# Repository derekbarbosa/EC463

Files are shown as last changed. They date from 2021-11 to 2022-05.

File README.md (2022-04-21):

<div align="center">

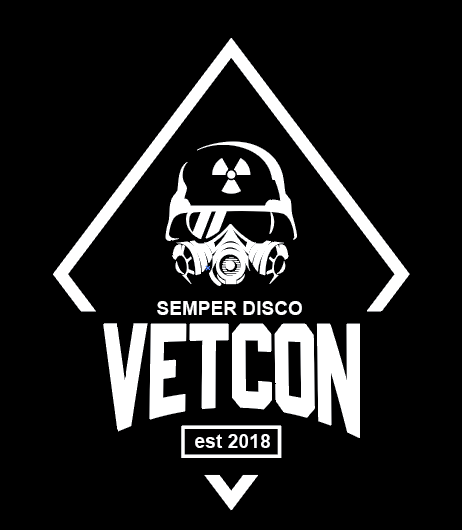
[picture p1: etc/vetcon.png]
  
  <h1> :skull: VETCON BADGE :skull: </h1>
  
  <p>
    TEAM 32 <span> · </span>2021-2022  
  </p>
  <p>
  SEMPER DISCO
  </p>

<!-- Badges -->
<p>
  <a href="https://github.com/derekbarbosa/EC463/graphs/contributors">
    
  </a>
  <a href="">
    
  </a>
  <a href="https://github.com/derekbarbosa/EC463/network/members">
    
  </a>
  <a href="https://github.com/derekbarbosa/EC463/issues">
    
  </a>
  <a href="https://github.com/derekbarbosa/EC463/blob/main/LICENSE">
    
  </a>
</p>

<h3>
  Quick Links!
</h3>
<h4>
    <a href="PLACEHOLDER">View Demo</a>
  <span> · </span>
    <a href="notes/README_Engineering.md">Quick Start Guide</a>
  <span> · </span>
    <a href="notes/README_HARDWARE.md">Hardware Guide</a>
  <span> · </span>
    <a href="notes/README_SOFTWARE.md">Software Guide</a>
</h4>

</div>

<br />

<!-- Table of Contents -->
# :notebook_with_decorative_cover: Table of Contents

- [:notebook_with_decorative_cover: Table of Contents](#notebook_with_decorative_cover-table-of-contents)
  - [:star2: About the Project](#star2-about-the-project)
    - [:label: Current Directory Structure](#label-current-directory-structure)
    - [:camera: Screenshots](#camera-screenshots)
    - [:space_invader: Tech Stack](#space_invader-tech-stack)
    - [:dart: Features](#dart-features)
      - [Embedded](#embedded)
      - [Minigames](#minigames)
  - [:toolbox: Getting Started](#toolbox-getting-started)
    - [:running: Quick(ly) Start!](#running-quickly-start)
  - [:eyes: Usage](#eyes-usage)
  - [:warning: License](#warning-license)
  - [:handshake: Contact](#handshake-contact)
  - [:gem: Acknowledgements](#gem-acknowledgements)

<!-- About the Project -->
## :star2: About the Project

### :label: Current Directory Structure
<a href="pcb/">pcb</a> – All PCB/eCAD files and schematics. Includes manufacturing .gbr files

<a href="enclosures/">enclosures</a> – All CAD files and schematics for the PCB enclosure. 

<a href="platformio/">platformio</a> – All code/firmware files concerning the MSP430 development board

<a href="notes/">notes</a> – Inital interview notes, MSP Documentation, useful infographics, additional READMEs

<a href="minigames/">minigames</a> – All code regarding Games 1, 2, and 3 (with CMake Files)

<a href="reports/">reports</a> – All previous reports for the 2021-2022 semester

<a href="derek/">derek</a> – Derek's personal folder for logbook maintenance

<a href="kircher/">kircher</a> – John's personal folder for logbook maintenance

<a href="etc/">etc</a> – Asset storage (logos, etc.)

<!-- Screenshots -->
### :camera: Screenshots

<div align="center"> 
  <p> PlatformIO VSCode Plugin "Home" Page </p>
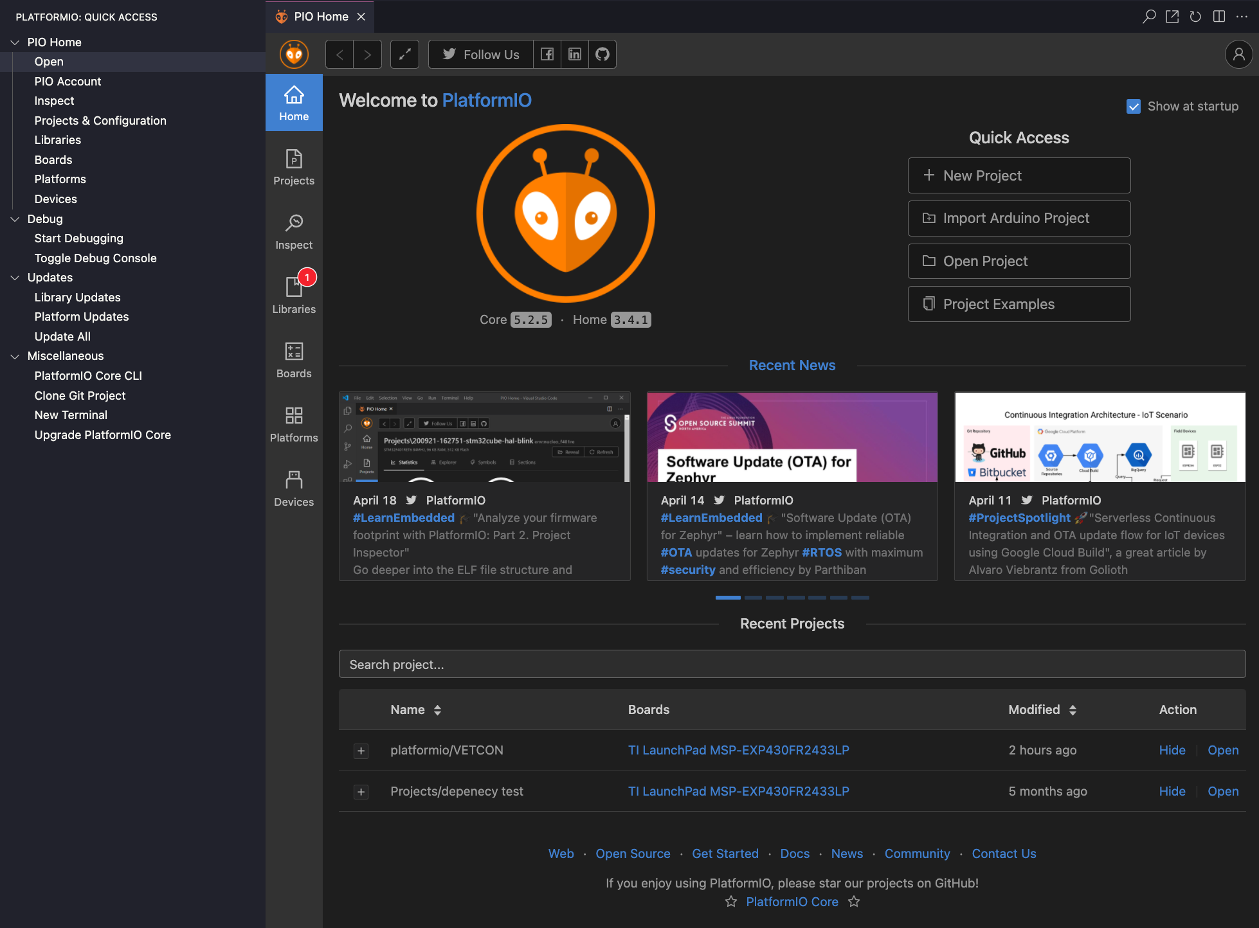
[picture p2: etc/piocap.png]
PIO Home Page
  
</div>

<div align="center"> 
  <p> Sample Terminal Menu via Serial </p>
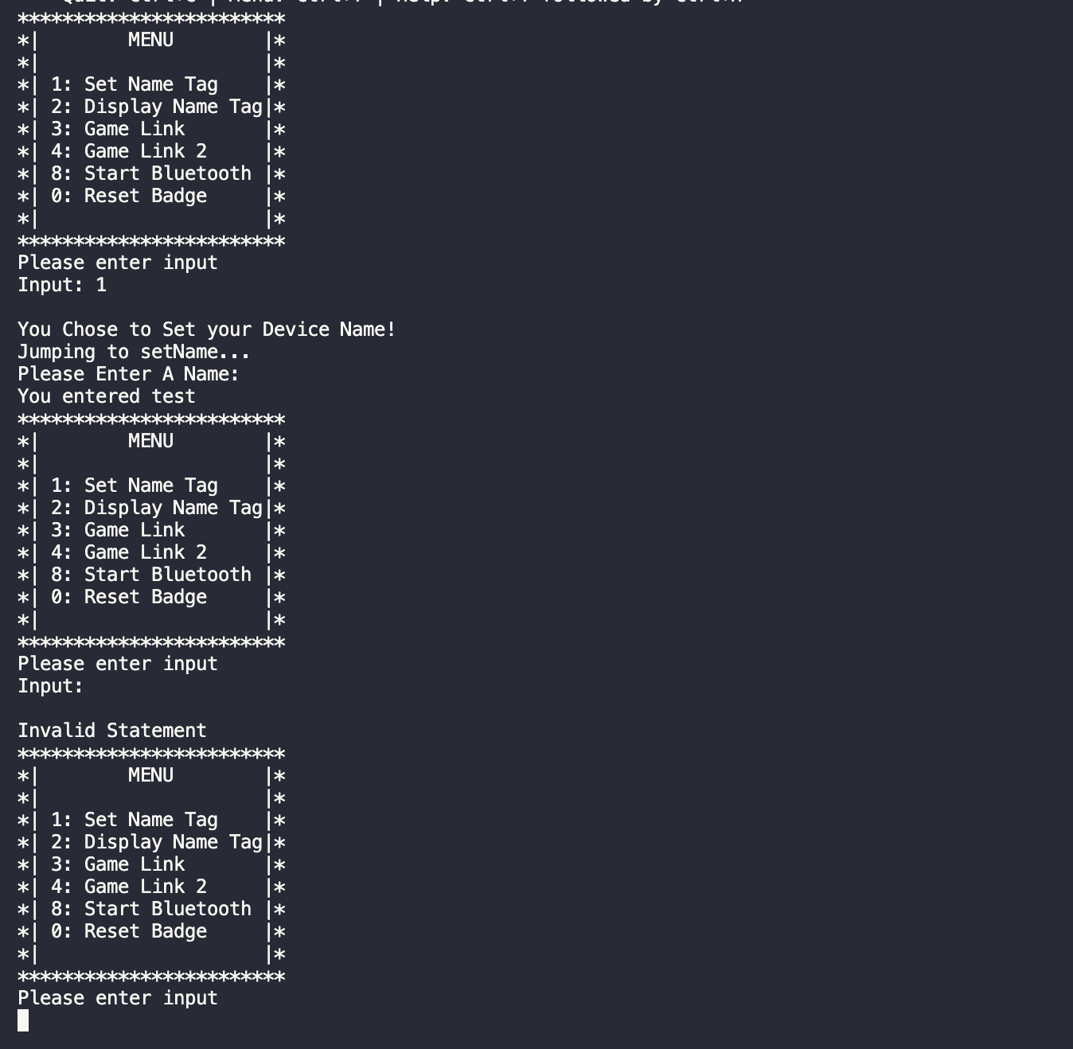
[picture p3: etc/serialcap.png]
Serial Terminal
  
</div>

<div align="center"> 
  <p> Minigame #1 "Dino Run"</p>
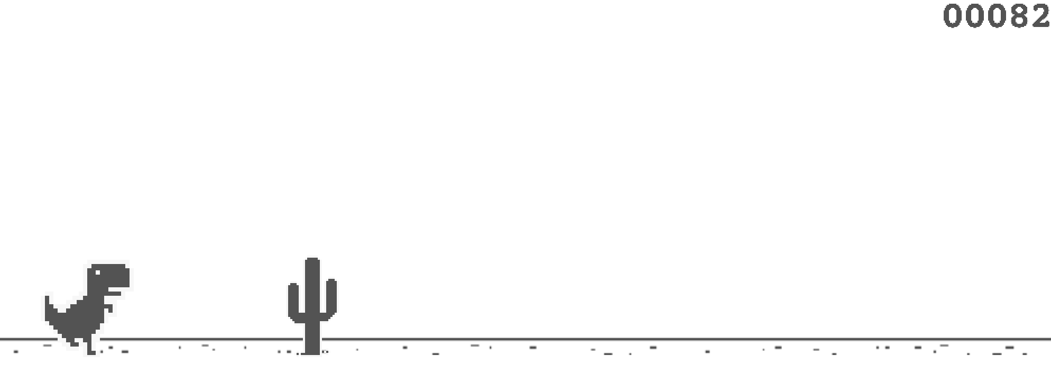
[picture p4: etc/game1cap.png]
Game 1
  
</div>

<div align="center"> 
  <p> Minigame #2 "Coin Flip" </p>
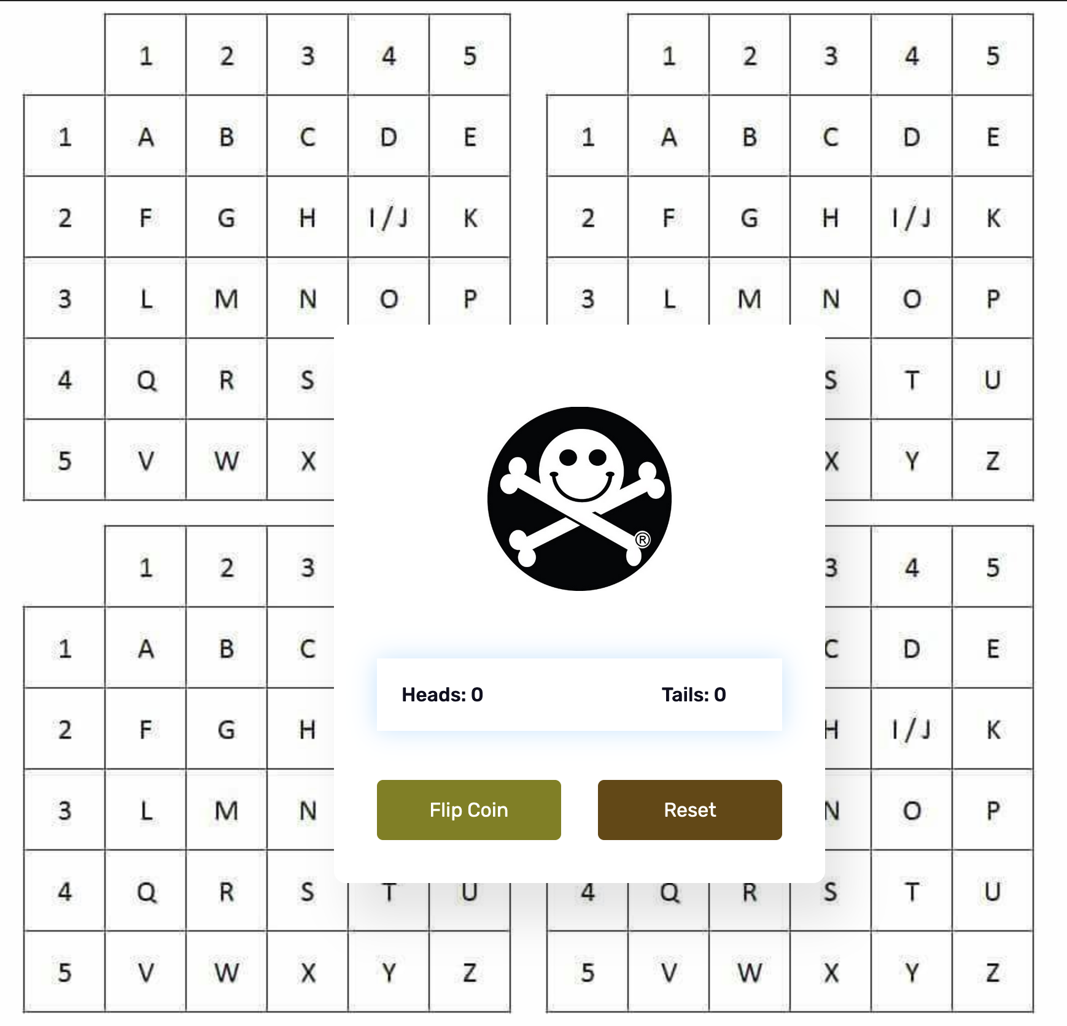
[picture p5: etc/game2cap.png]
Game 2
  
</div>
<div align="center"> 
  <p> Minigame #3 "Text-based adventure" </p>
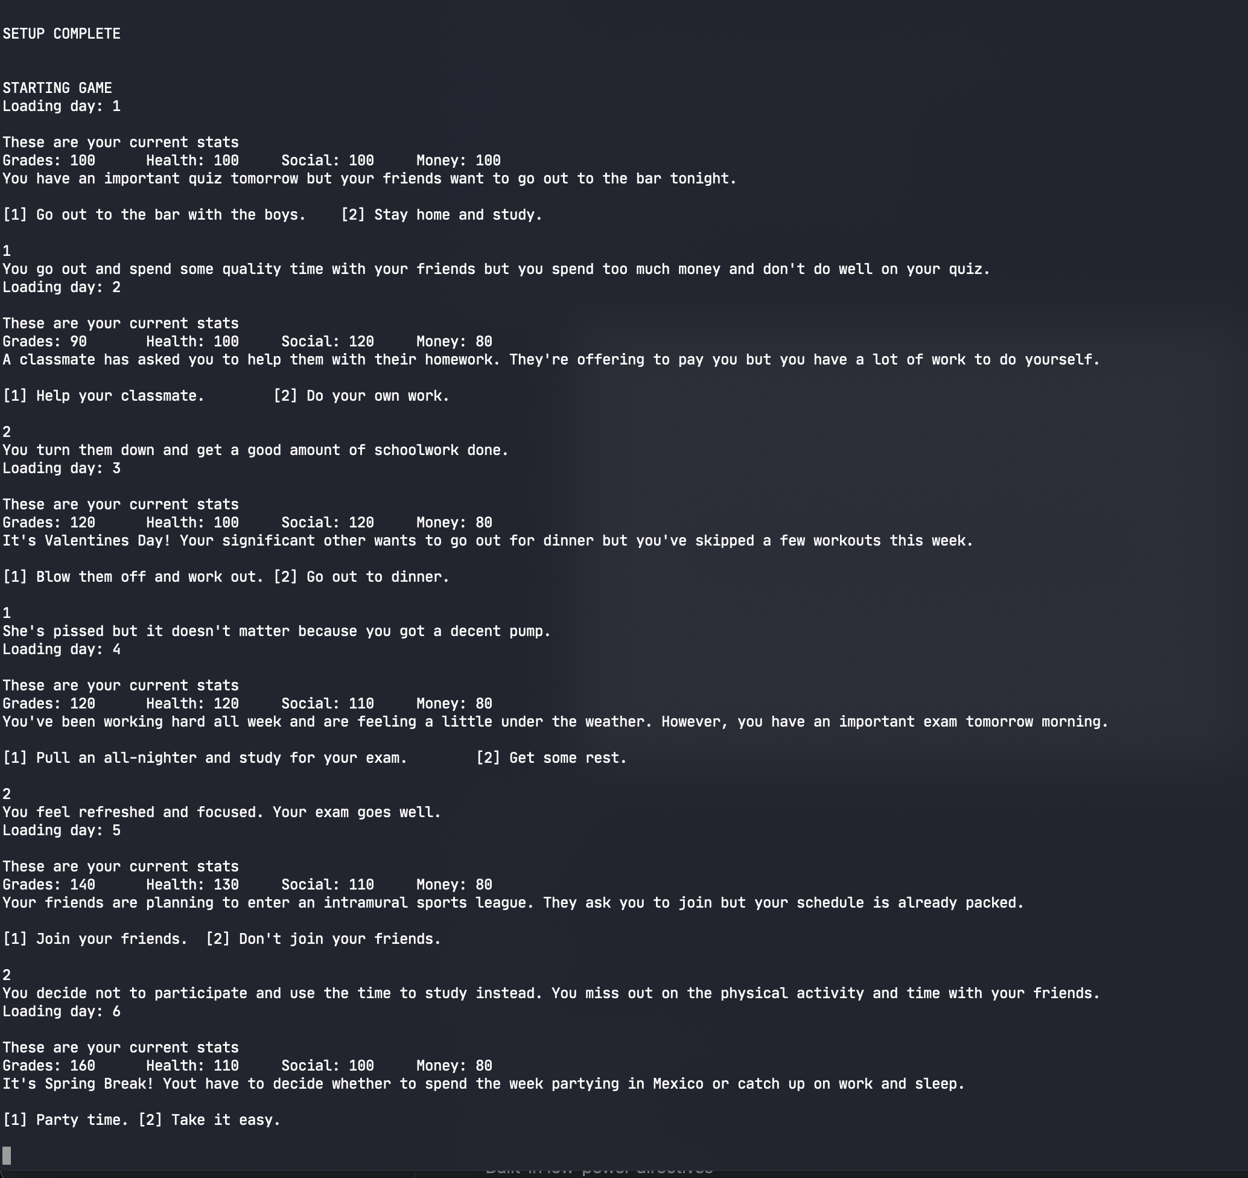
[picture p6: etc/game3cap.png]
Game 3
  
</div>

<!-- TechStack -->
### :space_invader: Tech Stack

<details>
  <summary>Embedded</summary>
  <ul>
    <li><a href="https://www.cplusplus.com/">C++</a></li>
    <li><a href="https://piolabs.com/company/about.html">PIOLabs</a></li>
    <li><a href="PlatformIO">PlatformIO</a></li>
    <li><a href="https://sourceforge.net/projects/mspgcc/">GCC Toolchain for MSP430 by TI</a></li>
    <li><a href="https://energia.nu/reference/">Energia Wiring-based Framework</a></li>
    <li><a href="https://registry.platformio.org/tools/platformio/tool-dslite">Uniflash Flash Tool for TI MCUs</a></li>
    <li><a href="http://wiring.org.co/">Wiring MCU Framework</a></li>
  </ul>
</details>

<details>
  <summary>Minigames</summary>
  <ul>
    <li><a href="https://phaser.io/">Phaser</a></li>
    <li><a href="https://webpack.js.org/">Webpack</a></li>
    <li><a href="https://www.typescriptlang.org/">Typescript</a></li>
    <li><a href="https://enable3d.io/">Enable3D</a></li>
    <li><a href="https://www.javascript.com/">Javascript</a></li>
    <li><a href="https://developer.mozilla.org/en-US/docs/Glossary/HTML5">HTML5</a></li>    
    <li><a href="https://cmake.org/">CMake</a></li>
  </ul>
</details>

<!-- Features -->
### :dart: Features

#### Embedded
- Interactive Shell/Terminal "UI"
- Customizeable
- Built-in LED Toggles
- Bluetooth Capable!
- Built-in low-power directives

#### Minigames
<details>
<summary> Game 1 </summary>
<ul>
<li> Interactive 'runner' game </li>
<li> Obfustication of source using Webpack and Babel for compilation</li>
<li> Hidden 'secrets' ;) </li>
</ul>
</details>
<details>
<summary> Game 2 </summary>
<ul>
<li> Interactive UI elements</li>
<li> Fluid animation using CSS! </li>
<li> Lightweight in-line JS </li>
<li> Built-in cookie storage and retrieval</li>
<li> Hidden 'secrets' ;) </li>
</ul>
</details>
<details>
<summary> Game 3</summary>
<ul>
<li> Interactive decision-based RPG-like text adventure </li>
<li> Open-ended Game Engine with Global Update features for future development and hackability </li>
<li> Text Engine incorporated at Compile-Time with simple .tsv formatting </li>
<li> Built-in undetectable "malware" with std::Threads </li>
<li> Hidden 'secrets' ;) </li>
</ul>
</details>

<!-- Getting Started -->
## 	:toolbox: Getting Started

<!-- Run Locally -->
### :running: Quick(ly) Start!

Clone the project

```bash
  git clone https://github.com/derekbarbosa/EC463.git
```

Then refer to the Quick Start Guide in its entirety! :)
[Quick Start Guide](notes/README_Engineering.md)

<!-- Usage -->
## :eyes: Usage

For a more detailed breakdown of the software components, how they work, how to implement them and how to expand on them, please refer to the [Software Guide](./notes/README_SOFTWARE.md)

For notes and explanation regarding hardware, building a functional breadboard prototype, understanding the modularity of several components, and PCB breakdown, please refer to the [Hardware Guide](./notes/README_HARDWARE.md)

<!-- License -->
## :warning: License

Distributed under the GNU GPL v3 LICENSE. See  <a href="https://www.github.com/derekbarbosa/EC463/blob/main/LICENSE">LICENSE.TXT</a> for more information.

<!-- Contact -->
## :handshake: Contact

<h4>Client</h4>

Mike Jones - jonesmlr (AT) gmail (dot) com

<h4> Team Members </h4>

<br> Derek Barbosa - dbarbosa (AT) bu (dot) edu </br>
<br> Ryan Sullivan - ryanbs (AT) bu (dot) edu </br>
<br> John Kircher - kircherj (AT) bu (dot) edu </br>
<br> Julian Padgett - jpadgett (AT) bu (dot) edu </br>
<br> Carlos Ortiz - cartex10 (AT) bu (dot) edu </br>

<br> Project Link: [https://github.com/derekbarbosa/EC463](https://github.com/derekbarbosa/EC463) </br>

<!-- Acknowledgments -->
## :gem: Acknowledgements

Some shout-outs, acknowledgements and resources!

 - [Shields.io](https://shields.io/)
 - [Awesome README](https://github.com/matiassingers/awesome-readme)
 - [Emoji Cheat Sheet](https://github.com/ikatyang/emoji-cheat-sheet/blob/master/README.md#travel--places)
 - [Make your own Dino Chrome Game!](https://www.youtube.com/watch?v=VOtZ6yNqH84)
 - [Using a 16x2 LCD with Arduino](https://www.makerguides.com/character-lcd-arduino-tutorial/)
 - [Making a Coin Toss Game](https://www.foolishdeveloper.com/2021/10/coin-flip-game-using-javascript.html)

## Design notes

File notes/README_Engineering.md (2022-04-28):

<div align=center>
<h1> :skull: VETCON BADGE :skull: <br/>
:stopwatch:  Quick Start Guide :athletic_shoe:</h1>
<h3> For the full manuals, please view the following: </h3>
<h4>
<h4>
    <a href="./README_HARDWARE.md">Hardware Guide</a>
  <span> · </span>
    <a href="./README_SOFTWARE.md">Software Guide</a>
</h4>

</div>

# :notebook_with_decorative_cover: Table of Contents
- [:notebook_with_decorative_cover: Table of Contents](#notebook_with_decorative_cover-table-of-contents)
  - [:star: About this Guide](#star-about-this-guide)
  - [:gear: Prerequisites](#gear-prerequisites)
  - [:computer: Software Components](#computer-software-components)
    - [:one: Microcontroller Code](#one-microcontroller-code)
    - [:two: Game 1](#two-game-1)
    - [:three: Game 2](#three-game-2)
    - [:four: Game 3](#four-game-3)
  - [:hammer: Hardware Components](#hammer-hardware-components)
    - [:one: PCB Schematics](#one-pcb-schematics)
    - [:two: Fabrication Files](#two-fabrication-files)
  - [:memo: Some Notes](#memo-some-notes)

## :star: About this Guide
<h5> THIS GUIDE IS INTENDED TO BE PURELY A 'QUICK START' GUIDE TO GET YOU UP AND RUNNING </h5>
<h5> PLEASE USE THE INCLUDED MANUALS AS A 'FULL' REFERENCE FOR DEPLOYMENTS, BUILDS, ETC.</h5>

## :gear: Prerequisites
1. Have a working [MSP-EXP430FR2433](https://www.ti.com/tool/MSP-EXP430FR2433) development board (complete with MicroUSB to USB-A cable).
a. Alternatively, have a [Wiring Framework](http://wiring.org.co/) compatible board that is listed on [PlatformIO's supported board list](https://registry.platformio.org/search?t=platform&f=arduino&p=1) and is cross-compile compatible with the [Arduino](https://www.arduino.cc/en/software) or [Energia](https://energia.nu/) IDEs.
2. Download and install the [PlatformIO Toolchain](https://platformio.org/platformio-ide) via VSCode Extension (recommended).
   1. It would be wise to read up on some of the documentation and get your own "Hello World" going to faciltate the rest of this guide!
3. Have this repo cloned ```git clone https://github.com/derekbarbosa/EC463```
   1. This repo houses everything you need for all components of the project. If you don't have it locally on your machine, now would be a good time to have it downloaded.
4. If on Windows or any other non **nix*-based OS, have PuTTY (or your terminal emulator of choice) installed and ready to connect via serial (9600-ish baud). 
5. Download and Install [KiCad](https://www.kicad.org/download/) (recommended) or any eCAD software of your choice.
## :computer: Software Components

### :one: Microcontroller Code 
<h5> i.e. The stuff that runs on the board</h5>

- Connect your MSP (or whatever board you have) to the computer where you will building the code from
- Ensure you are able to communicate with your USB-connected device via serial (baud 9600)
  - [Helpful Resource](https://learn.sparkfun.com/tutorials/terminal-basics/connecting-to-your-device)
- Open a VSCode Window, if you have the PlatformIO plugin you should be able to see it on the left navigation bar
  - Click the Icon, it should take you to the PlatformIO splash screen, also known as "PIO HOME"
- Select the "Open a Project" option
- Navigate to the root of the downloaded Github repo
  - Select the platformIO folder, then select the VETCON folder
  - Click "open" to finalize your selection
- Click the extension icon again
- Select the "Build and Monitor" option on the left navigation bar of the PlatformIO extension
- Follow the provided prompts
  
:star2: SUCCESS! :star2:
You have now succesfully built the MCU code and are now monitoring your dev board via serial!
Interact with the "Shell" and navigate the program

### :two: Game 1
<h5> Dino Run </h5>

- Navigate to the [dino_run](../minigames/dino_run/) folder
- Install the package dependencies via NPM ``` npm install ``` or Yarn ``` yarn install ```
- View options available via npm by typing it into your terminal ``` npm run``` or ``` yarn run```
- Run the game locally via ```npm run serve``` or ```npm run start``` or the equivalent with ``` yarn ```
- Navigate to the proper localhost port
- Play the game :)

:star2: SUCCESS! :star2:
You have now succesfully built the dino run code!

### :three: Game 2
<h5> Coin Flip </h5>

- Navigate to the [coin_flip](../minigames/coin_flip) folder
- Launch the .HTML file
- Voila!

:star2: SUCCESS! :star2:
You have now succesfully built the coin flip code!

### :four: Game 3
<h5> Text-based Adventure</h5>

- Navigate to the [text_based](../mingames/text_based) folder
- Run the "make" bash script to trigger the CMake Build Rules ``` ./make ```
- Run the built game ``` ./game ```
- Play the game
- Cleanup when finished using the "clean" script ```./clean```

:star2: SUCCESS! :star2:
You have now succesfully built the text based code!

## :hammer: Hardware Components

### :one: PCB Schematics
- Navigate to the [pcb](../pcb/) folder in the root of the repository
- Open the .PRO file with KiCad
- Select from any of the options presented (PCB Viewer, Schematic Viewer, Footprint Viewer, etc.)

### :two: Fabrication Files
- Within the pcb folder, navigate to the [fab_files](../pcb/fab_files/) folder
- View/Open the Gerber (.gbr) or Drill (.drl) files with your eCAD software of choice

## :memo: Some Notes
If you'd like to continue this project, you might want to [fork](https://docs.github.com/en/get-started/quickstart/fork-a-repo) OR [duplicate](https://docs.github.com/en/repositories/creating-and-managing-repositories/duplicating-a-repository) this repository rather than attempting to push your own commits/do a pull request. This way, you get to have as much creative freedom with the code as you desire (obviously respecting the GNU GPL v3 license).

We intend to keep this repo as-is in a "finished" state. 

If you do have any questions, or make any cool developments/improvements that you would like to let us know about! Feel free to shoot us an email with the header: [GH EC463] + your name - {subject}

Happy hunting :)

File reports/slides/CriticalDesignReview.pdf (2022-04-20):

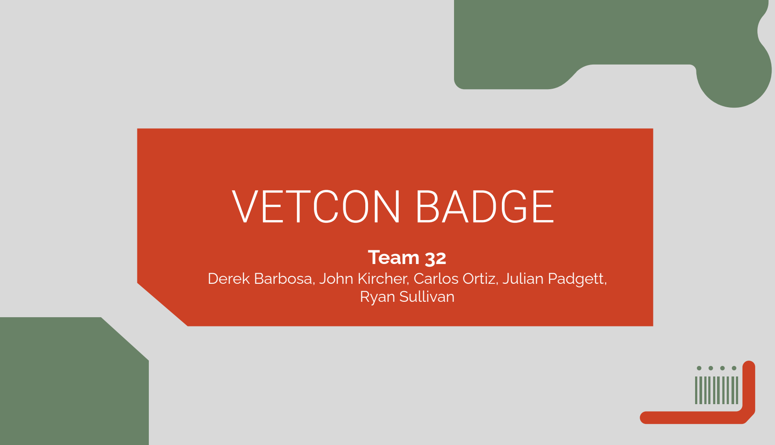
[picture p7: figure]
VETCON BADGE; Team 32; Ryan Sullivan

Derek Barbosa, John Kircher, Carlos Ortiz, Julian Padgett,

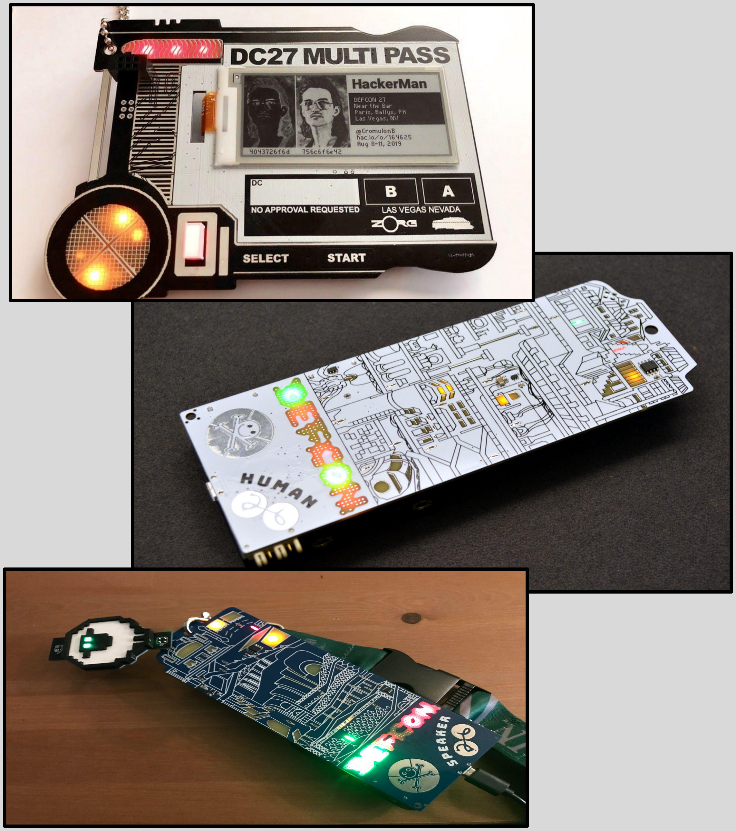
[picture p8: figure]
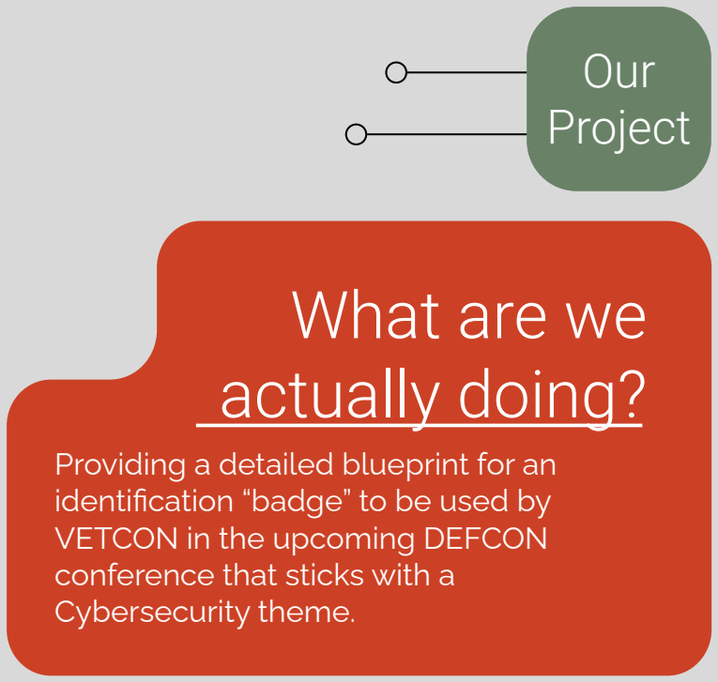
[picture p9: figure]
What are we actually doing?; Providing a detailed blueprint for an identification “badge” to be used by VETCON in the upcoming DEFCON conference that sticks with a Cybersecurity theme.; Our Project
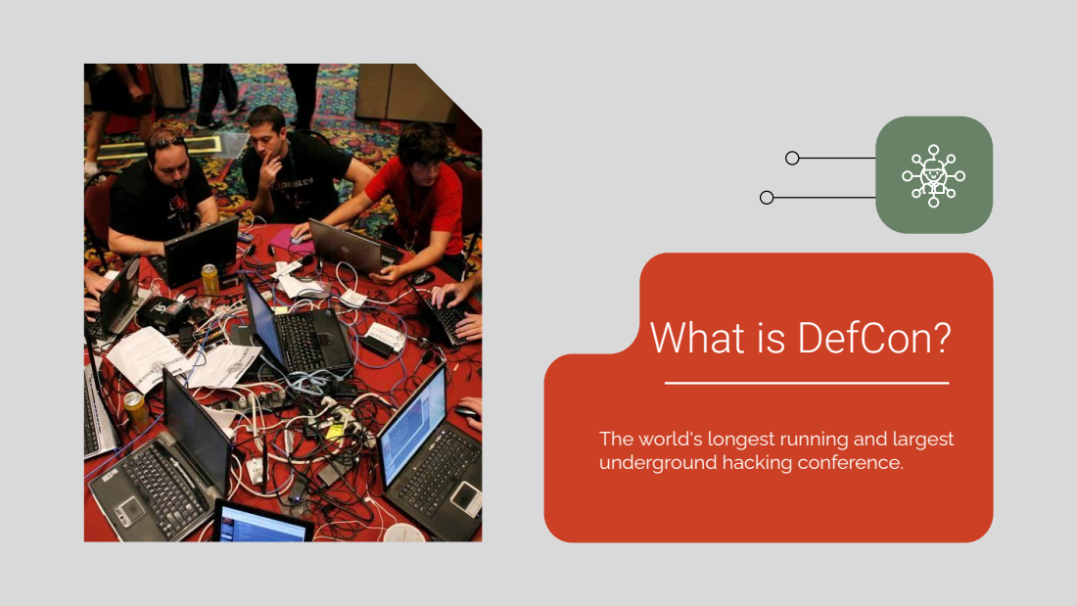
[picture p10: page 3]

What is DefCon?

The world's longest running and largest
underground hacking conference.

# Deliverables

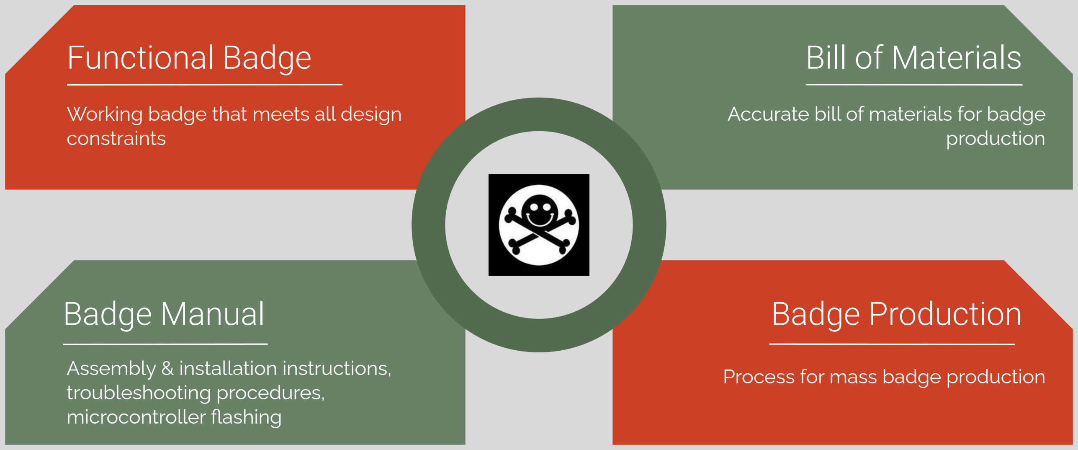
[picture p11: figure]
Functional Badge; Working badge that meets all design constraints; Badge Manual; Assembly & installation instructions, troubleshooting procedures, microcontroller flashing; Badge Production; Process for mass badge production; Bill of Materials; Accurate bill of materials for badge production

Provide users with easy communication with other badges users

### Communication

Easy but rewarding construction of badges

### Construction

An affordable price for those hoping to order a badge

### Cost & Production

# Badge Functions

# Requirements: Functions

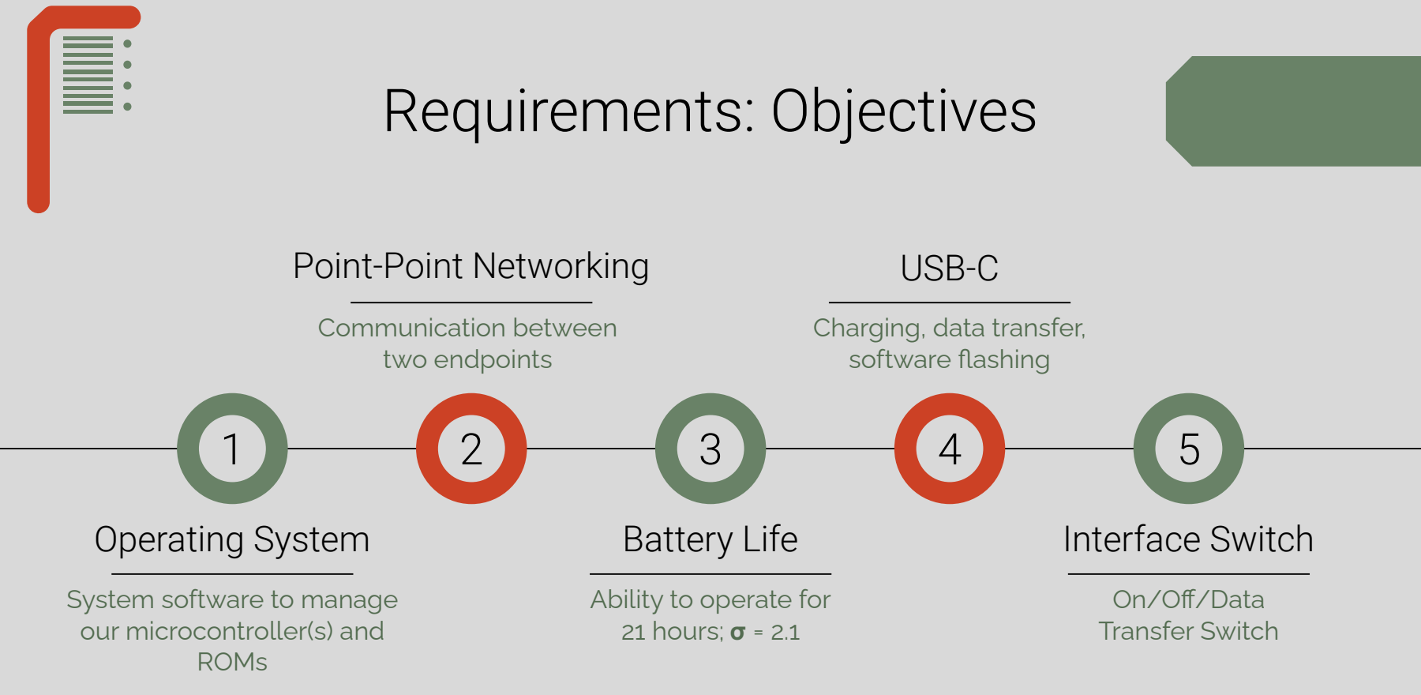
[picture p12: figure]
System software to manage our microcontroller(s) and ROMs; Operating System; On/Off/Data Transfer Switch; Interface Switch; Ability to operate for 21 hours; σ = 2.1; Battery Life; Communication between two endpoints; Point-Point Networking; Charging, data transfer, software flashing; USB-C; Requirements: Objectives

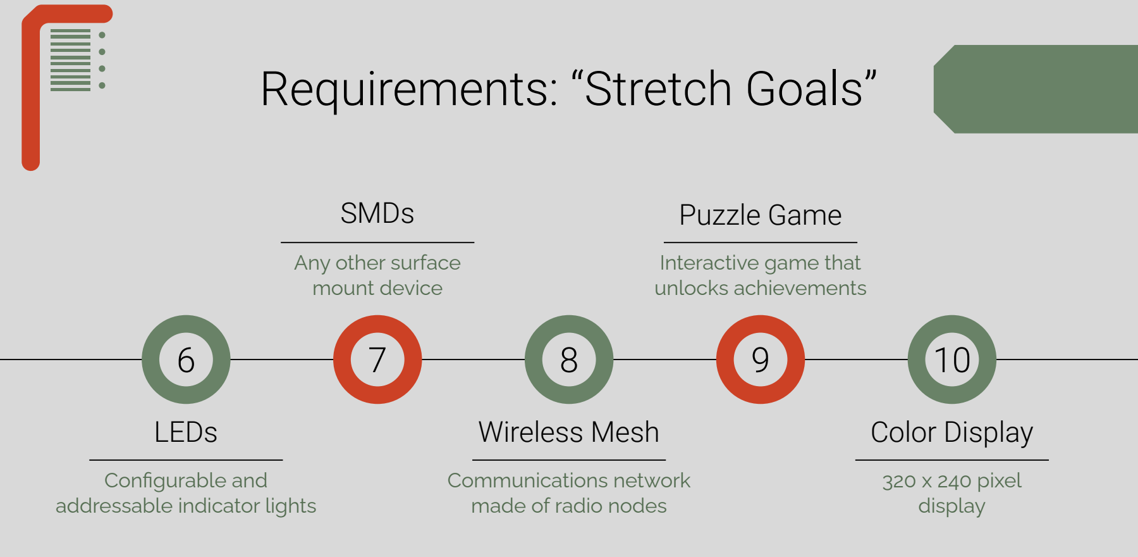
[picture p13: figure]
Configurable and addressable indicator lights; LEDs; 320 x 240 pixel display; Color Display; Communications network made of radio nodes; Wireless Mesh; Any other surface mount device; SMDs; Interactive game that unlocks achievements; Puzzle Game; Requirements: “Stretch Goals”

# Requirements: Constraints

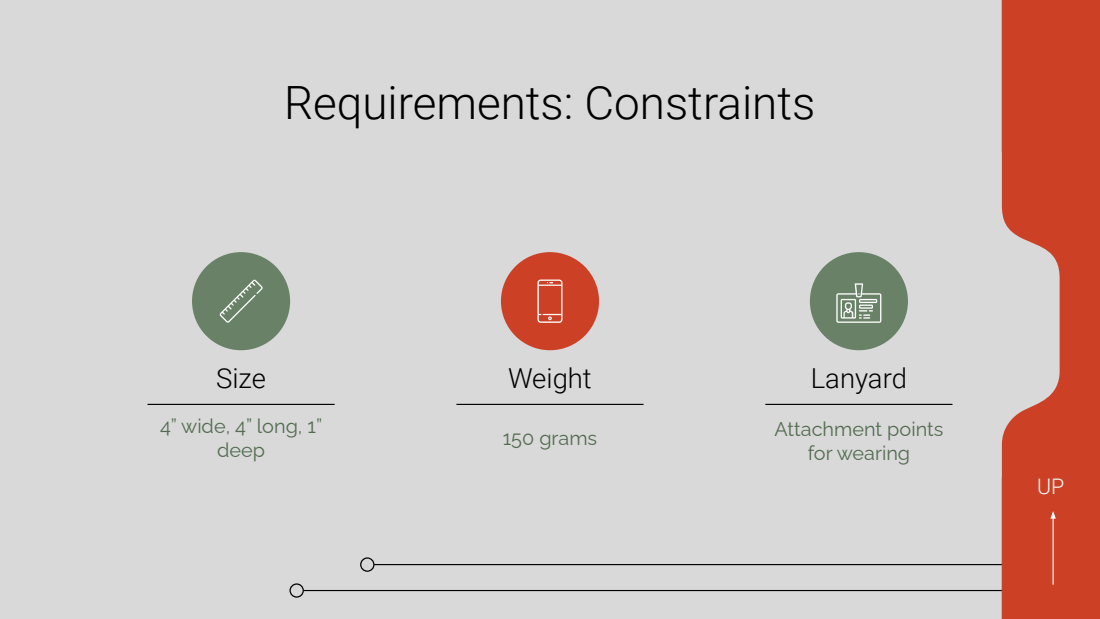
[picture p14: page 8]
Size; 4” wide, 4” long, 1” deep; Lanyard; Attachment points for wearing; Weight; 150 grams

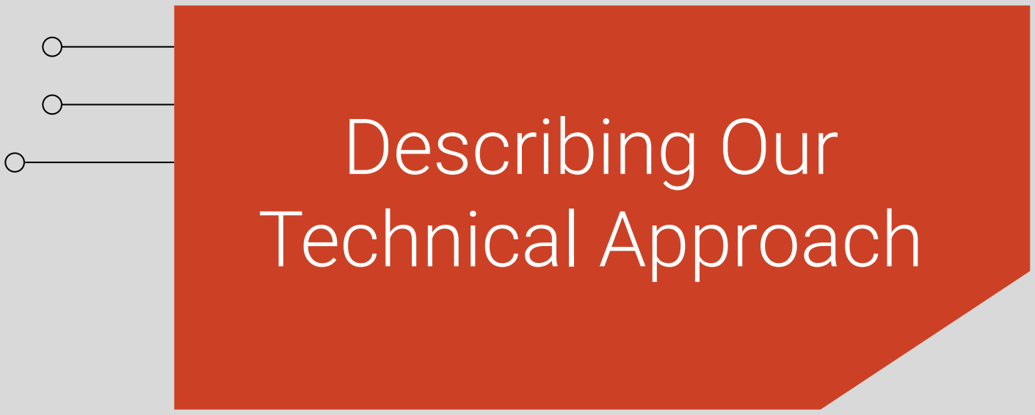
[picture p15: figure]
Describing Our Technical Approach
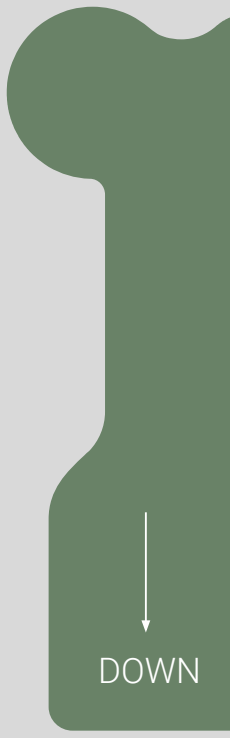
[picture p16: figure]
DOWN

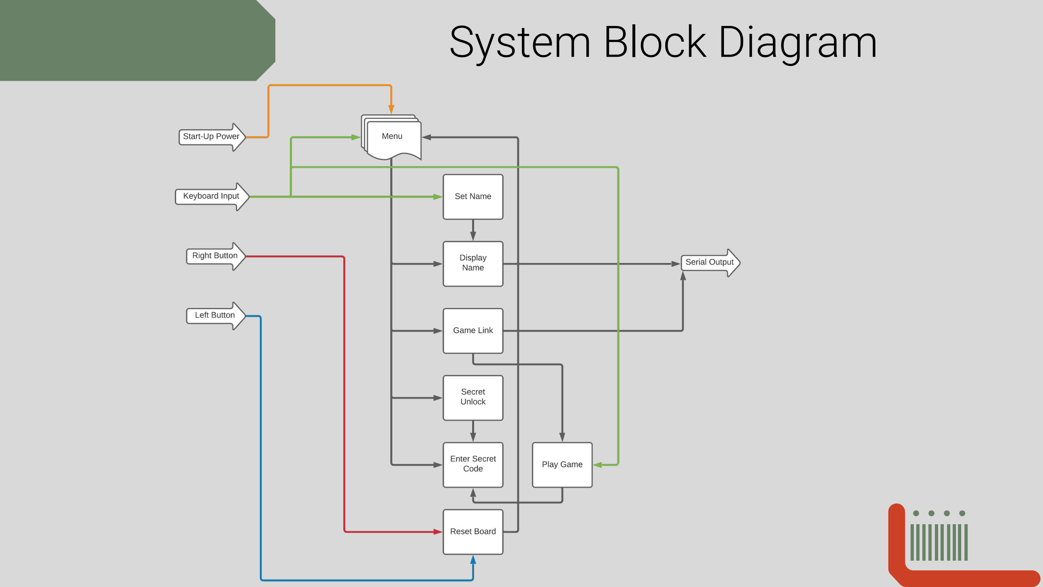
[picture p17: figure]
System Block Diagram

# Game 1 Screenshot

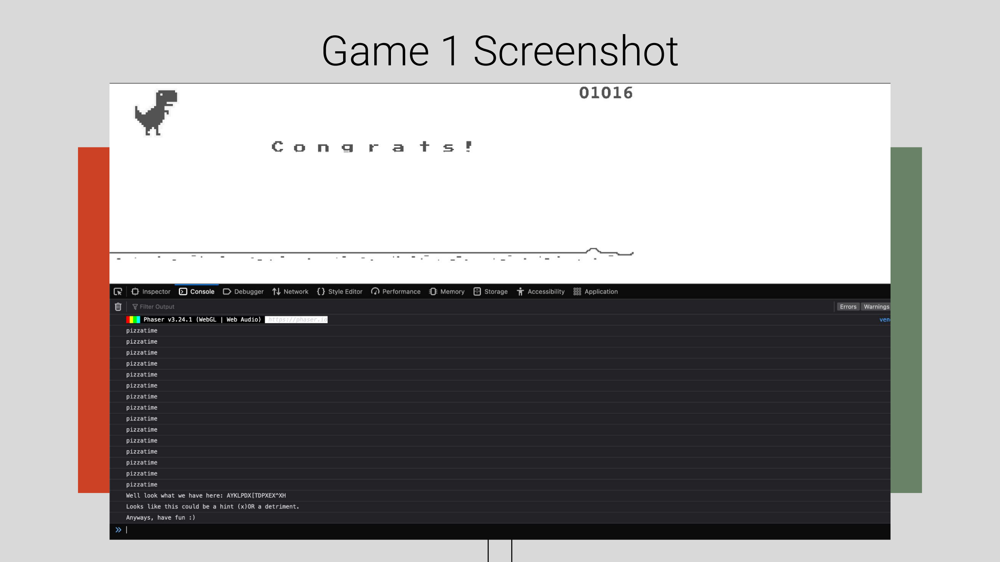
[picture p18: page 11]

# Game 2 Screenshot

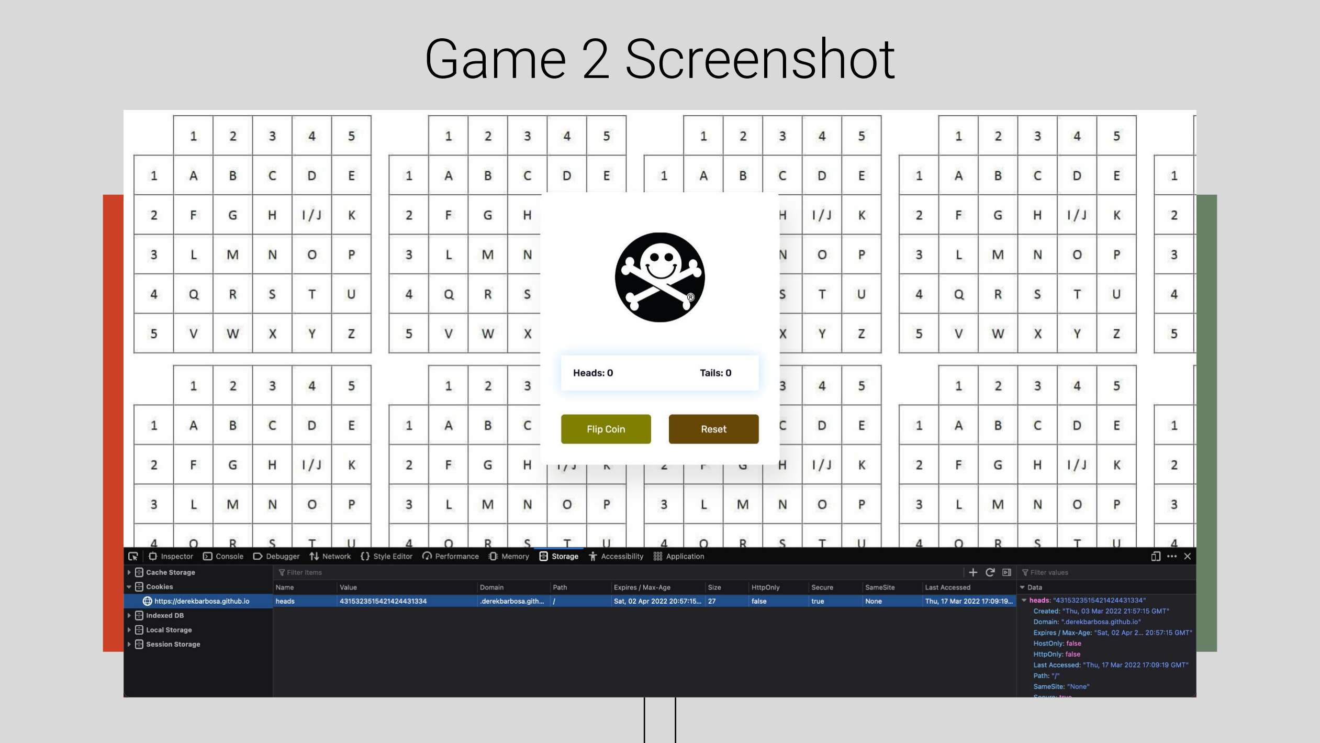
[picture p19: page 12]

# Game 3 Screenshot

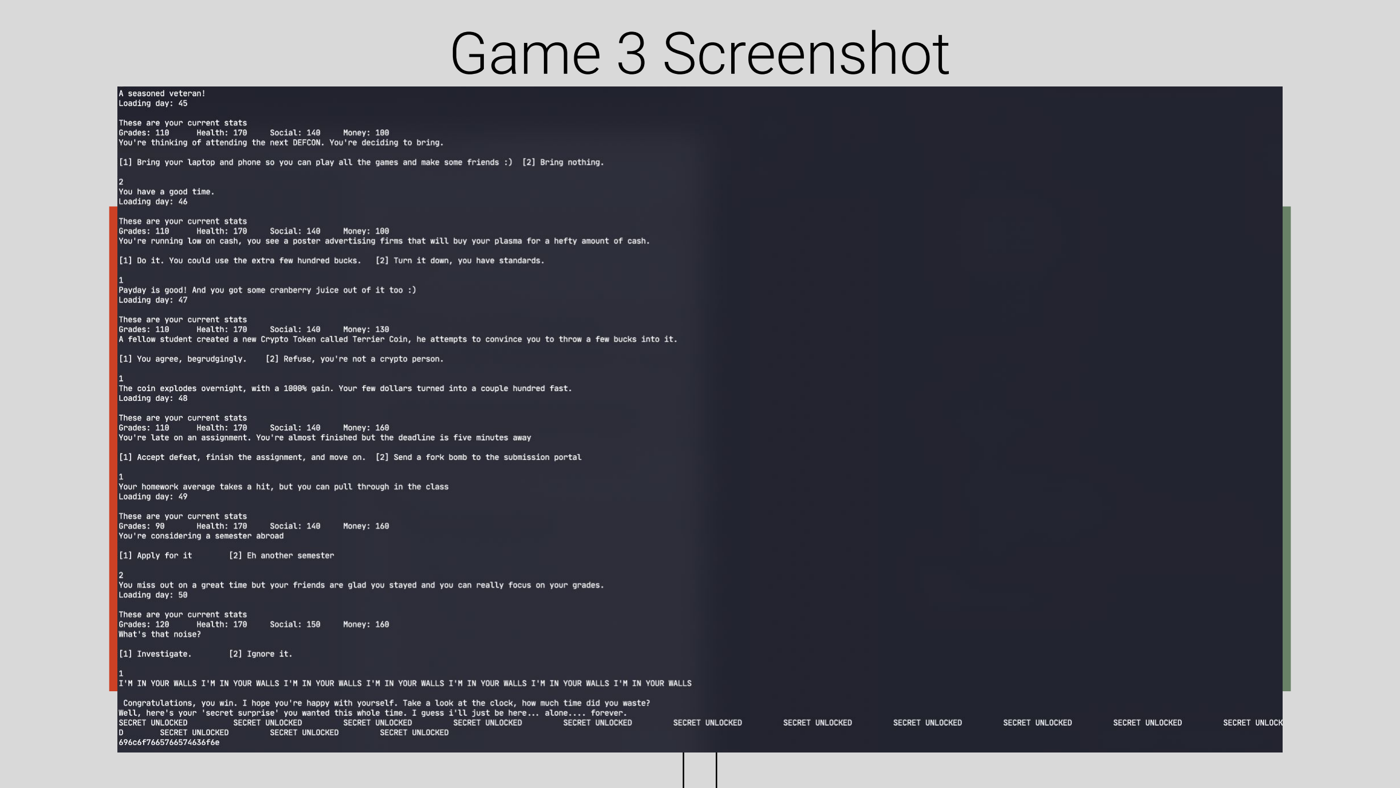
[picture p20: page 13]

# Persistent State

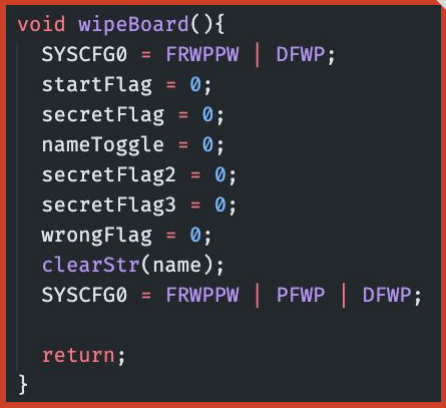
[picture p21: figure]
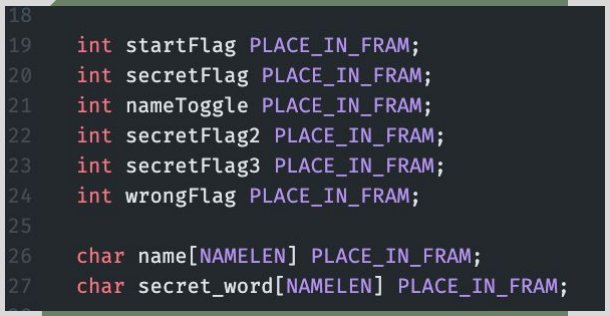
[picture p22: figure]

# Bluetooth

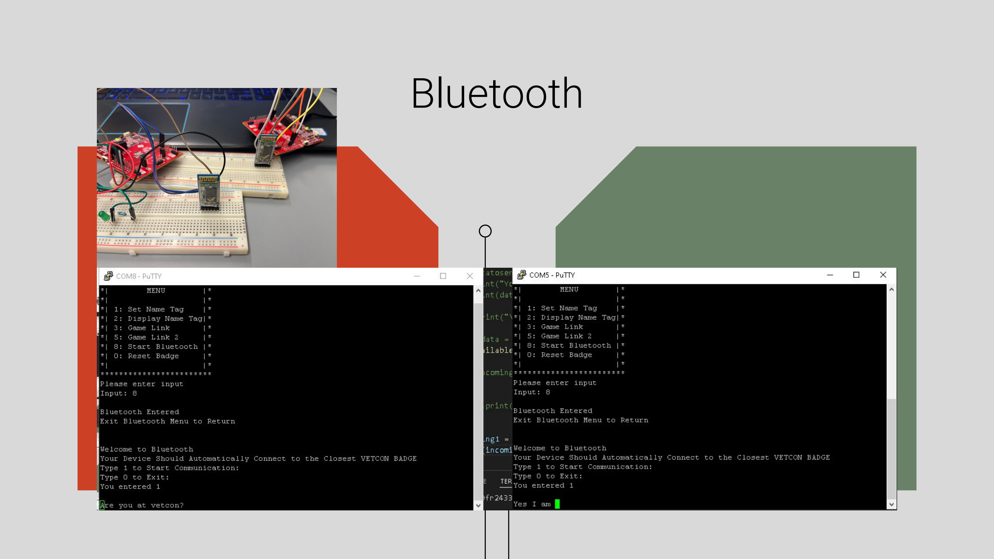
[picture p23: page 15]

# Gantt Chart (predicted)

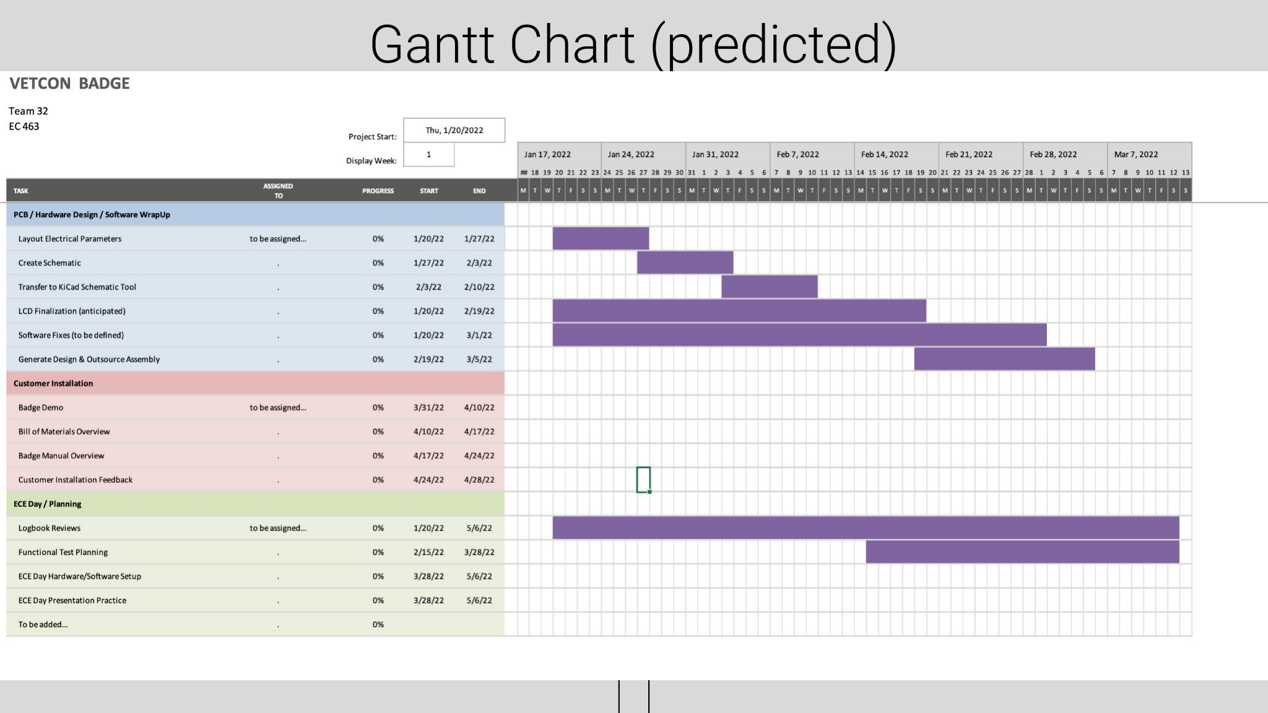
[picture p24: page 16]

# Gantt Chart (actual)

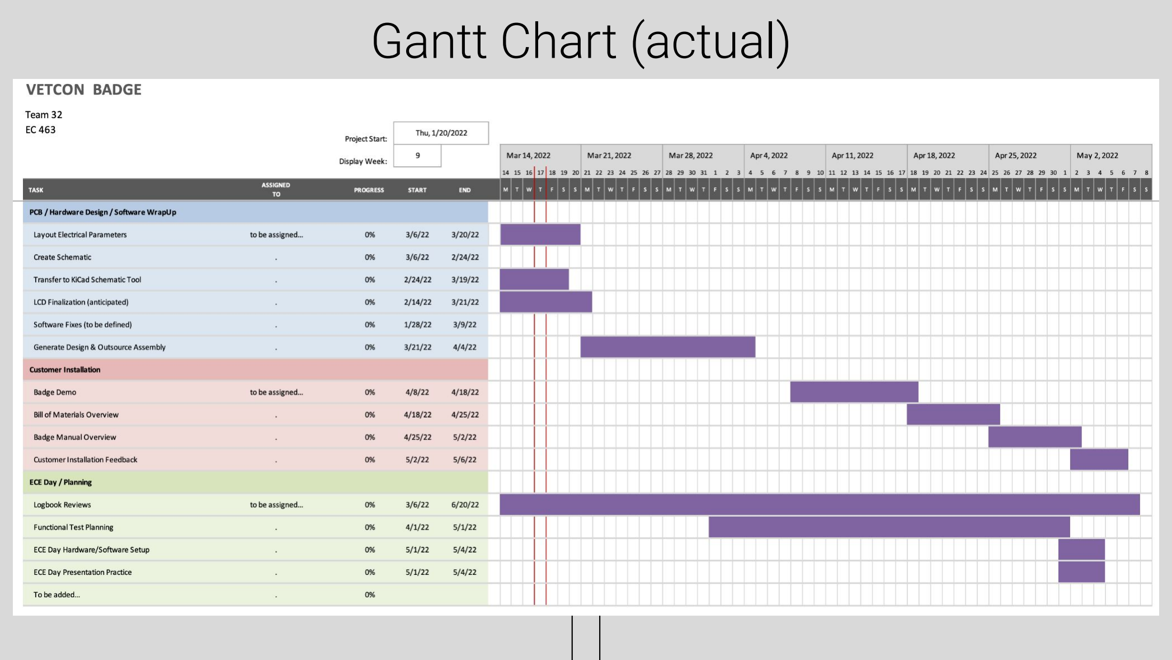
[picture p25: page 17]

# What still needs to be done?

### Requirements

- Have a finished KiCad
schematic
- BT “friending” feature
- 10 prototypes ready for
ECE day
- Full bill of materials
- Board user manual

### Stretch Goals

- Alphanumeric LCD
operational

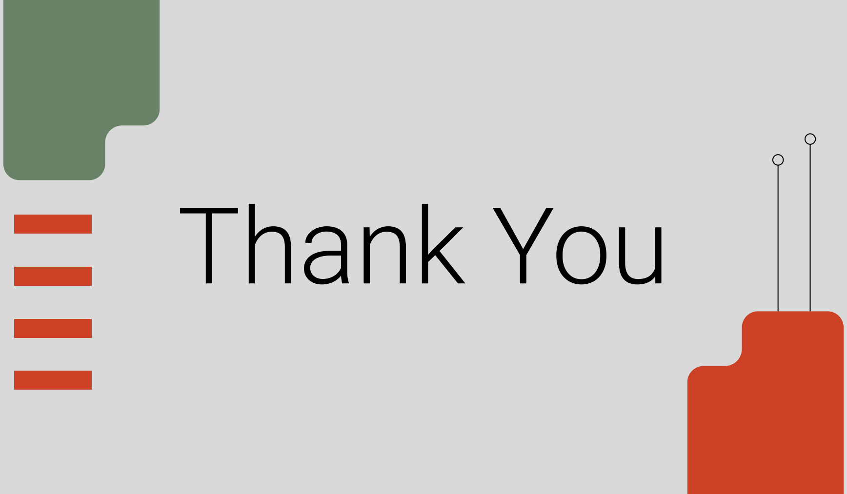
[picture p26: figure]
Thank You

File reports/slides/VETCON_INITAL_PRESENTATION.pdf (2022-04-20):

VETCON BADGE; Team 32; Ryan Sullivan

Derek Barbosa, John Kircher, Carlos Ortiz, Julian Padgett,

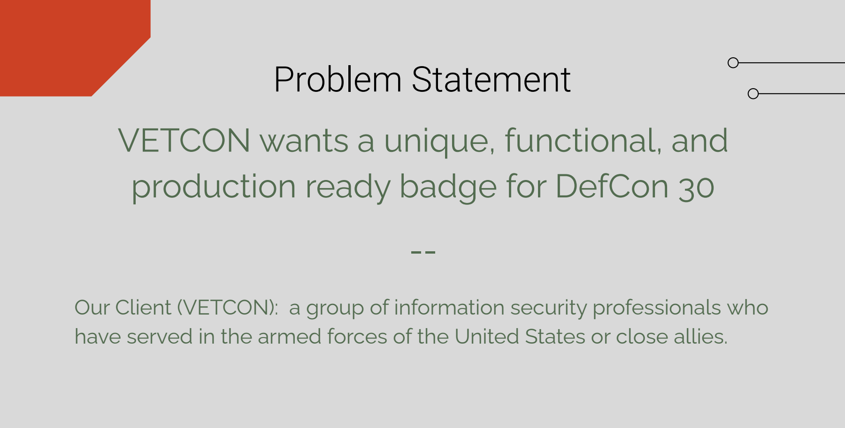
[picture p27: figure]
Problem Statement VETCON wants a unique, functional, and production ready badge for DefCon 30

## Our Client (VETCON): a group of information security professionals who

have served in the armed forces of the United States or close allies.

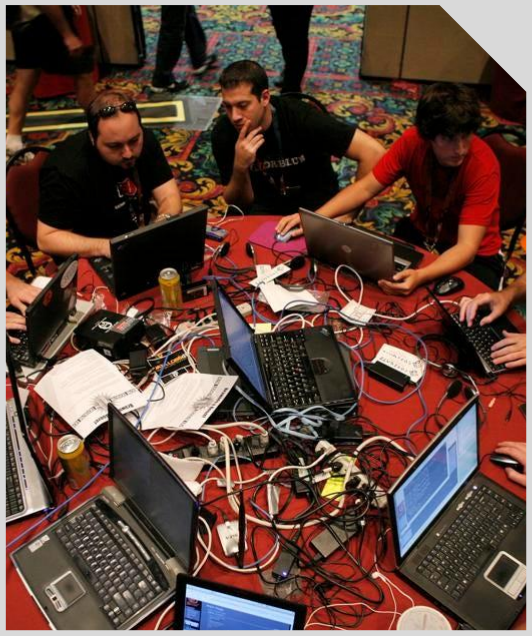
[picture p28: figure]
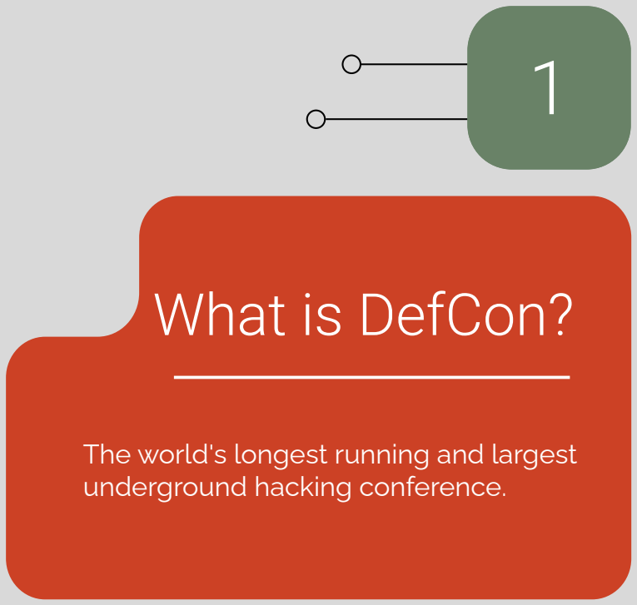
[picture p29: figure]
What is DefCon?; The world's longest running and largest underground hacking conference.

# Badge Examples

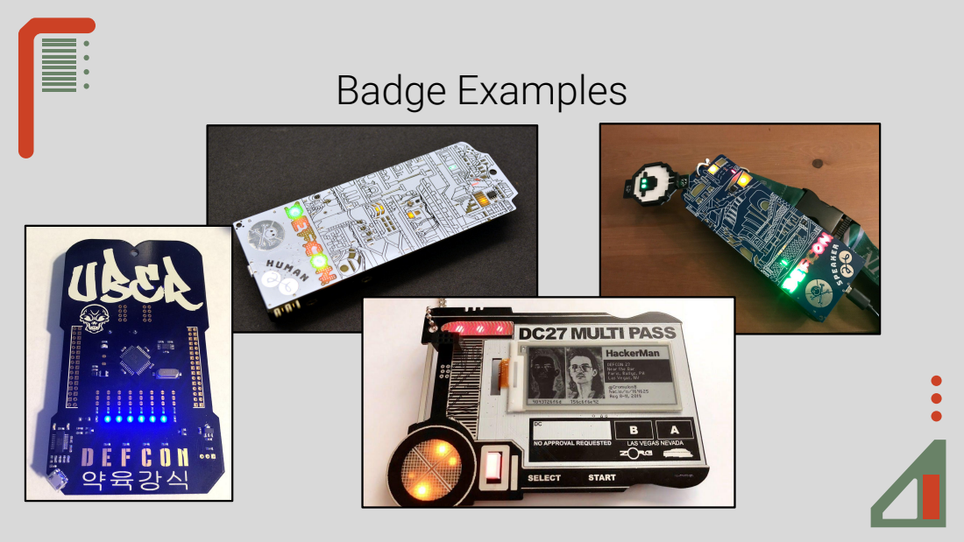
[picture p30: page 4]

# Deliverables

Functional Badge; Working badge that meets all design constraints; Badge Manual; Assembly & installation instructions, troubleshooting procedures, microcontroller flashing; Badge Production; Process for mass badge production; Bill of Materials; Accurate bill of materials for badge production

Provide users with easy communication with other badges users

### Communication

Easy but rewarding construction of badges

### Construction

An affordable price for those hoping to order a badge

### Cost & Production

# Badge Functions

# Requirements: Functions

System software to manage our microcontroller(s) and ROMs; Operating System; On/Off/Data Transfer Switch; Interface Switch; Ability to operate for 21 hours; σ = 2.1; Battery Life; Communication between two endpoints; Point-Point Networking; Charging, data transfer, software flashing; USB-C; Requirements: Objectives

Configurable and addressable indicator lights; LEDs; 320 x 240 pixel display; Color Display; Communications network made of radio nodes; Wireless Mesh; Any other surface mount device; SMDs; Interactive game that unlocks achievements; Puzzle Game; Requirements: “Stretch Goals”

# Requirements: Constraints

Size; 4” wide, 4” long, 1” deep; Lanyard; Attachment points for wearing; Weight; 150 grams

Describing Approaches
DOWN

RIGHT

# Single Board Computers (SBC)

Full-fledged computer that can run desktop/server Operating Systems with support for virtualized I/O & networking


+Extremely flexible
+Dirt Simple programming interface -Power Hungry, need large battery. -Tricky to isolate functionality

# Raspberry pi


# Jetson Nanos

RIGHT

# Bare-Metal MCUs

A “small” Computing Unit that resides on a single IC some ROM dedicated to processing instructions.


+Extremely power efficient
+Very low cost (in the single dollar range)
-Very manual process
-Low on built-in memory. Need ROM & JTAG

# Zilog Z80


# STM8L

RIGHT

# Systems On a Chip (SOC)

An IC that includes “most” circuit components of -a- Computer / Electronic System.

+”Sandboxed” Dev Environment +Rapid Prototyping Capabilities (fast compile)
-Software Suite heavily dependent on Manufacturer.
-Reliant on Community for
implementation

# Arduino Minis


# TI MSP430XXX



Our Decision | LEFT

# Why?

| Best balance between “efficient” and
pliable.
| +Maintains excellent power efficiency +Approachable programming

interface

+Based in the US (faster shipping). TI MSP430

Competing Technologies / Patents / Other Products

Thank You

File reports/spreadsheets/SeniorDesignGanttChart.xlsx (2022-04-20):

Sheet: ProjectSchedule
Create a Project Schedule in this worksheet. Enter title of this project in cell B1. Information about how to use this worksheet, including instructions for screen readers and the author of this workbook is in the About worksheet. Continue navigating down column A to hear further instructions. | VETCON BADGE
Enter Company Name in cell B2. | Team 32
Enter the name of the Project Lead in cell B3. Enter the Project Start date in cell E3. Pooject Start: label is in cell C3. | EC 463 | Project Start: |  | 2022-01-20
The Display Week in cell E4 represents the starting week to display in the project schedule in cell I4. The project start date is considered Week 1. To change the display week, simply enter a new week number in cell E4. The starting date for each week, starting with the display week from cell E4, starts in cell I4 and is auto calculated. There are 8 weeks represented in this view from cell I4 through cell BF4. You should not modify these cells. Display Week: label is in cell C4. |  | Display Week: |  | 1 |  | 2022-01-17 |  |  |  |  |  |  | 2022-01-24 |  |  |  |  |  |  | 2022-01-31 |  |  |  |  |  |  | 2022-02-07 |  |  |  |  |  |  | 2022-02-14 |  |  |  |  |  |  | 2022-02-21 |  |  |  |  |  |  | 2022-02-28 |  |  |  |  |  |  | 2022-03-07
Cells I5 through BL5 contain the day number for the week represented in the cell block above each date cell and are auto calculated. You should not modify these cells. Today's date is outlined in Red (hex #AD3815) from today's date in row 5 through the entire date column to the end of the project schedule. |  |  |  |  |  | 2022-01-17 | 2022-01-18 | 2022-01-19 | 2022-01-20 | 2022-01-21 | 2022-01-22 | 2022-01-23 | 2022-01-24 | 2022-01-25 | 2022-01-26 | 2022-01-27 | 2022-01-28 | 2022-01-29 | 2022-01-30 | 2022-01-31 | 2022-02-01 | 2022-02-02 | 2022-02-03 | 2022-02-04 | 2022-02-05 | 2022-02-06 | 2022-02-07 | 2022-02-08 | 2022-02-09 | 2022-02-10 | 2022-02-11 | 2022-02-12 | 2022-02-13 | 2022-02-14 | 2022-02-15 | 2022-02-16 | 2022-02-17 | 2022-02-18 | 2022-02-19 | 2022-02-20 | 2022-02-21 | 2022-02-22 | 2022-02-23 | 2022-02-24 | 2022-02-25 | 2022-02-26 | 2022-02-27 | 2022-02-28 | 2022-03-01 | 2022-03-02 | 2022-03-03 | 2022-03-04 | 2022-03-05 | 2022-03-06 | 2022-03-07 | 2022-03-08 | 2022-03-09
This row contains headers for the project schedule that follows below them. Navigate from B6 through BL 6 to hear the content. The first letter of each day of the week for the date above that heading, starts in cell I6 and continues through cell BL6. All project timeline charting is auto generated based on the start and end dates entered, using conditional formats. Do not modify content in cells within columns after column I starting with cell I7. | TASK | ASSIGNED TO | PROGRESS | START | END | M | T | W | T | F | S | S | M | T | W | T | F | S | S | M | T | W | T | F | S | S | M | T | W | T | F | S | S | M | T | W | T | F | S | S | M | T | W | T | F | S | S | M | T | W | T | F | S | S | M | T | W
Cell B8 contains the Phase 1 sample title. Enter a new Title in cell B8. Enter a name to assign the phase to, if it applies for your project, in cell C8. Enter Progress for the entire phase, if it applies for your project, in cell D8. Enter the start and end dates for the entire phase, if it applies for your project, in cells E8 and F8. The Gantt chart will automatically fill in the appropriate dates and shade according to the progress entered. To delete the phase and work only from tasks, simply delete this row. | PCB / Hardware Design / Software WrapUp
Cell B9 contains the sample task "Task 1." Enter a new task name in cell B9. Enter a person to assign the task to in cell C9. Enter progres of the task in cell D9. A progress bar appears in the cell and is shaded according to the number in the cell. For example, 50 percent progress would shade half of the cell. Enter task start date in cell E9. Enter task end date in cell F9. A status bar shaded for the dates entered appears in blocks starting from cell I9 through BL9. | Layout Electrical Parameters | to be assigned… | 0% | 2022-01-20 | 2022-01-27
Rows 10 through 13 repeat the pattern from row 9. Repeat the instructions from cell A9 for all task rows in this worksheet. Overwrite any sample data. A sample of another phase starts in cell A14. Continue entering tasks in cells A10 through A13 or go to cell A14 to learn more. | Create Schematic | . | 0% | 2022-01-27 | 2022-02-03
 | Transfer to KiCad Schematic Tool | . | 0% | 2022-02-03 | 2022-02-10
 | LCD Finalization (anticipated) | . | 0% | 2022-01-20 | 2022-02-19
 | Software Fixes (to be defined) | . | 0% | 2022-01-20 | 2022-03-01
 | Generate Design & Outsource Assembly | . | 0% | 2022-02-19 | 2022-03-05
The cell at right contains the Phase 2 sample title. You can create a new phase at any time within column B. This project schedule does not require phases. To remove the phase, simply delete the row. To create a new phase block in this row, enter a new Title in cell at right. To continue adding tasks to the phase above, enter a new row above this one and fill in the task data as in cell A9's instruction. Update the Phase details in cell at right based on cell A8's instruction. Continue navigating down column A cells to learn more. If you haven't added any new rows in this worksheet, you will find 2 additional sample phase blocks have been created for you in cells B20 and B26. Otherwise, navigate through column A cells to find the additional blocks. Repeat the instructions from cells A8 and A9 whenever you need to. | Customer Installation
 | Badge Demo | to be assigned… | 0% | 2022-03-31 | 2022-04-10
 | Bill of Materials Overview | . | 0% | 2022-04-10 | 2022-04-17
 | Badge Manual Overview | . | 0% | 2022-04-17 | 2022-04-24
 | Customer Installation Feedback | . | 0% | 2022-04-24 | 2022-04-28
Sample phase title block | ECE Day / Planning
 | Logbook Reviews | to be assigned… | 0% | 2022-01-20 | 2022-05-06
 | Functional Test Planning | . | 0% | 2022-02-15 | 2022-03-28
 | ECE Day Hardware/Software Setup | . | 0% | 2022-03-28 | 2022-05-06
 | ECE Day Presentation Practice | . | 0% | 2022-03-28 | 2022-05-06
 | To be added… | . | 0%
Sample phase title block
This is an empty row
This row marks the end of the Project Schedule. DO NOT enter anything in this row. Insert new rows ABOVE this one to continue building out your Project Schedule.

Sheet: About
SIMPLE GANTT CHART by Vertex42.com (https://www.vertex42.com/ExcelTemplates/simple-gantt-chart.html)
https://www.vertex42.com/ExcelTemplates/simple-gantt-chart.html
About This Template
This template provides a simple way to create a Gantt chart to help visualize and track your project. Simply enter your tasks and start and end dates - no formulas required. The bars in the Gantt chart represent the duration of the task and are displayed using conditional formatting. Insert new tasks by inserting new rows.
Guide for Screen Readers
There are 2 worksheets in this workbook. TimeSheet About The instructions for each worksheet are in the A column starting in cell A1 of each worksheet. They are written with hidden text. Each step guides you through the information in that row. Each subsequent step continues in cell A2, A3, and so on, unless otherwise explicitly directed. For example, instruction text might say "continue to cell A6" for the next step. This hidden text will not print. To remove these instructions from the worksheet, simply delete column A.
Additional Help
Click on the link below to visit vertex42.com and learn more about how to use this template, such as how to calculate days and work days, create task dependencies, change the colors of the bars, add a scroll bar to make it easier to change the display week, extend the date range displayed in the chart, etc.
How to Use the Simple Gantt Chart (https://www.vertex42.com/ExcelTemplates/simple-gantt-chart.html)
More Project Management Templates
Visit Vertex42.com to download other project management templates, including different types of project schedules, Gantt charts, tasks lists, etc.
Project Management Templates (https://www.vertex42.com/ExcelTemplates/excel-project-management.html)
About Vertex42
Vertex42.com provides over 300 professionally designed spreadsheet templates for business, home, and education - most of which are free to download. Their collection includes a variety of calendars, planners, and schedules as well as personal finance spreadsheets for budgeting, debt reduction, and loan amortization.
Businesses will find invoices, time sheets, inventory trackers, financial statements, and project planning templates. Teachers and students will find resources such as class schedules, grade books, and attendance sheets. Organize your family life with meal planners, checklists, and exercise logs. Each template is thoroughly researched, refined, and improved over time through feedback from thousands of users.
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

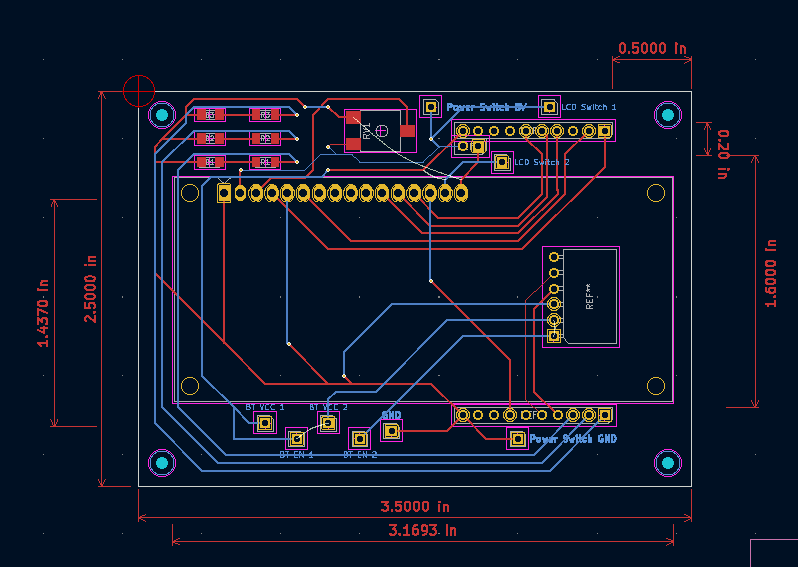
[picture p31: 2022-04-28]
etc/pcb_schematic.png

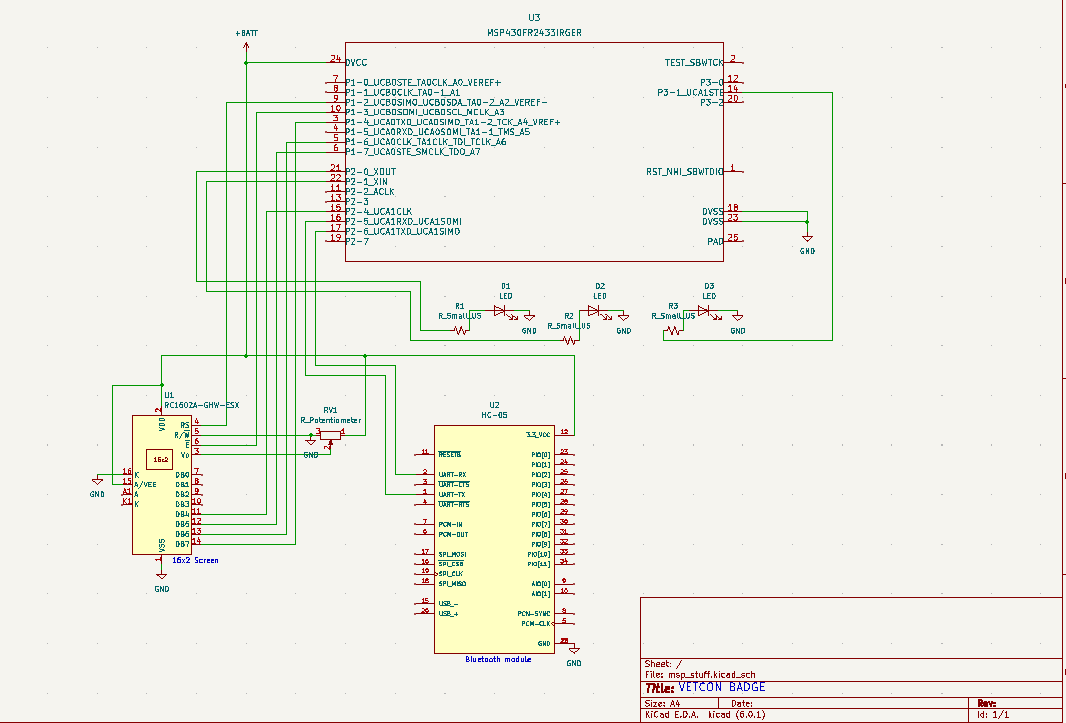
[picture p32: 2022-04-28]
etc/schematic.png

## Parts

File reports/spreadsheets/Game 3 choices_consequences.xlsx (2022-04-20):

ID | Scenario | Choice 1 | Choice 2 | Choice 1 consequence | Choice 2 consequence | Consequence1 Text | Consequence 2 Text
1 | You have an important quiz tomorrow but your friends want to go out to the bar tonight. | Go out to the bar with the boys. | Stay home and study. | Social++, Grades-, Money-- | Social--, Grades++ | You go out and spend some quality time with your friends but you spend too much money and don't do well on your quiz. | Your friends roast you for not going out, but you do well on your quiz.
2 | A classmate has asked you to help them with their homework. They're offering to pay you but you have a lot of work to do yourself. | Help your classmate. | Do your own work. | Money++, Grades-- | Grades+++ | You spend all your time helping your classmate. They pay you but your grades suffer as a consequence. | You turn them down and get a good amount of schoolwork done.
3 | It's Valentines Day! Your significant other wants to go out for dinner but you've skipped a few workouts this week. | Blow them off and work out. | Go out to dinner. | Health++, Social- | Money--, Health--, Social++ | She's pissed but it doesn't matter because you got a decent pump. | Dinner was nice but you definitely spent too much money. You feel bloated the next day.
4 | You've been working hard all week and are feeling a little under the weather. However, you have an important exam tomorrow morning. | Pull an all-nighter and study for your exam. | Get some rest. | Grades---, Health-- | Grades++, Health+ | You wake up tired and groggy. You can't focus on your exam. | You feel refreshed and focused. Your exam goes well.
5 | Your friends are planning to enter an intramural sports league. They ask you to join but your schedule is already packed. | Join your friends. | Don't join your friends. | Health++, Social+++, Grades-- | Grades++, Health--, Social- | Your team does better than expected and you win the tournament. However, the weekly commitment has negatively affected your grades. | You decide not to participate and use the time to study instead. You miss out on the physical activity and time with your friends.
6 | It's Spring Break! Yout have to decide whether to spend the week partying in Mexico or catch up on work and sleep. | Party time. | Take it easy. | Health--, Grades--, Money---, Social+++ | Health++, Social--, Grades++ | Spring break is an absolute blast. However, you come home broke, sick, and unprepared for your exams. | You spend spring break watching all of your friends have the time of their lives through their social media accounts. You are sad. However, you do get a good amount of work done and are well rested for when classes resume.
7 | You forgot you have a midterm exam tomorrow! Do you cram study for the next couple hours or play video games with friends. | Study | Play Games | Grades++, Social-- | Grades--, Social++ | You studied and did well, but you missed out on some quality time with your boys. | You play late into the night. You are exhausted and woefully unprepared for your exam. You fail.
8 | Your classmate is having a tough time and missing home. | Console them | Don't Console Them | Social++ | Social-- | You talk for a while and end up making a new friend. | You've missed an opportunity to help someone and make a new friend.
9 | You've been working on your Senior Design project, using a TI MSP430-FR2433. CCStudio is being extremely annoying and you cannot find any solution to your problem. | Soldier on and figure it out | Switch to PlatformIO | Social--, Grades--, Health-- | Health++, Social++, Grades++ | This is literally the worst decision you could have made. | It turns out there is a god. His name is PlatformIO
10 | You have to buy some parts for your senior design project. You have two options. One part is more expensive but easier to use and implement. The other is cheap and easily breaks. | Buy the expensive option | Buy the cheap option | Grades++, Money-- | Grades-- | You had to spend some of your own money, but the quality of the component improved your overall project substantially. | The component was cheap and unreliable and your professor could tell. At least you didn't spend money.
11 | There's a party in Allston tonight! | Go out with your friends | Stay home | Social++, Health-- | Social--, Health++ | You go out with your friends and make even more at the party! The next morning you feel hungover and inevitably get sick | You go to sleep early and get some much needed rest. You wake up to stories and posts from your friends about how fun the party was. You feel left out.
12 | Some rando offers you a drink at a bar | Drink it | Turn them down | Health-- | Nothing | Tastes weird. That probably wasn't a good idea. | You turn him down. Probably for the best.
13 | Your friends need drinks for the party tonight and you live right next to the liquor store. | Purchase drinks for the group | Don't purchase drinks | Money--, Social++ | Social-- | It's expensive, but you feel like everyone's hero for the night. | Your friends are a little dissapointed. At least you didn't spend any money.
14 | Your friends have an extra ticket to a concert and want you to come with them. However, a few of them are expressing flu-like symptoms. | Turn them down. | Go to the concert with your friends. | Health++ | Health--, Social-- | You stay home. It turns out to be a good idea. Most of your friends who attended the concert tested positive for COVID a few days later. | You end up testing positive for COVID a few days later. You're forced to isolate for a week and miss out on a few social events.
15 | It's your friend's birthday! | Buy them a gift | Don't buy them anything | Social++, Money-- | Social--- | Though it was a little pricy, the gesture goes a long way and your friendship improves. | Turns out all of their other friends got them a gift. You were the only one who didn't. You feel terrible.
16 | It's game day! | Cheer from the stands, support the Terriers | Streak onto the field | Social+ | Social+++ | You have a good time hanging with the lads. | You're banned from all sporting events and have a meeting with a disciplinary advisor. However, you have become a campus legend overnight. You will never be forgotten.
17 | You're out at the casino with your friends. | Put it all on black | Put it all on red | Money- | Money- | There's no winning | There's no winning
18 | You are on your final set of deadlifts at the gym, but your lower back is hurting more than usual. Do you push through the last set or stop? | Push through! | Stop, you don't want to hurt your back | Health-- | Health++ | Your spine simply shatters. You will never fully recover. | Good idea.
19 | Your friends dare you to ask your crush to a formal in front of the whole class. | Ask her | Chicken out. | Social-- | Social-- | You are flat out rejected. You leave the class ashamed and miserable. | You don't end up going through with it. Your friends roast you and you are filled with regret.
20 | Everyone at the party is doing shots together! They all ask you to join even though you are already completely blitzed. | Take the shot | Don't take the shot | Social++, Health-- | Social--, Health++ | You take a shot with your friends as everyone cheers. A few minutes later you sneak off to the bathroom and violently vomit. You look at yourself in the mirror and ask yourself why you are the way that you are. | Your friends are disappointed. However, the next day you don't feel like you've been hit by a truck.
21 | The cute student in your class asks to study with you in the library. | Study with them | Turn them down. | Grades-, Social- | Grades++ | You attempt to study with them but you find yourself being distracted by them the whole time. You both end up failing and she blames you for it. | You decide you're better off studying alone. You get your work done.
22 | The cute student in your class asks to study with you in their room. | Study with them | Turn them down. | Grades--, Social++ | Grades++, Social-- | You don't get much studying done but you both have a great time together. | You decide to focus on your own studying. Later, you find out that another classmate "studied" with them.
23 | You found a random wallet on the ground with $500 cash inside. No one is around you. | Take the cash | Leave it | Money+++ | Nothing | Free money. | Why would you do that.
24 | A professor has asked you to become a TA for their class. You will be payed for your time but your schedule is relatively busy already. | Become a TA | Turn down the offer. | Social--, Grades--, Money++++ | Money- | You are now making some steady weekly income, but this takes time away from your friends and your work for other classes. This will affect you for the rest of the semester. | You really could've used the money, but the time commitment was too much.
25 | You see a dog on your walk | Pet it | Kick it | Nothing | Social----, Health--, Money--, Grades-- | Good boy. | Fuck you. FORK BOMB
26 | The BU Fitness and recreation center is very crowded. You're considering becoming a member of another gym. | Pay for a monthly membership | Keep working out at the FitRec | Money----, Health++++ | Health-- | The membership is worth it for your health. Your workouts are now higher quality and more consistent. However, this is another regular expense for you to consider. This will affect you for the rest of the semester. | You have yet another subpar workout. It doesn't feel good.
27 | You're considering joing a fraternity. | Join a frat | Don't join a frat | Social++++, Health---- | Social--- | You rush and make it through the pledge process. You're having a great time partying with your friends every weekend, but you are consistently hungover and ill. This will affect the rest of your semester. | All your friends end up rushing and you find yourself alone on weekends with nothing to do.
28 | You're reorganizing your class schedule. You have to decide whether to take the Friday night class with an easy-grading professor, or the Thursday morning class with the notoriously hard professor. | Take the Friday night class | Take the thursday morning class | Grades++, Social-- | Grades--, Social++ | Taking the class improves your GPA, but you miss out on many Friday nights with your friends. | The professor was indeed very tough and your GPA takes a hit. At least you keep your weekends free for your friends, though.
29 | You're walking by the GSU. A charity nonprofit asks you to sign, do you? | Sign the petition | Don't | Social++ | Social-- | Oddly enough, your signature was the last one needed to break the threshold! One more step towards justice for the whales :) GO SHAMU! | Why didn't you wanna save the whales? :(
30 | You walk by a vending machine, a bag of Cheetos is hanging by the tip of its corner. | Run into the vending machine | Walk by, remorsefully | Health---, Money-- | nothing | The vending machine tips over and falls on your leg, you needed an ambulance to the hospital and you dont have insurance. You never fully recover. | You long for the bag of Cheetos, but continue about your day regularly
31 | You're jogging on the treadmill at FitRec. You're hitting a great stride, and you feel like you can ramp it up a notch. | Increase the incline | Keep doing your thing | Health++ | Health++ | You feel the burn. Gains don't sleep | You got a good workout in. Nice job.
32 | You're feeling hungry. You walk by UGrill and see a fresh hot pie coming out of the oven. | Buy a couple slices of cheese, you've earned it. | Force yourself to eat the food you have at home. | Money-, Social++ | Nothing | You spend a few bucks to enjoy a hot-n-ready slice. You run into a few friends by coincidence. | You're heating up Thai takeout as you stare at the wall.
33 | Your neighbor's dog had puppies! | Adopt one | Do nothing | Money-. Social+++, Health+++ | Nothing | Your puppy is an instant source of happiness. People on the street approach you and your new dog constantly. | Most of the puppies are eventually adopted. You still stop by your neighbor's to play with the one's they kept, occasionally.
34 | You have the opportunity to work as a resident assistant | Become an RA | Do nothing | Money++++, Social---- | Social+ | You have a weekly stream of income. However, you have to be on call for one of the days of the weekend, meaning you miss out on some social events. This will affect you for the rest of the semester. | You don't end up applying, but at least your weekend stays free of responsibilities.
35 | You go to the club fair | You join HAPA (Half Asian Peoples' Association) | You decide its not worth the time | Social++++ | Social- | You find a group of great people at HAPA that you really click with and make friends for life | You stay as you always are, alone and worthless, Guen also hates you bitch
36 | Your parents are in town! They offer to throw you a few bucks to take care of some expenses. | Accept your parents' offer. | Reject with pride. | Social--, Money+++ | Social++, Money-- | Realize that you're still dependant on them. You're not the big boy/girl you thought you were. | Feel empty inside as you know you needed the cash. You feel oddly remorseful but determined to tough it out on your own.
37 | You're tired after class, and you want to take the BU BUS back to your dorm. After a few minutes, the bus stops by but it is packed to the brim. | Get on even though there is clearly no more space. | Take a deep breath and just take the 15 minute walk like an adult. | Social -- | Social++, Health++ | You are now "that guy" that slows everyone down. You hear groans as you step onto the bus. | You're not as tired as you thought. The walk helps clear your mind.
38 | You have been talking to some person for a while and they've been busy this week, leading to minimal contact | Double text them | Wait for a response, they said they'd "lyk" | Social--, Health-- | Social--, Health++ | They were trying to get away either way, you were always chasing | You end up forgetting about it. You don't got time for games!
39 | You have some homework to do and you've been feeling a little unproductive lately. | Head out to Mugar and get into the zone. | Stay in your room. You're comfy as is. | Grades++, Social++ | Grades-- | You ran into some friends and collaborated on the homework. You got it done in half the time and are ready for the quiz tomorrow! | You get lazy and watch Netflix. You also forgot about the quiz tomorrow.
40 | Eric Andre shows up on campus | Bird Up? | Bird Up! | Nothing | Nothing | Put your chest into it, DAWG. | Right on, dude!
41 | Mike's or Modern? | Mike's | Modern | Money-- | Social++ | You fell for the tourist trap. You're not a Bostonian | That's the way to go!
42 | Why you got so many necklace? | Candy boy! | Why you got necklace? | Nothing | Nothing | Does it smell in here? | Does it smell in here?
43 | You're at a Hockey game. It's BU vs BC. Rhett The Terrier comes over, requesting a selfie. | Take one! BC SUCKS | Reject him because he isn't the real Rhett, but rather a mortal in a fur suit. | Social++ | Social-- | BC SUCKS BC SUCKS BC SUCKS BC SUCKS | Dude, you're such a buzzkill.
44 | What do you call a soldier who is unfased by pepper spray and mustard gas? | I don't know, what do you call one? | Uh..... | Nothing | Social--, Health--, Grades--, Money-- | A seasoned veteran! | What, you're too good for jokes?
45 | You're thinking of attending the next DEFCON. You're deciding to bring. | Bring your laptop and phone so you can play all the games and make some friends :) | Bring nothing. | Social--, Money--, Health--, | Nothing | Every single device you brought was immediately hacked. Someone stole all your money, sent incriminating emails to every single one of your contacts, and canceled your health insurance. Your life is over. | You have a good time.
46 | You're running low on cash, you see a poster advertising firms that will buy your plasma for a hefty amount of cash. | Do it. You could use the extra few hundred bucks. | Turn it down, you have standards. | Money+++ | Nothing | Payday is good! And you got some cranberry juice out of it too :) | You go on about your day.
47 | A fellow student created a new Crypto Token called Terrier Coin, he attempts to convince you to throw a few bucks into it. | You agree, begrudgingly. | Refuse, you're not a crypto person. | Money+++ | Social---- | The coin explodes overnight, with a 1000% gain. Your few dollars turned into a couple hundred fast. | You're literally the only person who missed out on the massive pump. You are mercilessly ridiculed.
48 | You're late on an assignment. You're almost finished but the deadline is five minutes away | Accept defeat, finish the assignment, and move on. | Send a fork bomb to the submission portal | Grades-- | Social++ Grades-- | Your homework average takes a hit, but you can pull through in the class | We have no idea how you didn't get expelled. Your grades still take a hit because it didn't pass the autograder, but you brag about it to your friends.
49 | You're considering a semester abroad | Apply for it | Eh another semester | Grades--, Money--, Social+++ | Grades+++, Social+ | You have a great time! | You miss out on a great time but your friends are glad you stayed and you can really focus on your grades.
50 | What's that noise? | Investigate. | Ignore it. | Nothing | Nothing | I'M IN YOUR WALLS I'M IN YOUR WALLS I'M IN YOUR WALLS I'M IN YOUR WALLS I'M IN YOUR WALLS I'M IN YOUR WALLS I'M IN YOUR WALLS | An eerie sound creeps along.

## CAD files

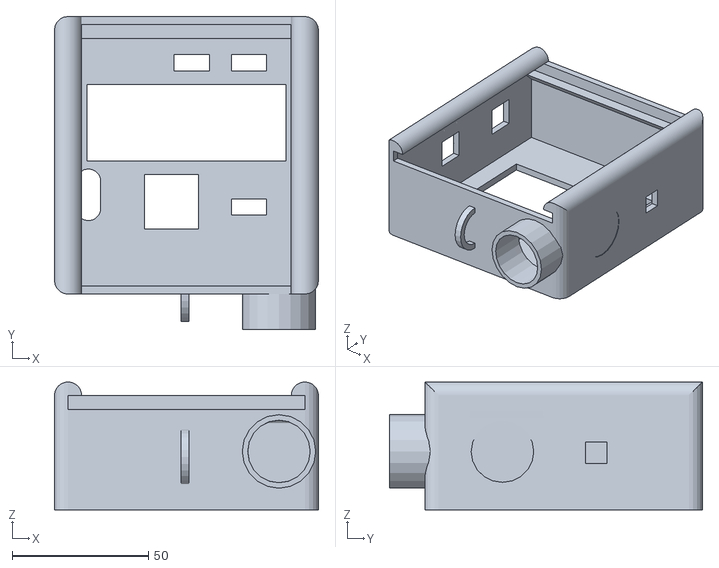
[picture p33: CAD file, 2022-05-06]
enclosures/pcb_enclosure_final.stl
97.0 x 115.0 x 47.0

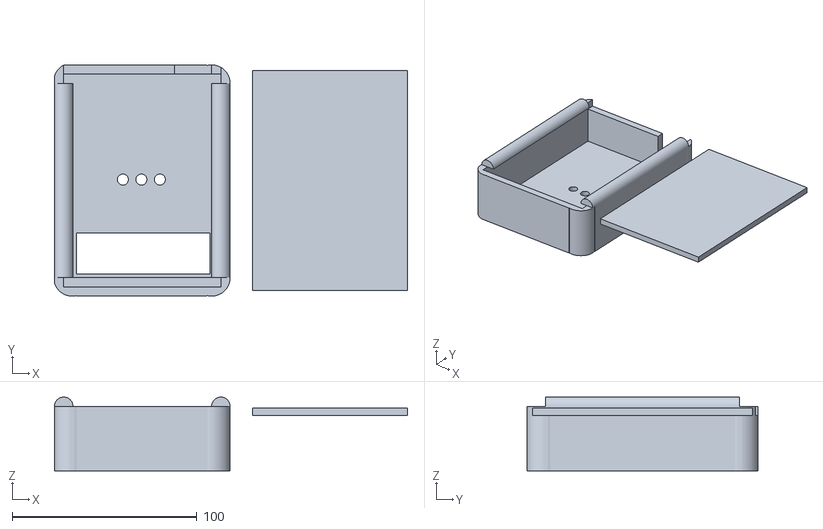
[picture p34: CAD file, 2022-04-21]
enclosures/protoboard_case.stl
191.0 x 125.0 x 40.0

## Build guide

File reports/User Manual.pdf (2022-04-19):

## Boston University Electrical & Computer Engineering

EC464 Capstone Senior Design Project

## User's Manual VETCON BADGE ASSEMBLY AND OPERATION

Submitted to:
VETCON | Mike Jones
(910) 551‐6746 | jonesmlr@gmail.com

BY:
Team 32 | VETCON Badge

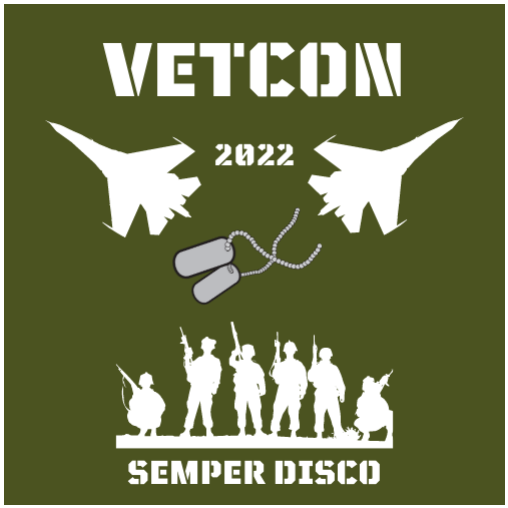
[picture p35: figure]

Team Members

Ryan Sullivan ryanbs@bu.edu Derek Barbosa dbarbosa@bu.edu John Kircher kircherj@bu.edu Carlos Ortiz cartex10@bu.edu Julian Padgett jpadgett@bu.edu

Submitted: 03/25/22

## VETCON Badge

## Table of Contents

3.3 Safety Issues |
13

## Executive Summary

We, Team 32, are working closely with our client (VETCON) – a group of information security professionals who have served in the armed forces of the United States or close allies– to provide a detailed blueprint for an identification “badge” to be used by VETCON in the upcoming DEFCON conference that sticks with a Cybersecurity theme.

In other words, VETCON wants a unique, functional, and production-ready badge for DEFCON 30. This DEFCON badge will provide customizable identification for VETCON attendees and as a collection of interactive minigames on a consistent hardware “platform.”

## 1 Introduction

Every year, DEFCON, the largest underground hacking conference, employs unique badges that feature complex puzzles, electronics, and artistically designed circuit boards that allow different “villages” (DEFCON groups) to interact with each other beyond hacking competitions and research conferences.

This year, our client, VETCON (a group of information security professionals who have served in the United States armed forces and its close allies, and one of the villages present at DEFCON each year) wants to create a cost-friendly but unique badge that DEFCON attendees can purchase to interact with others. However, developing a badge takes time. Badge developers need to consider many components: not only do they need to order parts, but they also need to create a badge production process that does not exceed a given budget. Moreover, VETCON wants to create a badge that stands out. The badge should be visually sophisticated and aesthetically pleasing so that attendees see it and immediately want to purchase one.

The badge we have designed for VETCON to distribute at DefCon is powered by Texas Instruments' MSP430FR2433 microcontroller (MCU). A big reason for this choice is that the controller is part of the lowest-cost family of MCUs for sensing and measurement applications. The architecture, FRAM, and integrated peripherals, combined with extensive low-power modes, are optimized to achieve extended battery life in portable and battery-powered sensing applications. The onboard software is written in a stripped down version of C++ that is compiled with an open source framework toolchain called Wired, which is automatically deployed through a compilation of scripts and toolkits through PlatformIO – this enables us to interface and flash the MCU.

Our badge also includes unique peripherals that allow for an engaging user experience whether it be communication, customization, or the unique challenges on the badge. These include: 1) the HC-05 wireless bluetooth module which has been programmed for users to have simple communication with other badge holders. 2) A 16x2 alphanumeric liquid crystal display allowing users to display a name of their choice and other customizable glyphs. 3) An array of LEDs to display user progress for the challenges provided. 4) Push buttons that allow badge reset capabilities. The badge also includes 3 games/puzzles which can be accessed in a progessive manner (you can’t access the next puzzle without solving the previous one). Each game/puzzle includes unique ciphers and codes that vary in difficulty and can even penalize the user and restart their progress if the ciphers are not decrypted correctly.

Ultimately, the badge we have produced for VETCON is unique, functional, and fun. The remaining sections of this document will dive into a more technical overview of the badge as well as its general operation and a breakdown of the user interface and setup.

## 2 System Overview and Installation

## 2.1 Overview block diagram

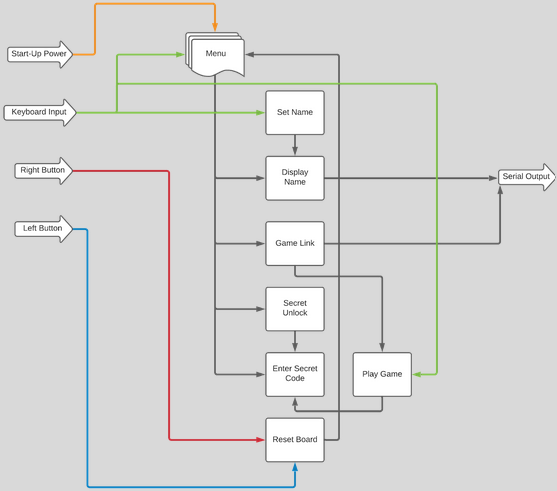
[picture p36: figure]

2.2 User interface.

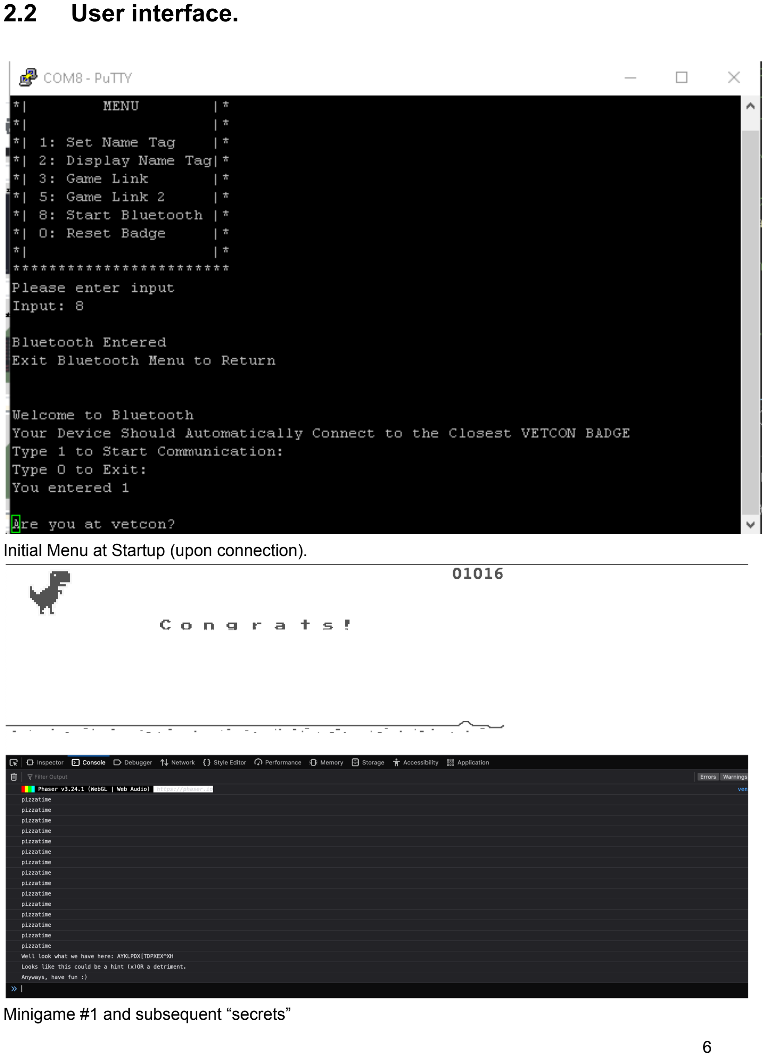
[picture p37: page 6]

Initial Menu at Startup (upon connection).

Minigame #1 and subsequent “secrets”

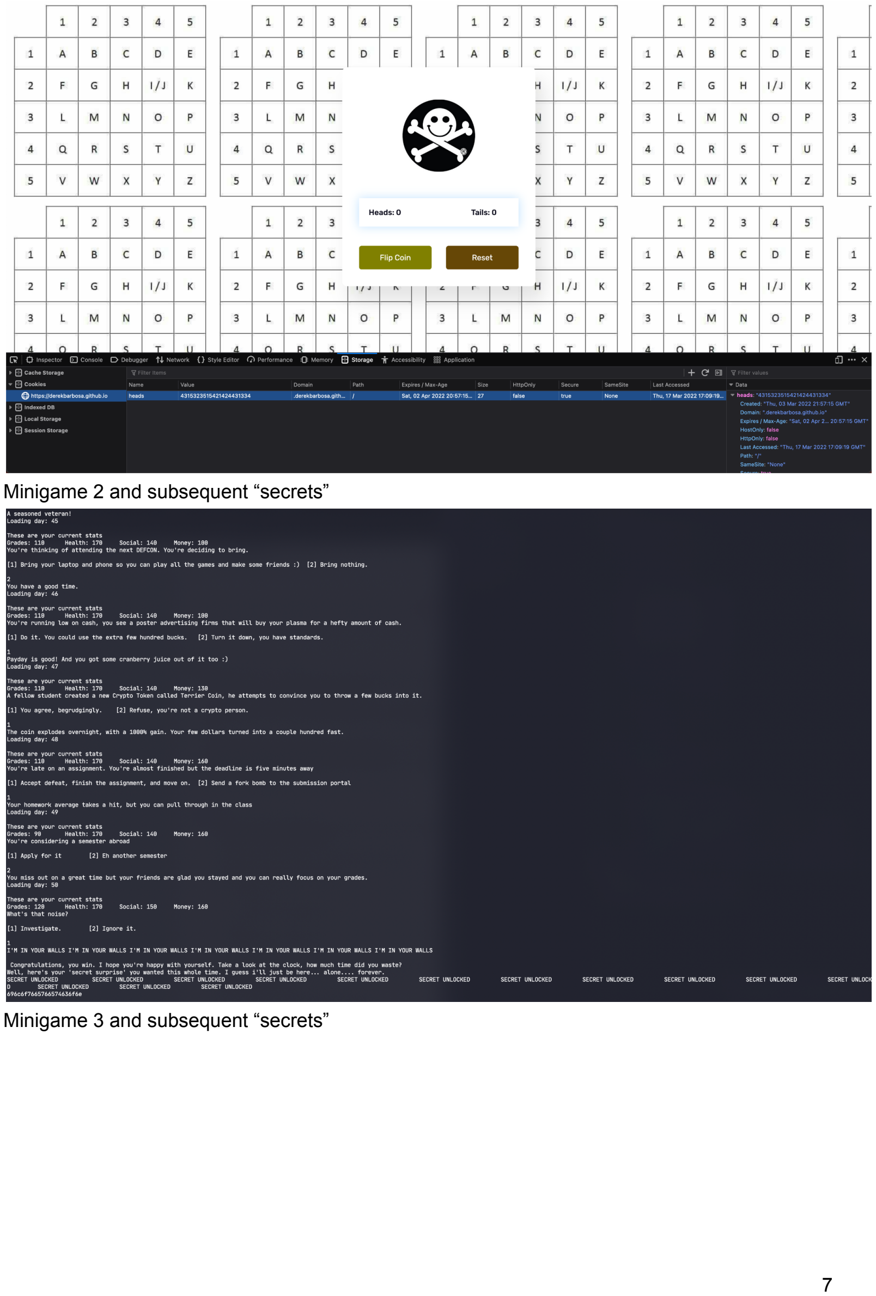
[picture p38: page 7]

Minigame 2 and subsequent “secrets”

Minigame 3 and subsequent “secrets”

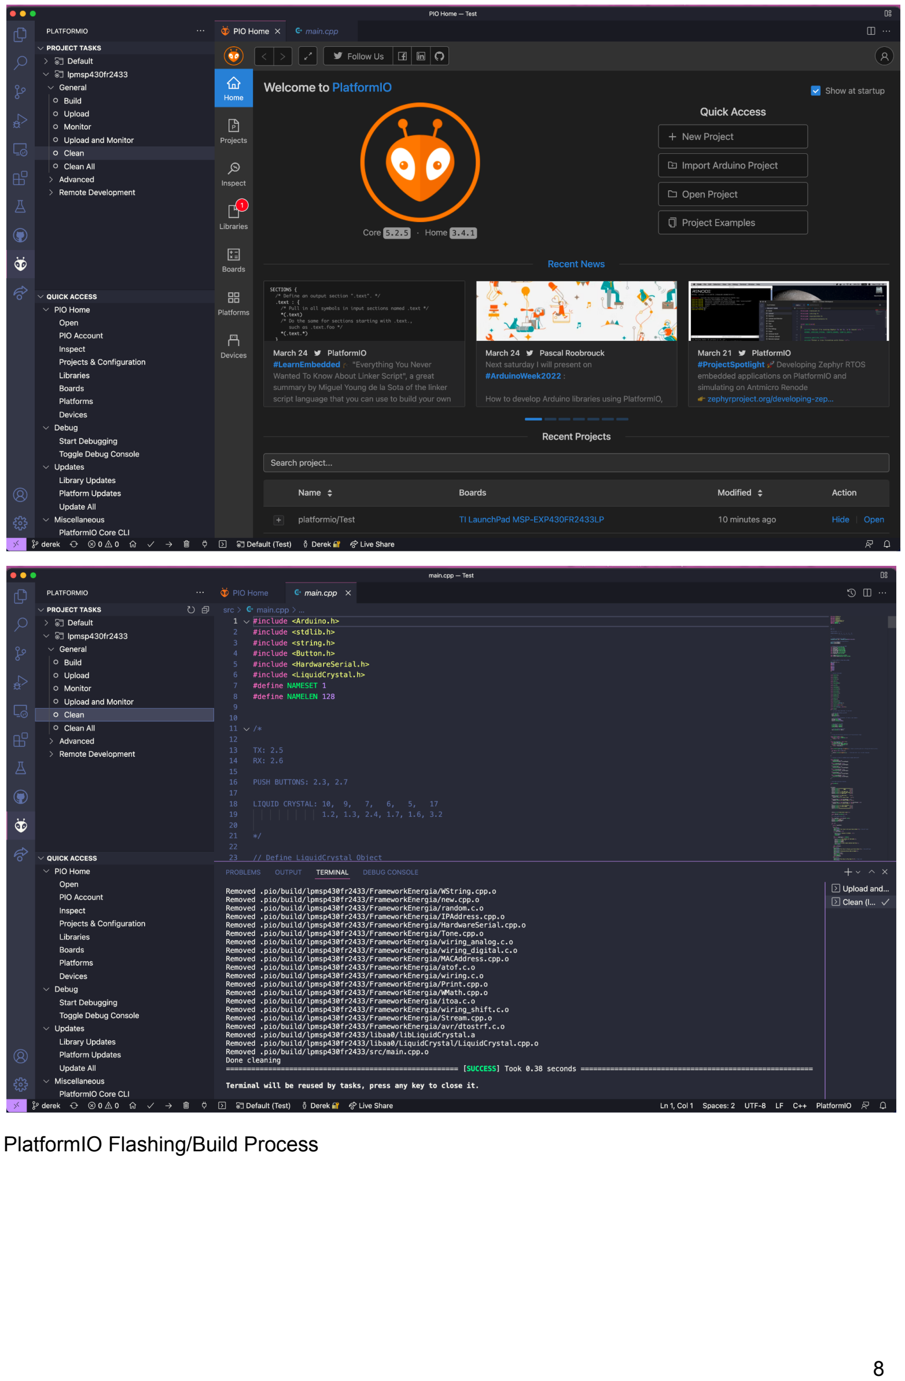
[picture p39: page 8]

PlatformIO Flashing/Build Process

2.3 Physical description.

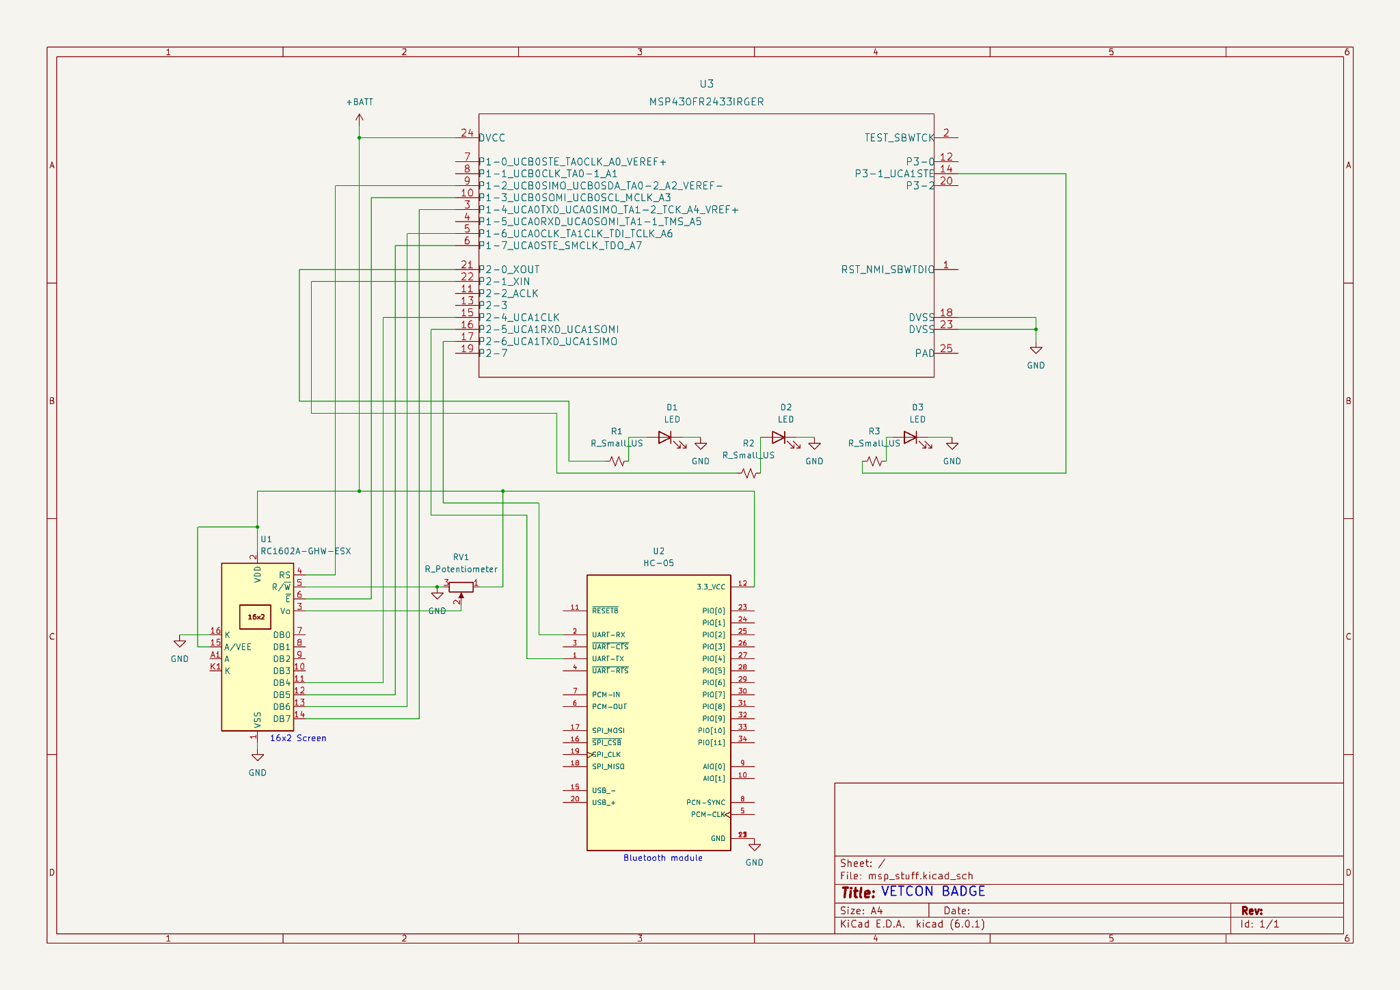
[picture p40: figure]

Schematic for complete prototype circuit

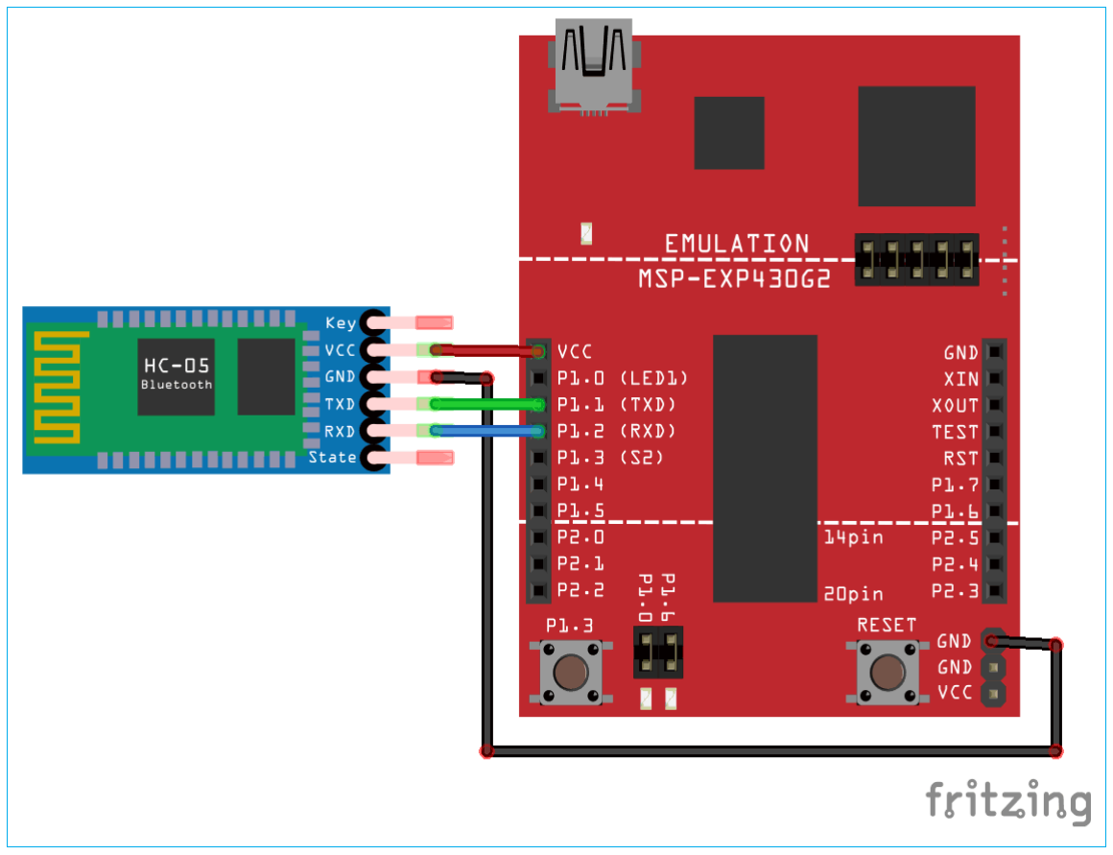
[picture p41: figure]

Colored representation of Bluetooth Module hookup.

## 2.4 Installation, setup, and support

Services Needed:

1. PlatformIO (Arduino Framework, C++)
a. PlatformIO will be used for flashing our software to the board
2. Visual Studio Code
a. Used in tandem with PlatformIO
3. Software (Available with invite to our private repo)

Setup:

To flash software:
1) Plug in MSP430FR2433 via USB-C to laptop with PlatformIO
2) Open Visual Studio Code
3) Open downloaded software project via PlatformIO
4) Select PlatformIO with VSCode
5) Click upload.

Once the flashing process has been completed, the badge is ready for use and can be distributed to users. Please see support below for specific badge operations.

Support

1) Power
a) Switch the power button on/off to activate/deactivate the badge. i) / ii) show badge is running properly.
i) LCD will initialize with “Welcome to VETCON 30”.
ii) Bluetooth module status LED will flash rapidly.
2) Serial Communication
a) USB-C cable serial communication will be initiated once plugged into a user's computer. COM port will look like MSP - UART in a device manager.
i) Serial Preferences (widely accepted default serial settings):
(1) Baud Rate: 9600
(2) Data Bits: 8
(3) Parity: None
(4) Terminal / Logging: Implicit CR in every LF (Highly
| recommended)
3) LCD / Potentiometer
a) LCD includes a backlight switch to turn on/off the backlight for the display
b) Potentiometer controls voltage received by the LCD to make the backlight brighter or dimmer
4) Bluetooth
a) Command mode (enable switch on)
i) In command more the LED should slowly blink, roughly once every
| 2 seconds
b) Communication mode (enable switch off)
i) Scanning
(1) LED blinks rapidly every half second ii) Connected
(1) LED blinks twice every other second
iii) Off
(1) LED stays off. Turn the badge off and back on to reset.

## 3 Project Operation

### 3.1 Operating Mode 1: Normal Operation

The device has two main modes of operation. The first is the functionality provided by the device on its own: the user can interface with the buttons on the device and see output on the connected screen. The second mode of operation can only be accessed when the user connects the device to their laptop using the device’s USB-C port and initiates a TTY connection. This mode of operation provides the user with much more functionality, as not only does this operational mode give the user the ability to control the device using their keyboard, but the connection will also provide the user with a visual interface to control the device.
The user has many options from this menu, such as selecting a display name if they input “1”. Inputting this will allow the user to change the name displayed on the device’s screen. Depending on the user’s name, certain images may appear alongside it. If the user wishes to display their name tag from the TTY connection window, they can select “2” to print it. If the user selects option “3”, the device will print a link to a game, which the user can play as long as they are connected to the internet. The user can initiate a bluetooth connection with another device by selecting option “8”. The badge will then ask the user if they wish to search for other devices, and the device will be able to connect to another after successfully finding a valid connection. If the user wishes to restore the badge to factory defaults, they can do so by selecting option “0” and following the instructions presented onscreen. The options shown in the menu initially are not all of the options a user can select. Menu options are revealed to the user over time through experimentation and puzzle-solving.

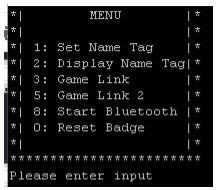
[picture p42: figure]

### 3.2 Operating Mode 2: Abnormal Operations

Doing any of the following will prompt misinput and would be considered “Abnormal Operation,” that is, outside the scope of defined operation:
- If a user selects either an invalid or hidden option, the badge will warn them and return to option selection with no consequences to the user.
- If the user selects an option and then regrets their selection and wishes to cancel, most options will allow the user to cancel input and return to the menu.
- If the user hits “enter” to confirm any typed text (rather than waiting 1-2 seconds for the serial timeout functionality), it will send an additional “newline” character that will lead to incorrect parsing of their input string. Errors may occur in between menus or when confirming selected options.

### 3.3 Safety Issues

Our badge has very few, if any, safety issues. The device operates at a relatively low voltage and should not be able to physically harm users. In terms of data security, this badge should have no issues at all. Attendees who purchase a VETCON badge are supposed to attempt to hack the device.

## 4 Technical Background

PlatformIO:

PlatformIO acts as our main way of flashing and interacting with MSP430 EXP-FR2433 and all the connected hardware. PlatformIO also allows us to more easily create and test code for the microcontroller as it abstracts the standard C used by CCStudio into the more palatable Arduino coding standard.
Badge:

Hardware:
Our badge is based on TI’s MSP430 EXP-FR2433 microcontroller. This is the platform for our software and allows utilization of peripheral devices. Such as, our HC-O5 bluetooth modules and our LCD alphanumeric display.
Software:
We coded the entirety of the codebase in C++. An infinite loop handles the menu functions with a series of flags being set and unset for inputs that the user makes through serial communication. Our bluetooth is also interfaced through a hardware serial communication port, and follows the same coding paradigm as the main menu code.

## 5 Relevant Engineering Standards

Our badge operates under the ANSI-C++ Standard for all board/badge programming. Furthermore we are using GNU Make and GNU GCC/G++ library headers and dynamically linked libraries. Finally, we are operating according to typical DEFCON procedures.

## 6 Cost Breakdown

Project Costs for Production of Beta Version (Next Unit after Prototype)

Item | Quantity | Description | Unit Cost | Extended Cost
TI-MSP430 EXP FR2433 | 1 | Microcontroller to Micro-ly control things | 9.99 | 9.99
HC-05 BT MODULE | 1 | Bluetooth module to connect to other badges | 1.93 | 1.93
16x2 AlphaNumeri c Display | 1 | Alphanumeric Display to display non serial messages | 1.71 | 1.71
Multicolored LEDs (Assorted) | 3 | Light Emitting Diodes to be used as progress indicators | 0.01 | 0.03
D1 Mini Charge/Boos t Module (LIPO) | 1 | Charge Controller/Regulator for Lithium Polymer Batteries. | 1.93 | 1.93
3.7v, 3000mAH 18650 Battery | 1 | Lithium Ion Battery to provide 20 hours of continuous use. | 4.25 | 4.25
Beta Version-Total Cost | | | | 19.84

## 7 Appendices

## 7.1 Appendix A - Specifications

ALL EMPIRICAL REQUIREMENTS ARE WITHIN ± 10% TOLERANCE
Battery Life | 21 Hours of Continuous Operation
Dimensions | 4” x 4” x 1”
Weight | 150 Grams
Attachments | Secure Lanyard Attachment Point
Branding | Visible VETCON branding or Military Decor
Interfaces | On/Off Switch; USB-C Interface;
Networking/Communication | Physical P2P (Serial) ; Bluetooth
Interactivity | Liquid Crystal Display; On-board and Web-based minigames

## 7.2 Appendix B – Team Information

John Kircher – Cybersecurity Research and Development Team at Raytheon Worked primarily on ciphers for games 1,2,3 – software development – bluetooth research and development – circuit design.

Derek Barbosa – Working on the RHEL Real-Time Linux Kernel Team at Red Hat Worked primarily on research for all phases, Microcontroller Software, Game 1 deployment, Game 2 Development, Game 3 Development (engine and frontend), LCD Interfacing, Circuit Design.

Ryan Sullivan – Working on the Research Kernel Team at Red Hat
Worked primarily on main menu code development, general debugging of code in all phases, Game 3 development and troubleshooting.

Carlos Ortiz – Searching for work
Worked primarily on game 1 development – LCD interfacing – PCB design – Circuit diagram

Julian Padgett – Software Engineer at Northrop Grumman
Worked on bluetooth research, LCD research, Game 3 concept and content, 3D printed enclosure.

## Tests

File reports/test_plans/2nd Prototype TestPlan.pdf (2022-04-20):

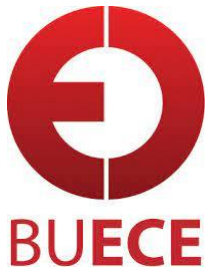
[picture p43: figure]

## Boston University Electrical and Computer Engineering

EC464 Senior Design Project

# 2nd Prototype Testing Plan

# VETCON

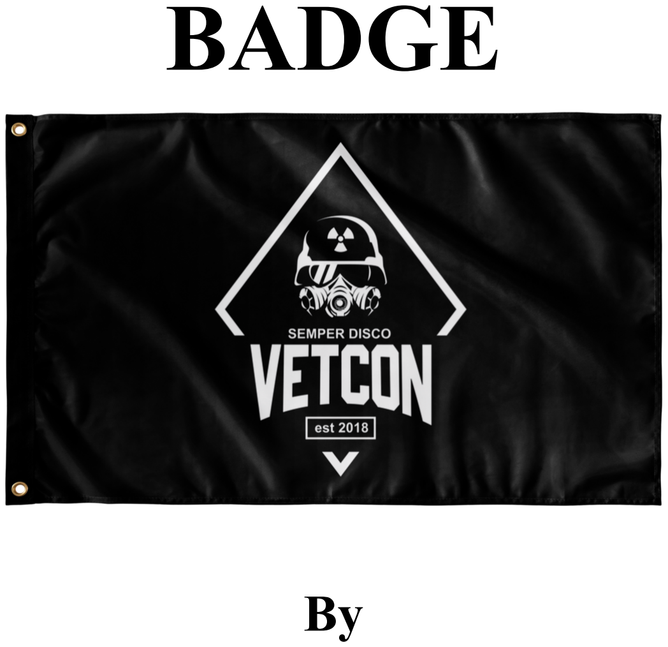
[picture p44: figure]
BADGE

Team 32

Team Members

Derek Barbosa, dbarbosa@bu.edu John Kirche, kircherj@bu.edu Carlos Ortiz, cartex10@bu.edu Ryan Sullivan, ryanbs@bu.edu Julian Padgett, jpadgett@bu.edu

Required Materials:

Hardware:
1. Texas Instruments (TI) MSP430FR2433 LaunchPad™
a. 16 bit MCU
b. 20-pin LaunchPad Kit Standard Leveraging The BoosterPack Ecosystem
c. On-Board eZ-FET Debug Probe
d. 2 Buttons And 2 LEDs For User Interaction
e. HC-05 Bluetooth Module
2. Computer/Laptop
3. Micro USB Cable
a. Connection Between MSP430 & Computer
4. Arduino, Wires, Resistors, and Extra LEDs for Testing

Software:
1. Code Composer Studio Integrated Development Environment. (CCSTUDIO)
a. C/C++ compiler
b. Source Code Editor
c. Build, Upload, Monitor
d. Embedded Debug Capabilities
2. Visual Studio Code
a. Source Code Editor
3. PlatformIO
a. Cross Platform / Cross Architecture IDE tool
b. Embedded Application Software Development
4. Scripts
a. C++ Script, main.cpp
5. Package Extensions
a. Monitoring Button State & Debouncing
6. Github Pages
a. Hosting Of Web Games

Setup:

The setup for this project is relatively simple. First, a team member’s computer will clone the team’s Github Repository with the test code from the ‘testing’ branch. The project containing ‘main.cpp’ and all libraries and dependencies will be opened through PlatformIO on the Visual Studio Code IDE. Finally, a team member will plug in the MSP430FR2433 to the computer, ready for demonstration.

Testing Procedure:

### 1. Initialize the MSP + software (build, upload, and monitor)

2. Demonstrate option 1 (Set Name Tag)
a. Demonstrate that repeating option 1 prompts message that name has already been set
3. Demonstrate option 2 (Display Name Tag)
4. Demonstrate option 3 (Game Link)
a. Demonstrate the Dino Game
b. Show winning condition secret code
5. Demonstrate option 0 (Reset)
6. Demonstrate secrets
a. Show a secret username through option 1
b. Select option 4, prompting “access denied”
c. Select ‘secret’ option 9, unlocking option 4 in the menu
d. Enter secret token from game 1, changing LED1 state
7. Demonstrate option 5 (Game Link 2)
a. Demonstrate the coin flip game
b. Select option 6 again and enter secret token from game 2, changing LED2 state
8. Demonstrate saved data between device power states
a. Disconnect device from power and show that it is fully off b. Reconnect device to power and show the information saved in the previous session
9. Demonstrate option 8 (Bluetooth)
a. Show Bluetooth serial port can be connected to.
b. Show successful print statement of Bluetooth serial port

Measurable Criteria:

The criteria for a successful running of the prototype testing is as follows:

1. VETCON BADGE displays on startup
2. Main menu displays in terminal
3. User can select from given options
4. User can enter name to nametag
5. User’s name can be displayed
6. Game links can be retrieved
7. Online games run
8. Secret phrases can be retrieved on winning the games
9. User can reset badge
10. User can select to abort / continue with reset
11. User can keep their stored data on the device after reconnecting to power
12. User can connect to the Bluetooth serial port.

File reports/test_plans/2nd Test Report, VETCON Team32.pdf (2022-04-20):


## Boston University Electrical and Computer Engineering

EC464 Senior Design Project

# 2nd Prototype Test Report

# VETCON

BADGE

Team 32

Team Members

Derek Barbosa, dbarbosa@bu.edu John Kirche, kircherj@bu.edu Carlos Ortiz, cartex10@bu.edu Ryan Sullivan, ryanbs@bu.edu Julian Padgett, jpadgett@bu.edu

### Equipment & Setup:

The equipment used for our prototype testing followed the hardware and software specifications listed below.

Hardware:
1. Texas Instruments (TI) MSP430FR2433 LaunchPad™
2. Computer/Laptop
3. Micro USB Cable
4. Breadboard (2 LEDs, Resistors, Wires)

Software:
1. Visual Studio Code
2. PlatformIO

The setup for our prototype testing was very simple. One of our team members, (in this case, John Kircher) cloned our Github repository with our prototype code from the testing branch. The project was then opened with PlatformIO on the Visual Studio Code IDE. Following this, the MSP430FR2433 was connected to the computer with the micro USB cable. Using PlatformIO, the project was built and flashed onto the board ready for demonstration. Furthermore, a breadboard with correct pin connections to 2 LED’s was set up.

### Measurements Taken:

1. VETCON BADGE displays on startup
2. Main menu displays in terminal
3. User can select from given options
4. User can enter name to nametag
5. User’s name can be displayed
6. Game link(s) can be retrieved
7. Online game(s) run (Game 1,2,3)
8. Secret phrase can be retrieved on winning the game(s) (Game 1,2,3)
9. User can reset badge

10.User can select to abort / continue with reset

Upon startup, VETCON text was displayed correctly alongside the menu of options in the terminal. All options were able to be selected by the user during the demonstration. These options included the ability for the user to enter a username, change their username, display their username, and obtain a link to a short game. We demonstrated that attempting to enter a new username when one had already been set would correctly return the error that a username had already been set. We then demonstrated that the badge could be reset and a new username could then be set for the badge. Alongside regular usernames, we also demonstrated two “secret” usernames that would have a unique text output if the user entered them correctly. The first game link functioned correctly and allowed the user to play a dino game. Completion of the game allowed the user to discover another “secret” hidden in the developer console of the end screen. This secret code could then be entered in the fifth secret option of the program, and upon being entered “SUCCESS” was displayed. Upon trying to reenter the secret code, the device did not allow it and instead again displayed “SUCCESS”. Furthermore, we demonstrated that the secret code was created using an XOR cipher and users can decrypt it using clues given from game 1. We then demonstrated the coin flip (game 2). The game functioned correctly and we discussed how a secret code is added into the cookies on the site. We described how a user can utilize the polybius cipher to get to the correct hash, and also how they can wipe their progress on the board using the incorrect hash. We then demonstrated game 3 on Derek’s machine, including the custom game engine that he wrote to allow input from any tsv into the game. The game takes a long time to complete so we did not demonstrate the winning condition but did show that the secret phrase is reachable. We also described the unique losing condition for game 3 which includes a fork bomb on the users machine if they choose a certain option on day 25 of the game. Finally the reset functionality was shown, with the user able to cancel the reset if need be: this takes advantage of both buttons on the MSP430.

### Conclusions:

The 2nd prototype testing was a complete success. Games 1 and 2 ran well on the browser, and the demonstration of game 3 went extremely well! Other than that, all of the ASCII graphics displayed fine, and so did the menu. There were no issues this time with any Serial input which was something we updated since the last test. Following all our successes, the group is ready to finish bluetooth implementation and to add the alphanumeric display onto the badge. Additionally, we want to continue Professor Osama’s request to “rotate through” different tasks on the team to prevent burnout and continue “having fun.”

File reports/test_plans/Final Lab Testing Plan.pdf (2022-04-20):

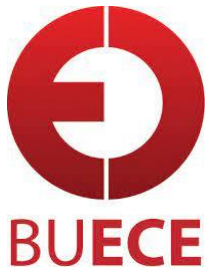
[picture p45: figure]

## Boston University Electrical and Computer Engineering

EC464 Senior Design Project

# Final Test Plan

# VETCON

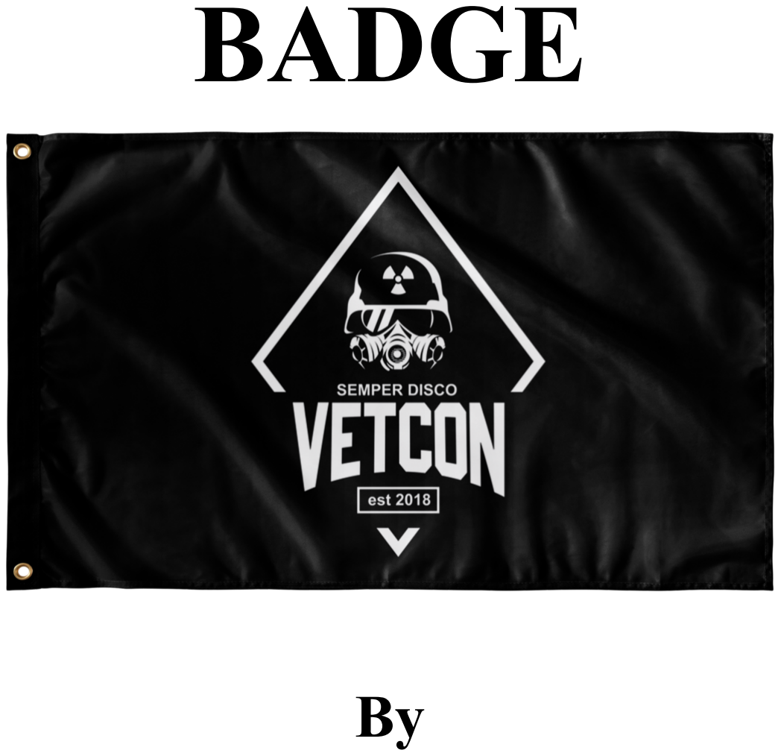
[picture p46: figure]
BADGE

Team 32

Team Members

Derek Barbosa, dbarbosa@bu.edu John Kirche, kircherj@bu.edu Carlos Ortiz, cartex10@bu.edu Ryan Sullivan, ryanbs@bu.edu Julian Padgett, jpadgett@bu.edu

### Equipment & Setup:

The equipment used for our prototype testing followed the hardware and software specifications listed below.

Hardware:
1. 2 Texas Instruments (TI) MSP430FR2433 LaunchPad™
a. 16 bit MCU
b. 20-pin LaunchPad Kit Standard Leveraging The BoosterPack Ecosystem
c. On-Board eZ-FET Debug Probe
d. 2 Buttons And 3 LEDs For User Interaction
e. 2 HC-05 Bluetooth Modules
f. 2 LCD Alphanumeric Displays
2. 2 Computer/Laptops
3. 2 Micro USB Cables
a. Connection Between MSP430 & Computer
4. Arduino, Wires, Resistors, and Extra LEDs for Testing

Software:
1. Visual Studio Code
a. Source Code Editor
2. PlatformIO
a. Cross Platform / Cross Architecture IDE tool
b. Embedded Application Software Development
3. Scripts
a. C++ Script, main.cpp
4. Package Extensions
a. Monitoring Button State & Debouncing
5. Github Pages
a. Hosting Of Web Games
Setup:

The setup for our final testing was very simple. One of our team members cloned our Github repository with our prototype code from the testing branch. The project was then opened with PlatformIO on the Visual Studio Code IDE. Following this, the MSP430FR2433’s were connected to 2 team members' computers with the micro USB cable. Using PlatformIO, the project was built and flashed onto both boards, ready for demonstration. Furthermore, a breadboard with correct pin connections to the 3 LED’s, LCD, and Bluetooth module was set up for each MSP.

Testing Procedure:

### 1. Initialize the MSP + software (build, upload, and monitor)

2. Demonstrate option 1 (Set Name Tag)
a. Demonstrate that repeating option 1 prompts message that name has already been set
3. Demonstrate option 2 (Display Name Tag)
4. Demonstrate option 3 (Game Link)
a. Demonstrate the Dino Game
b. Show winning condition secret code
5. Demonstrate option 0 (Reset)
6. Demonstrate secrets
a. Show a secret username through option 1
b. Select option 3, prompting “access denied”
c. Select ‘secret’ option 9, unlocking option 3 in the menu
d. Enter secret token from game 1, changing LED1 state
7. Demonstrate option 4 (Game Link 2)
a. Demonstrate the coin flip game
b. Select option 6 again and enter secret token from game 2, changing LED2 state
8. Demonstrate Game 3 using code from Game 2
a. Demonstrate the game
b. Select option 7 again and enter secret token from game 3, changing LED3 state
9. Demonstrate saved data between device power states
a. Disconnect device from power and show that it is fully off
b. Reconnect device to power and show the information saved in the previous session
10.Demonstrate option 8 (Bluetooth)
a. Show bluetooth communication between both MSP’s
b. Demonstrate exiting the bluetooth menu

### Measurement Criteria:

1. VETCON BADGE displays on startup
2. “WELCOME TO VETCON 30” is printed to the LCD
3. Main menu displays in terminal
4. User can select from given options
5. User can enter name to nametag
6. User’s name can be displayed on the LCD
7. Game link(s) can be retrieved
8. Online game(s) run (Game 1,2,3)
9. Secret phrase can be retrieved on winning the game(s) (Game 1,2,3)
10. All LED’s turn on corresponding to their secret phrase being entered
11. Users can send and receive data by Bluetooth
12. User can reset badge
13. User can select to abort / continue with reset
14. User can power off and on the badge without data loss

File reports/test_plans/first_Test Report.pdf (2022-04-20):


## Boston University Electrical and Computer Engineering

EC463 Senior Design Project

# First Prototype Test Report

# VETCON

BADGE

Team 32

Team Members

Derek Barbosa, dbarbosa@bu.edu John Kirche, kircherj@bu.edu Carlos Ortiz, cartex10@bu.edu Ryan Sullivan, ryanbs@bu.edu Julian Padgett, jpadgett@bu.edu

### Equipment & Setup:

The equipment used for our prototype testing followed the hardware and software specifications listed below.

Hardware:
1. Texas Instruments (TI) MSP430FR2433 LaunchPad™
2. Computer/Laptop
3. Micro USB Cable

Software:
1. Visual Studio Code
2. PlatformIO

The setup for our prototype testing was very simple. One of our team members, (in this case, Ryan S. team-lead 2) cloned our Github repository with our prototype code from the testing branch. The project was then opened with PlatformIO on the Visual Studio Code IDE. Following this, the MSP430FR2433 was connected to the computer with the micro USB cable. Using PlatformIO, the project was built and flashed onto the board ready for demonstration.

### Measurements Taken:

1. VETCON BADGE displays on startup
2. Main menu displays in terminal
3. User can select from given options
4. User can enter name to nametag
5. User’s name can be displayed
6. Game link can be retrieved
7. Online game runs
8. Secret phrase can be retrieved on winning the game
9. User can reset badge
10.User can select to abort / continue with reset

Upon startup, VETCON text was displayed correctly alongside the menu of options in the terminal. All options were able to be selected by the user during the demonstration. These options included the ability for the user to enter a username, change their username, display their username, and obtain a link to a short game. We demonstrated that attempting to enter a new username when one had already been set would correctly return the error that a username had already been set. We then demonstrated that the badge could be reset and a new username could then be set for the badge. Alongside regular usernames, we also demonstrated two “secret” usernames that would have a unique text output if the user entered them correctly. The game link functioned correctly and allowed the user to play a dino game. Completion of the game allowed the user to discover another “secret” hidden in the developer console of the end screen. This secret code could then be entered in the fifth secret option of the program, and upon being entered “SUCCESS” was displayed. Upon trying to reenter the secret code, the device did not allow it and instead again displayed “SUCCESS”. Finally the reset functionality was shown, with the user able to cancel the reset if need be.

### Conclusions:

The first prototype testing was a complete success. The game ran well on the browser, but there were small issues with lag during gameplay. Other than that, all of the ASCII graphics displayed fine, and so did the menu. There was an issue discovered during testing where the user did not have enough time to input a specific easter egg name, so that is an important issue that will need fixing. Due to this, the group is ready to begin implementing an LCD screen into the next prototype. According to Professor Osama’s request, we will continue to “rotate through” different tasks on the team to prevent burnout and continue “having fun.”

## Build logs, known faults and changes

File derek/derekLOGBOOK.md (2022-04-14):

# Senior Design Session 1 Logbook.

Copyright Year 2021 Derek Deoliveira Barbosa dbarbosa@bu.edu
https://www.github.com/derekbarbosa
https://www.dbarbosa.net

## September
Entries here will be reserved specifically for the remainder of September.

### 9/20/2021
* Project Teams are assigned.
* Assigned to Team 32 -- VETCON BADGE
* Reviewed and began to interact with team members

### 9/21/2021
* Regrouped with team. Took team photos, decided to hold off on hitting the ground running until the following day

### 9/22/2021
* Started a Slack Workspace to manage group communication
	- Integrated BU Google Workspace Calendar into Slack Integrations
	- Started a Trello Board to manage project details, integrated to Slack
	- Created a Team Calendar to keep track of "who is in class" and facilitate the arrangement of meeting times.
	- Got in contact with client to arrange meeting time. Tentative for 9/24/2021 3PM Eastern.
	- Assigned the task of formulating questions for the client for further information on desired specifications to team members who would not be present during the inital cient meeting.

### 9/23/2021
* Finalized meeting details with our client. Confirmed for 9/24/2021 3pm eastern.
* Began drafting questions based on project requirements. Instructed group members to do the same.
* Set up a GH repo for our documentation. Linked to Slack Channel using webhooks to keep version control hygiene.

### 9/24/2021
* Met with clients! 
* attached notes for client meeting
* Ryan said he would take care of the inital PDRR writeup, will pause work for the weekend.

### 9/27/2021
* Brainstorming approach to IC/embedded system approach as described by client
* during review of the product specifications, clients emphasized battery life and weight
	* asked us to be somewhat conservative with the tradeoff
* started to look at TI-83/84 PCBs, determining best practices to create a low-power system with programmable memory.
* attaching notes to this upload :)

### 9/28/2021
* talk about rabbit hole research about calculators and low-power electronics
* Did a little more research on calculators and their "mini" operating system
	* this is following up on the design requirements from the client. They desired something that was "hackable" and easily "dumpable." They didn't need a "full" OS as we know today (Raspbian, etc) but would be fine with basic operating systems/firmware controller software.
	* Why so much research into calculators -- they are low power "embedded systems" that run off of AA batteries (less than 1100 mAh) for months at a time, with built-in save state and sleep cycles. Programmable Memory + ROM combination with fast (near instant) boot times.
	* Specifically looking into implementing KnightOS, a FOSS calculator OS that can run on TI-83/84s.
	* TI-83/84/84plus/84CE run on Zilog Z80, same processor in the old Sinclair Computers and other older computing systems. Easy to breadboard and fairly understandable datasheet compared to more modern microprocessors. Fairly straightforward ASM implementation as well if any need to get "manual" with the code.

* Much harder than just plugging in a Raspberry Pi Zero/Zero-W and calling it a day. But you get massive flexibility tradeoff + battery life
	* RPI consumes 1A with a few plugins/accessories running, would need 120WH battery (bigger than FAA/FCC limit) to power the device for 24 hours
	* RPI allows for easy compatiability with COTS components and rpi-approved "hats" out of GPIO plugins
	* benefit of working with linux kernel directly + debian-based OS tools.

* Met with Team -- reviewed the zoom call notes and discussed the approaches above. 
* Assigned John Kircher as the Team Leader for the first rotation. He will be working on the PDRR. I will contribute to the slide deck.

## October
Entries here will be reserved specifically for the month of October.

### 10/1/2021

* Researched ISA/Microprocessor compatability with KnightOS and Espilon OS (open source "calculator" operating systems that can be forked and edited for specific functionality.

* Began to look into parts ordering, accounting for 50 dollar budget.

* Created a slides template for the PDRR review

### 10/3/2021
* Preparing for PDRR initial presentation 10/7
* Not many new updates -- quick tag-up with team about next steps and what "we want to do" with our lead time
* Reviewed Presentation slides and script, made some edits to specifications
* Began working on PDRR written report

### 10/5/2021
* Attempted to find an easier middle ground between high-power (but flexible) SBC (single-board-computer) such a rasberry PI and manually soldering together an MCU and ROM.
* Encountered complete "embedded" development kits, closer to an SOC (think Arduino Uno's ATMEGA MCU / ESP32) but with an emphasis on ultra-low power consumption without entirely sacrificing QoL IDE tools
	* Board(s) of question: Texas Instruments "LaunchPad" development kits for the ultra-low power MSP430 MCU family -- https://www.ti.com/design-resources/embedded-development/hardware-kits-boards.html#launchpad
* Why this approach? 
	* As mentioned in the bullet above, Power Consumption is something our team needs to account for at all time.
	* The MSP430 famiy consumes 1.3 µA on average, and can still send enough power to "juice" a LFR display.
	* "mini" or "micro" MCU devkits allow us to have a consistent environment to prototype our code if we decide to just use an MSP430 and ROM soldered directly onto a board.
	* Enables flexibility with IDEs and built-in code snippets for code re-use
	* Can also leverage other family of MCUs, such as the ESP32 family.
	* Specifically, the FireBeetle https://www.dfrobot.com/product-1590.html -- has a low power consumption of 0.011 mA.
* Next steps?
	* Do some research of sample projects using these DevKits -- what are some issues that developers run into when debugging these boards
	* Look at some other DefCon badges that leveraged Arduino/arduino-like SOCs (especially their open-source git repos)
	* Review datasheets and peripheral compatability
	* Relay research back to Client -- inform them of approach
	* Compare SOC approach vs SBC vs Bare-Metal
	* Look into reverse-engineering SOC into bare-metal PCB
  
### 10/8/2021
* Regrouped with Team -- agreed to vote on specific approach next monday.
* Discussed at length the pros+cons of each architecture, we described our preferences and laid out our "greivances"
* Relayed that we might not hit power consumption requirements if we follow up with RPI approach.
* Decided as a team to "take off" until after Indigenous People's Day

### 10/12/2021
* Team has decided to go with DevKit approach. I will put orders in for MSP420s (low power) and Arduno Minis (that can leverage the low-power settings)
* Will also put in an order for a Digital Multimeter, maybe some breadboards too (so they can arrive in time).
* Started drafting some sketches describing how we would program the SOC memory using the built-in IDEs provided to us.
* John released the first draft of our PDRR -- Started to revise and edit some of the content for the final review prior to submission

### 10/15/2021
* Started to review datasheets for the MSP420/430 programming specifications
* installed the Eclipse-based IDE and verified debugging functionality (IDE specific to the TI LaunchPad board)
* Gathering materials and slide decks to present to our client again this saturday.
* Putting in orders for additional LEDs and Breadboards -- looking into drafting some starter designs to meet the creative aspect of the assignment.
* Began to look for example code to pull "inspiration" about starter code.

### 10/18/2021
* Discussed upcoming "plan of attack" with team. Realigned goals and applied pivots to tasks.
* Established a variety of roles for the project:
	- Software
	- Power Consumption 
	- Hardware/PCB design
	- Hacking Minigame
* The four roles align somewhat well with the 5 teammembers, as we have a good mix of skills. I volunteered myself for SW debugging
* Discussed how to set up our inital dev cycles upon arrival of our hardware (TIMSP430).
* Filled in the rest of team on how/why we should consider meeting up once or twice a week to do merges and progress meetings (to align with agile fashion)
* Presented MVP to VETCON Client, edited slides to reflect Shark Tank Presentation.

### 10/20/2021
* Hardware has officially arrived!
* Touched up the PDRR report
* revised our slides for Shark Tank
* Received excellent manufacturing advice from transitioning from SOC --> Custom PCB with MCUs, got the contact info of a manufacturer
* Received advice to leverage security exploits on ISA/MCU architecture to bring "social attention" to the platform.
* Devised approach of working from individual application layers down to a platform/bootloader

### 10/21/2021
* Last logbook entry before due date!
* Looking into setting up our CI/CD and pipeline hygiene, will set a workshop for Gherkin Model user story writing to "nail down" our functionality and describe "pin-pointed" features
* Looking into LCD libraries for TIMSP, and how to not only write sample code, but also flash binaries into the rom
* looking into creating a Basic Input Output System to control the memory management of the applications and inpit (BIOS).
  
### 10/26/2021
* First logbook entry for Logbook #2
* Set up a CI/CD Pipeline, officially all unstable code will be pushed to our invididual branches. Once functionality is confirmed, code will be merged to testing for debugging on secondary boards and then relesed to stable once we are satisfied and decide to start another function.
* Essentially team member scratchpads --> testing --> main
* Our First IDR went well, only feedback from Prof Osama was to bewary when opening up the repo and to ensure that there isn't too much involvement from the client side.
* Discussed logistics of Trello/Agile and User Story Writing using the gherkin model. Wrote a sample story to discuss how tackling solutions using "the smallest vertical slice" allows for concision and accuracy when describing functionality from a user perspective.
* Began to play around with some test code from TI and using TI dev tools. Got an LED to blink (our helloworld) and was able to wrtie scrolling text using the segmented display built into the evalutation board.
* Set up a meeting with the client to touch base and discuss project status. 
  
### 10/28/2021
* User story session 1! Wrote our first Epic. Epic #1, Gilgamesh, has 4 user stories which focus on the inital functioning of the badge, AKA "main menu" functionality.
	* Story 1: First Boot/Power On Sequence
	* Story 2: Main Menu and Bootloader
	* Story 3: Main Menu Navigation
	* Story 4: Program Execution and Return
* Trello Board link will be made public eventually!
* Along the way we also made the following design decisions:
	* Attempt to source another LCD module which will allow us to draw custom graphics.
	* If that doesn't pan out, either use the current LCD on the evaluation/development board AND use the badge itself as a "serial" console to PC/make an application that uses the terminal output as it's GUI.
* We also decided on the following roles
	* Derek & Ryan -- Software
	* Julia * John -- Cybersecurity and Display Modules
	* Carlos -- Design/Architecture
  
## November 
Entries here will be specifically reserved for the month of November.

### 11/2/2021
* Start of Sprint 1: My+Ryan's role is to interact with the bootloader for the MSP420.
* GIT Logs here:
	* adding bootloader to src -- COMMIT 10EAB35
	* adding mspboot and apps to repo -- COMMIT 01fb27c
	* cleaned up stuff. Deleted old objects and cloned samples of bootloader -- COMMIT 3ac7051
	* attempting to figure out what is going on with gmake compile errors -- COMMIT f322794
  
## 11/3/2021
* Rewriting <include> files to get the demo bootloader applications to function on non-windows systems
	* the demos written by the TI team were targeted for windows, so a lot of the dependency paths are written with "C:\" Win32 style NTFS directories rather than the standard Unix-like method of accessing directories from root "/usr/bin"
* Gmake continues to fail on compile, potential broken Gmake modules
* Build failures attributed to "all" target failing. I am suspecting that the built-in makefile may be broken.
* Came to realization that the demo files were written with an older version of the MSP compiler in mind, newer versions of the compiler break the "all" build rule in the makefile.
* Downloaded and installed a new version of the compiler, .c files are able to be compiled with succesful output.
* However, getting the bootloader to load and switch between two applications (at least with the demo files) is a bit of a complicated process:
	* For some reason, the demo requires us to compile the C code, which results in a .txt file being generated.
	* This .txt file needs to be copied to a certain directory for both applications (App1 and App2)
	* Once copied, the .bat (windows batch file) for some reason takes the .txt file and uses a python script to convert it back to C (weird, right?)
	* The both C files are then compiled down to one object and passed onto the bootloader. A host board is then required to flash the target board with the desired programs.
	* All in all, overcomplication for something that was supposed to be a bit more straightforward. The tutorial seemed to provide an example of how to provide OTA updates rather than focus on creating a bootloader.
* Ryan and I are scrapping this approach and will simply write our own self-contained bootloader that will simply be an application that calls different appications in memory.

### 11/4/2021
* First attempt at creating our own bootloader was highly unsuccesful. We were not able to compile code that was effective in getting anything done.
* Documented some issues with the TI Documentation. Decided to stop and focus on helping other teammembers complete their tasks.
* Assisted Carlos in getting KiCad reinstalled after major vulnerability expoit in the binary was leaked.
* Assisted John and Julian in getting their serial console to "print something"
* Set up a clean instance of the IDE back to a "hello world" state.

### 11/8/2021
* Met with Ryan to arrange time on Tuesday to get a headstart before prototypes, want some sort of "app loader" functional by Thursday.
* Played around with the LCDs and read up on datasheets to better understand them.

### 11/9/2021
* Discussed Upcoming Pre-Prototype plans and reviewed the assignments posted on Blackboard.
* Specifically, we discussed our challenges at hand (see previous logbook entries) and how we should potentially move to a simpler approach.
	* Discussed how we were not able to access the bootloader and rewrite "what was there" to reimplement our own - cause of concern for a few reasons
		1. We have NO idea now how much ROM is actually available to us since the BSL (base bootloader)
		2. Not sure how writing a simple App loader un top of the BSL will interact with memory
	* Texas Instrument's Documentation on the bootloader isn't great, actually flashing bootloader code is a very convoluted process that isn't friendly with other environments
	* Putting a large game alongside other applications will prove to be difficult. 
* Assisted Julian with getting serial output to print a Char Array.
	* Was difficult because we had to specifically manipulate a 16 bit register responible for the output stream
* Investigating the PlatformIO suite (https://platformio.org/) which would allow for easier debugging and monitoring of serial output for embedded system.
	* According to the documentation, the TI-MSP family is supported, specifically all of the EXP (launchpad) boards are suitable "targets" for the Plugin.
	* Because the plugin runs purely in Python, it is compatible on all environments -- suitable for use across the team and on VMs if needed.
	* Specifically, the PlatformIO plugin provides a flexible IDE in a modern environment (VSCode vs Proprietary Eclipse IDE)
	* The build process automatically tags SW dependencies and applies them automatically during the build stage, removing plenty of the compiler issues we were running into.
	* This could also help with the issue we're currently having: monitoring serial output consistently across dev machines (different environments handle USB comms differently) and allow us to create consistent output on our applications.
	* Warrants further investigation
  
### 11/11/2021
* Discovered serial output can be manipulated on the board by clearing, setting and flipping a 16 bit (2-byte) register.
	* Challenge presented: how to continually clear and set the output register with preprocessor directives.
	* Setting a outer while condition while iterating through the character bytestream did not prompt any success
* Carlos, responsible for PCB design asked what he could do in the meantime to "fill the void" while we pushed down the path of attempting to get communication functional on the board
	* I proposed he do our game development side of things, so far we have a Dino Run prototype going :)
* We decided to meet again the following day to get some more progress going
  
### 11/12/2021
* PlatformIO was super succesful! Writing serial output proved perfectly fine, and we are now able to import third party libraries with ease!
	* We can now print to console output and use board functionality
* One issue: Mapping of IO pins from the cross-compiler "environment" to the native pins on the board is a bit murky, so todays session was figuring out "what mapped to what"
* Otherwise, we are in the clear so far.
  
### 11/13/2021
* Met with the team over the weekend to do some more work in preparation for the prototype
* Set up Serial Interface loop, follows typial REPL methodology to parse user input and accept valid commands. Helper functions were established to jump to different locations in memory to execute desired functionalities.
* Added functionality to display text/ASCII graphics to serial monitor
* Attempted to include button functionality, ran into problems trying to get button inputs to "read" properly. Issues we had and suspicions are listed below
	* Button presses only worked properly within our void loop() function, which sits atop of the Return Stack Pointer on our call stack, so we suspected that buttons in functions that were called from loop() were consequentially "higher up" on our stack, and therefore unable to be properly "sampled."
	* Another suspicion we had, which was similar to the one above, was that the hardware could only be accessed in non-blocking functions, so we decided to write an interrupt that attached itself to a button pin, which ultimately proved unsuccesful 
* After attempting to correct button issue, we called it quits for the night.
  
### 11/15/2021
* Included button debouncing libraries to correct our input problems. Buttons are now able to be properly read albeit with very slight delay.
	* Why does this work? The buttons on the TIMSP430-EXPFR2433 specifically have "pullup" properties, meaning that the rising/falling edges aren't exactly "clean" and can't be reliable sampled. 
	* Including a debouncing library takes care of button "bounce" (i.e. what happens when you press and release a button) and accounts for the delay between presses.
* Took care of repo sanitization, testing branch is now up-to-date.
* Hosted Carlos' Dino game on Github Pages
  
### 11/16/2021
* added the URL to the webgame to our device!
* preparing for prototype testing

### 11/18/2021
* Prototype Testing went great, only feedback from Professor Osama was to "keep it up" and to continue to "have fun" with the project.
* Today we set new goals for until the "end of semester"
	* emphasis on polishing our software and our peripheral interfaces before we go into hardware design for the following semester.
	* allows us to focus on writing a better serial interface and providing "fun" interactivity with the badge.
* Roles have been reassigned for the remainder of the semester:
	* Derek -- web games
	* Carlos && Ryan -- memory interface
	* Julian -- Obfuscation of code
	* John -- LCD interface

## December
Entries here are reserved for December

### 12/2/21
* Finished the majority of our written tasks. No updates in logbook because of deadlines. Not much technical progress other than finishing PDR slides, individual reports, team contracts, video, etc.
* Began brainstorming potential scenarios for "verifying" communication between boards. Started work on BLE modules.

### 12/7/21 
* Began efforts to clean up GIT repos, pulled latest commits into some branches
* Continued drafting of final semester report. Assigned parts and gathered evidence/logs/info for said report.
* Discussed future semester plans with rest of team, discussed action items and reassessed "problem areas"
	* for example, discussing the worth of wireless communication and its compatibility with current approaches and tech stack.

### 12/11/21
* Report due tomorrow 9 AM, finished writing up technical plan/report (my section of it)
	* Highlighted the performance period and divided the major phases of technical development
	* Phase 2 has 3 tasks, ranging from a SW wrap up period to a circuit design schematic
	* Phase 3 is final integration, with system testing and packaging as the final tasks
* Taking hiatus from the project to rest up and recharge!

## END OF 1ST SEMESTER SENIOR DESIGN
Entries from this point are reserved for Spring Semester EC464

## January
Entries here are reserved for January
Note for reviewer: I already spoke to Professor Osama regarding this issue: but I forgot to push and commit my logbook over the Winter Break. The next few entries have NOT been backdated, but were just stored locally (not commited) due to my negligence. I will be linking documentation providing POW under each entry.

### 1/7/22 
* Contacted the rest of the team to begin preparations for upcoming semester
* Got in contact with the client as he requested an update/plan for a meeting the week of the 28th
(see screenshot labelled 1-7-21 attached)
 
### 1/20/22
* Team reconvened over slack/SMS to discuss upcoming deadlines.

### 1/25/22
* First "real" in-person team work session
* Ran into several issues with Bluetooth, current BT HW only programmable via CCStudio which we want to avoid as it is a problem for various reasons.
	* Currently, we are using PlatformIO, which works off TI's Wired Framework (a FOSS Framework) that is compatible with Arduino code. PlatformIO leverages this header from the Wiring Project that is currently used in TI's Ardunio/Wired IDE, Energia, and enables community code-snippets and "dependencies" for button debouncing/delay and etc (as mentioned before in this logbook)
	* Having the BLE/BT HW only programmable through CCStudio throws a wrench in our current tech-stack as there is no way we can (feasibly, with our time and skills) port over the Wiring Framework to a niche BT Device like ours. 
	* Currently, we plan on programming the full BT functionality through the device itself, flash it, and use it as a simple add-on to the main board as an "accessory" and nothing else. We are still drafting a better approach, that will require a bit more brainstorming.
	* Making progress on EEPROMs, just ordered a batch.
	* Info on Wiring here: https://github.com/WiringProject/Wiring 

### 1/26/22
* Pulled sample code of "coin flip" game the idea/plan-of-execution is the following:
	* User goes to coin-flip website to receive secret code
	* User "flips" the coin.
	* User receives either-heads-or-tails, but no secret is delivered (obviously)
	* Secret code will be hidden as a cookie on the user's device, with a 50-50 chance that the code is the correct one, and not a red herring.
	* Code will be "hashed" within the cookie, if hashed correctly, the incorrect code will be apparent that it is incorrect.
	* Entering the incorrect code will wipe the EEPROMs and reset the badge progress. The correct code will advance the user's progress.
* Looking into how to store cookies on-browser with JS libraries.

## 1/27/22
* Worked on the Coinflip game. Have the basic HTML structure ready to go, still lacking cookie storage and need to develop a key for the hash.
* IDR today -- briefed Osama on our progress, he is pleased! :) 
	* Relayed our concerns with our bluetooth modules and conflict with current tech stack. May require a future pivot if things don't go well
* Continued to work on the coinflip game, fine tuning graphics and pulling sample code from internet (sources will be sited in that readme)

### 1/28/22
* Met with Mike -- relayed our concerns and frustrations, he understood them and assured us that we were on-track and meeting all of his requirements and specifications.
* Discussions about contingency plans if Bluetooth connection does not pan out.
	
### 1/31/22
* Referenced the mozilla docs https://developer.mozilla.org/en-US/docs/Web/API/document/cookie for incorporating cookies into our webgame
* Editing source code to make it more *unique* to our project, including handling for cookie setting/resetting
	
## February
Entries here are reserved for February	

### 2/3/22
* Finished the Webgame! The source code will be available at github.com/derekbarbosa/EC463Webgames2

### 2/8/22
* Started game 3! Text based adventure written in CPP
* Managed to directly write to the board's FRAM, makes it easier to store programs for future use. Able to get persistent memory between various boot sessions.
* Began to brainstorm game 4 alongside game 3 development... suprise for now :) but will involve data recovery and various cybersecurity "red herrings"
* Still pursuing bluetooth debugging, with eventual conversion to platformio in the works.

### 2/10/22
* Continued to work on game 3, so far, here is the design "schema"
	* console-based text game, written in CPP
	* "time-based" activities -- each action consumes a "unit" of time, if you run out of time you lose
	* You are tasked with an objective, the game takes place over a day, and you must complete smaller, cascading tasks to reach the final "goal"
	* Very akin to the early-90s style text-based "choose your own adventure" game.
	* Signficiant less "cybersecurity" focus than the other games. This game is more geared towards confusing "multiple pathways".
* Regarding the technical structure of the game:
	* Core functions file with corresponding .cpp to flesh out core functionalities
	* Main game loop handled in game.cpp
	* user input will be grabbed and santiized in the same way, using a "grab" function to main consistent santization
	* every "action" reduces the time counter by a set amount based on initial decision
* Adding support for multiple pathways (eventually) and multiple endings. Only the "best ending" will print the code 

### 2/15/22
* Chrono support added, program is able to sleep/stop on demand
* Continued work on fleshing out functionalites for IDR this thursday

### 2/16/22 
* Finished "skeleton" of game 3 -- all structures and inits are tested and fleshed out.
* moving on to writing text based scenarios 

### 2/18/22
* Spent the day with the team brainstorming "scenarios" for the text-based game
* Game style will be similar to "Reigns" -- see the link here: https://reignsgame.com/
	* instead of being a "king" you are a BU student, trying to navigate through the semester and manage your four attributes
    	* Money
      	* Social
      	* Grades
      	* Health
  	* If any of these get too low, you lose!
* See previous notes for info on "update" functions for updating stats and user profiles
* Text-based scenarios will be fed through, parsed and set up in a "linked-list" structure
* IDs pertaining to each scenario will determine stats/choices.

### 2/22/22
* Edited file headers, light code refactors. Investigating how to parse textfile to feed into structs.

### 2/24/22
* Importing .xlsx to TSV (tab separated csv) and using getline() with 't' delimiter. 
* Created structs with proper IDs to feed text into scenario.
* Almost complete with game 3 :) 

### 2/25/22
* Running into a weird heap memory error. Attempting to debug by initalizing memory with class constructor
* Pushing code up for Ryan to help debug. GDB is broken on MacOS

### 2/27/22
* Even after some refactors, initializing memory in a separate CPP file is causing segfaults to occur when accessing said ptr in game.cpp (main)
* Doesn't occur when dereferencing memory that is allocated in main. 
* Weird behavior considering that both instances of mem are allocated on the heap and therefore can be accessed by dereferencing, rather than on the stack.

### 2/28/22
* Continued investigation of the segfaults yield no results. Will attempt to brute force by manually allocating in mem.

## March
Entries here are reserved for March	

### 3/1/22
* Bugfixes with multi-level pointers across files. Passed pointers by reference using "&" and dereferenced using, mistake made between passing pointer-to-value and passing pointer to pointer to value.
* Cleaned up value parsing with Getline. Points and point values are now completely parsed on the backend with string matching, stringstreams and getlines.
* Added support for point calculation and parsing persistent point values to front-end game loop
* finished global update function which calculates points & etc.

### 3/2/22
* Added support for multiple endings within game, different outcomes occur based on point values of each attribute of the "User Profile"
* Increased game difficulty, no longer *easy* to do the game in one complete run.
* Added persistent point support. Persistent flags now trigger a continuous increase/decrease in point valuation. 
* Fixed some formatting oddities.
* Game is complete and in "production mode" as of today! 
* Moving onto HW, testing power consumption of prototype

### 3/3/22
* Merging my branch into testing
* Cleaned merge conflicts

### 3/4 to 3/26/22
* Playing some catchup with logbooks because it was an eventful few weeks.
* Lots of EC464 busywork, prevented me from updating this the way I should have.
* 3/5 to 3/14 was Spring Break, so not many updates between those two dates.
* 3/15/22 - began testing power consumption of MSP and semi-completed circuit. Determining draw of circuit to account for the 20-hour battery life of device as specified in client requirements. Preparing for CDR presentation by tying up loose ends (bluetooth and code "ciphers").
* 3/17/22 -- Bluetooth in working state! Working on presentation for CDR, small work/regroup session afterwards.
* 3/21/22 - Ditched addressable LCD for a 16x2 Segmented LCD for ease-of-use. Addressable LCD refuses to play well with MSP headers. Prototype and "hello world" completed. Intialized LCD class/objects in codebase as well as some function prototypes for user-functionality. 
* 3/22/22 - Updated our client on progress so far:
  * Software Portion Complete/Polished and in-working state
  * Bluetooth Functional
  * Games 1-3 finished
  * Persistent State
  * Serial Communication Complete
  * Hardware -- mapping pins to schematic for PCB preliminary design
  * User Manual/Budget -- Device is on track to be sub-50 dollars. User manual due following Friday.
* Determined battery life of complete prototype (LCD, BT, multiple LEDs) w/ 500mAH 9v battery is 3-ish hours. Looking into NiMH batteries to provide desired capacity.
* 3/23/22 -- Investigating using automated main/rechargable battery switching with LiPo charging ICs (TP5410 and 4506)
* 3/24/22 -- User Manual draft complete, submitted.
* 3/25/22 -- Investigating flashing firmware.bin files without need for source code!
* 3/26/22 -- Updated logbooks to reflect progress made

### 3/28/22
* Day dedicated to writing out final testing plan
  
### 3/29/22
* Final testing. 
* Professor Pisano and Professor Osama had requested, that for ECE Day, we modify our material as a "learning course" or bootcamp to be more attractive to passerbys
* No other updates. Slight code refactors. 
* Began Power consumption testing w/ completed circuit and NiMH 2800 mAh batteries

### 3/30/22
* Battery results were promising! 15-16 hours out of 3x 2800 1.2v batteries from NiMH in AA form factor.
* Some other battery stats from testing
  
* Remolded Stats:

	*Using 500mAh 9 volt battery 
	*Lasting around 3 - 4 hours
	*Circuit consumption: 125mA - 160mA drain.

	*Using 350mAh 3.7 volt battery
	*Lasting around 2 - 3 hours
	*Circuit consumption: 120mA - 175mA drain

	*Using 3x 2800mAh 1.2 volt batteries in series: (3.6 volts)
	*Lasting around 15 - 16 hours
	*Circuit Consumption: 175mA - 185mA drain

* Here is where we are at:

* Today I refactored the code on my branch to lessen power consumption. 
* By replacing delay() with sleep() we are able to enter a lower power state on the board and draw less milliamps
* With this, I had the idea of creating an LED control menu. 
* It is assigned to key ‘9’ once all secrets are unlocked. 
* Here, users are able to choose to to turn off their LEDs, enter a ‘wave’ mode, ‘blink’ and ‘alternate blinking’ mode.
* The idea was to attach an interrupt to one of the push buttons and attach a startup routine to the interrupt call and make it so that the LED functions just keep looping over and over again until disrupted. 
* In the ‘OFF’ state we would just put the board in the lowest state, suspend() which draws little-to-no power, and in the other functions we would just have it microsleep to save power.
* The current issue is that we block and wait for serial at full power, but by doing the above we can circumvent that until i find a way to attach an interrupt routine to serial input. 
* some references:
  * https://embeddedcomputing.weebly.com/ultra-low-power-with-msp430.html
  * https://electronics.stackexchange.com/questions/228181/how-do-you-use-low-power-mode-on-an-msp430g2553-using-an-energia-sketch
  * https://forum.43oh.com/topic/8608-energia-ide-msp430f5529lp-low-power-mode/
  * https://energia.nu/reference/en/language/functions/time/delay/

### 3/31/22
* Meeting with client!
* Greenlight battery life, and green lit 'swappable' batteries as opposed to building a charge/boost/protect module into our circuit for time constraints.
* Spent more time attempting to program interrupts. No luck so far. Will reconfigure push buttons in attempt for power-save and customization control.
* Energia interrupts() detected properly outside of loop() (similar to issue at beginning of last semester), need to figure out how exactly im going to afford the user control over LED menu

## April
Entries here are reserved for April	

### 4/1/22
* Not many updates
* 18650 has 23 hours as of 5:00 pm. Fantastic
* Exploring options of moving game 3 code into docker container for higher cross-compat.

### 4/4/22
* Finished push-button and sleep() code, refactored/refined codebase and finished LED menu support
* Looking into adding physical toggle for LCD backlight
* began looking into enclosure manuf. for ECE day

### 4/5/22
* Upon further inspection, Button 2 is the only button onboard that does not have a 1-for-1 digital pin representation (pin 2.3) on the TI MSP430 EXP-FR2433 module
  * Refactored code to work solely off button 1. Slight changes in LCD menu logic to detect button1.pressed()
* Discussed PCB design with Julian and Carlos
* Began exploring resources for 3D-printing the enclosure for the MSP, PCB, Battery, LCD, and Switches.
* Began testing fit of a protoboard on the MSP. Plan is to create a makeshift "hat" for the MSP and pull all necessary leads from there.
  * Eventually final PCB design will be similar, but have resistors/LEDs pre-assembled on board.
  
### 4/7/22
* Wired a hardware circuit and refactored the code to work solely off button2 (pin 2.7). Physical push button wired to digital pin now works as intended.
* Tested some switches to cut off battery power, planning to append shottkey diode post-PCB
* On track to get schematic sent out this Friday

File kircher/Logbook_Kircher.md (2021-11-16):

# EC463 Session 1 Logbook
## John Kircher, U61489057, kircherj@bu.edu
Copyright Year 2021 John Kircher

## September

### 9/19/2021 Sunday Week3

- Senior Design teams are assigned via email and blackboard announcement.
- Assigned to the VETCON BADGE Project, client: Michael Jones, jonesmlr@gmail.com
- Responded to introduction email from Derek and organized a team group chat via SMS messaging. 

### 9/21/2021 Tuesday Week3

- Met with the team outside the lecture hall before class to discuss some logistics about the project and potential ideas for projcet management (i.e, slack, trello, teams, etc.)
- Group Photos completed at the end of class. 

### 9/22/2021 Wednesday Week3

- Our team decided to use Slack to conduct work for the semester as well as Trello for project planning. 
- I added all my courses to a team Google Calendar so it makes it easier to schedule meetings
- Added important documents to the Slack channel and pinned them including:
    - Course grading and class schedule 
    - The VETCON BADGE project description
    - Contact Information, client and team

### 9/23/2021 Thursday Week3

- Added a well defined list of question to the Trello site for the client meeting that was planned for Friday, 9/24/2021.
    - Questions Added:

    - 1) What is the end/goal for the semester, besides the multiple in-progress reviews (IPR's). i.e: a prototype, models, etc.
    - 2) What is a good schedule/system for the IPR's. Are there certain days that work for your team or how/when should we meet. Zoom? In Person?
    - 3) What items will be supplied by you/ who is paying for computer equipment and devices to create a working badge? I understand each badges needs to cost less than $50 but the items supplied does not list anything? Do we have free range on what to implement?
    - 4) Could you explain specific requirements for the branding/ logo and colors on the badge? What font and text would you like and approximately where should it be on the badge and how much space is it taking up?

- Derek and Ryan are running and recording meeting for client as Julian, myself, and Carlos could not attend the proposed time.

### 9/26/2021 Sunday Week4

- Rewatched the entire client meeting video and reviewed the notes and documents that Derek and Ryan collected. (notes folder)
- Reached out team members and scheduled a meeting time to talk about next steps and the PDRR for class on Tuesday, 9/28/2021

### 9/28/2021 Tuesday Week4

- Had a PDRR tag-up meeting in the senior design lab discussing potential processors and how we can implement an OS for our badge. 
- We also decided that I would be the team-lead for the first session and the speaker for the presentation on Thursdsday. 
- Finally, set goals to have a presentation and PDRR rough draft completed before Tuesday 10/5/2021.

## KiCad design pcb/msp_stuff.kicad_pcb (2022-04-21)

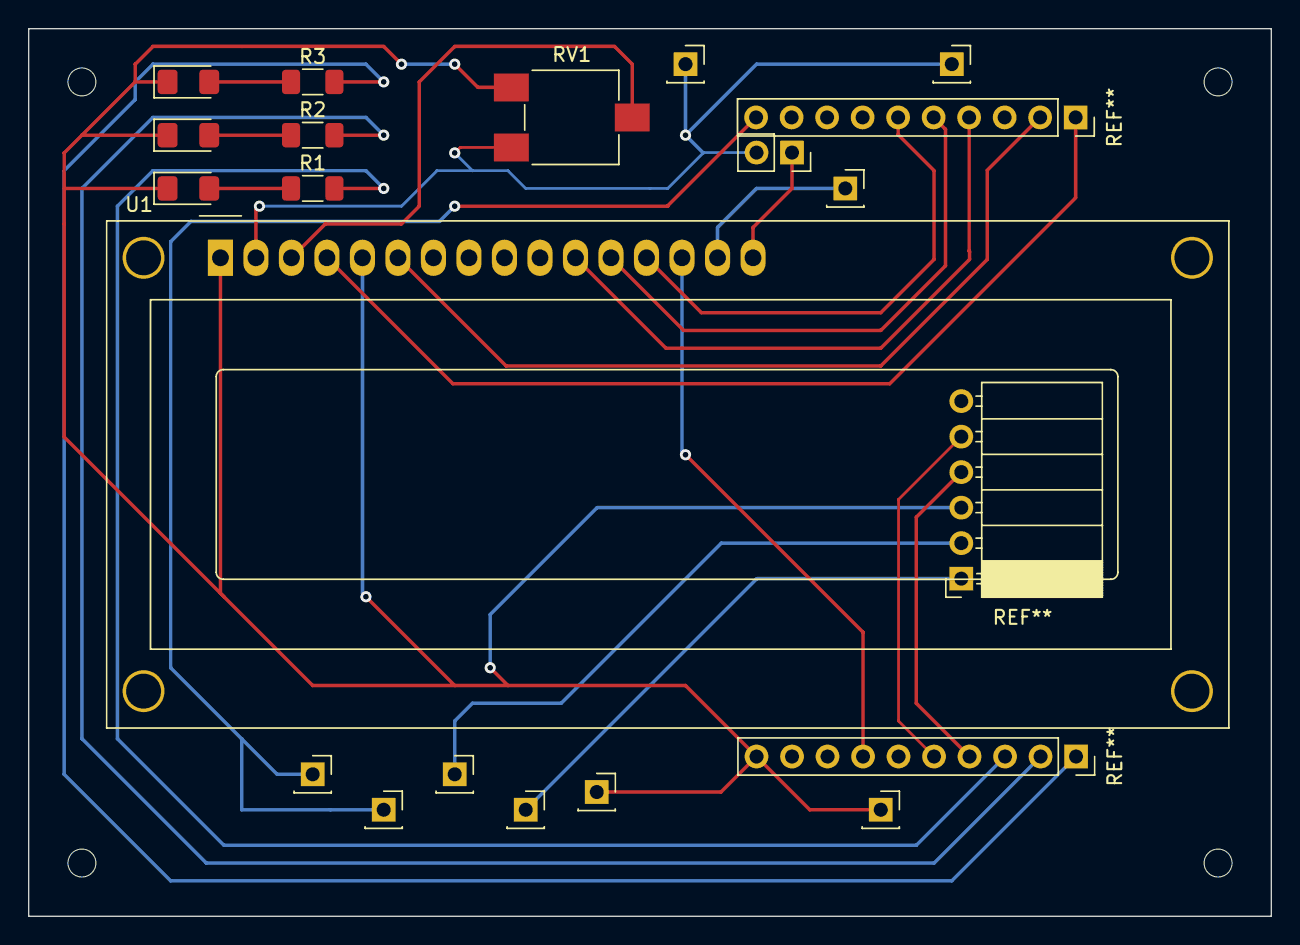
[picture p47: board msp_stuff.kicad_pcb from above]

Board: 2 copper layers, 88.9 x 63.5 mm, 8 parts (0 on the bottom side), 5 nets.

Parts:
D1, D2, D3: LED; LED_1206_3216Metric_Pad1.42x1.75mm_HandSolder
R1, R2, R3: R_Small_US; R_1206_3216Metric_Pad1.30x1.75mm_HandSolder
RV1: R_Potentiometer; Potentiometer_ACP_CA6-VSMD_Vertical
U1: RC1602A-GHW-ESX; WC1602A

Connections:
GND: D1.1 (K), D2.1 (K), D3.1 (K), RV1.3, U1.1 (VSS), U1.5 (R/~W), U1.16 (K)
unnamed: D1.2 (A), R1.1
unnamed: D2.2 (A), R2.1
unnamed: D3.2 (A), R3.1
unnamed: RV1.2, U1.3 (Vo)

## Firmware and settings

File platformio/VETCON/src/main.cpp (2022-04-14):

#include <Arduino.h>
#include <stdlib.h>
#include <string.h>
#include <Button.h>
#include <HardwareSerial.h>
#include <LiquidCrystal.h>
#define NAMESET 1
#define NAMELEN 128

/*

TX: 2.5
RX: 2.6

PUSH BUTTONS: 2.3, 2.7

LIQUID CRYSTAL: 10,  9,   7,   6,   5,   17
                1.2, 1.3, 2.4, 1.7, 1.6, 3.2

*/

// Define LiquidCrystal Object
LiquidCrystal lcd = LiquidCrystal(10, 9, 7, 6, 5, 17);

// Define PushButtons using Button.h
Button push2(PUSH2); // HARD RESET

// Define Flags to place in FRAM
int startFlag PLACE_IN_FRAM;
int secretFlag PLACE_IN_FRAM;
int nameToggle PLACE_IN_FRAM;
int secretFlag2 PLACE_IN_FRAM;
int secretFlag3 PLACE_IN_FRAM;
int secretFlag4 PLACE_IN_FRAM;
int wrongFlag PLACE_IN_FRAM;

char name[NAMELEN] PLACE_IN_FRAM;
char secret_word[NAMELEN] PLACE_IN_FRAM;

// Custom GLYPHS for 16x2 LCD go HERE:

byte Skull[8] = {
    0b00000,
    0b01110,
    0b10101,
    0b11011,
    0b01110,
    0b01110,
    0b00000,
    0b00000};

// Function Prototypes

void clearStr();

void setName();

void mainMenu();

void setStr();

void displayName();

void secret();

void resetBadge();

void secretCode2();

void secretCode();

void secretCode3();

void wipeBoard();

void bluetooth();

void bleName();

void blePassword();

void ledMenu();

void ledWave();

void ledBlink();

void ledAlt();

void interrupt();

void writeString(String s);

void clearStr(char *str);

void setStr(String x, char *str);

void lcdCheck();

void setup()
{
  // put your setup code here, to run once:

  // Set Up Push Buttons and LCD
  push2.begin();

  lcd.begin(16, 2);

  // Set Up Serial Parameters, BT Serial, and timeouts
  Serial.begin(9600);
  Serial1.begin(9600);
  //Serial1.begin(38400);
  Serial.setTimeout(2000);

  // Set Up Pins for LEDs 1, 2 & 3 (in-order)
  pinMode(P3_1, OUTPUT);
  pinMode(P2_1, OUTPUT);
  pinMode(P2_0, OUTPUT);

  // Set Up Custom Characters
  lcd.createChar(0, Skull);
}

// String Set/Clear/Write functions for BT Serial/Serial Comms

void clearStr(char *str)
{
  for (int i = 0; i < NAMELEN; i++)
    str[i] = '\0';
}

void setStr(String x, char *str)
{
  char new_name[NAMELEN];
  x.toCharArray(new_name, NAMELEN);
  for (int i = 0; i < NAMELEN; i++)
    str[i] = new_name[i];
}

void writeString(String stringData)
{ // Used to serially push out a String with Serial.write()

  for (int i = 0; i < 15; i++)
  {
    Serial1.write(stringData[i]); // Push each char 1 by 1 on each loop pass
  }
}

// Function to check if enabled secret prompts LED on/off

void ledCheck()
{
  if (secretFlag2 == 1)
  {
    digitalWrite(P3_1, secretFlag2);
  }
  else if (secretFlag2 == 0)
  {
    digitalWrite(P3_1, secretFlag2);
  }
  if (secretFlag3 == 1)
  {
    digitalWrite(P2_1, secretFlag3);
  }
  else if (secretFlag3 == 0)
  {
    digitalWrite(P2_1, secretFlag3);
  }
  if (secretFlag4 == 1)
  {
    digitalWrite(P2_0, secretFlag4);
  }
  else if (secretFlag4 == 0)
  {
    digitalWrite(P2_0, secretFlag4);
  }
}

// Check and 'rebase' the lcd

void lcdCheck()
{
  lcd.clear();
  if (nameToggle == NAMESET)
  {
    lcd.setCursor(2, 0);
    lcd.write(byte(0));
    lcd.print("VETCON  30");
    lcd.write(byte(0));
    lcd.setCursor(0, 1);
    lcd.print(name);
  }
  else
  {
    lcd.setCursor(2, 0);
    lcd.write(byte(0));
    lcd.print("WELCOME TO");
    lcd.write(byte(0));
    lcd.setCursor(2, 1);
    lcd.write(byte(0));
    lcd.print("VETCON  30");
    lcd.write(byte(0));
  }
}

// Main Menu selection function

void mainMenu()
{

statement:
  Serial.print("************************\n");
  Serial.print("*|        MENU        |*\n");
  Serial.print("*|                    |*\n");
  Serial.print("*| 1: Set Name Tag    |*\n");
  Serial.print("*| 2: Display Name Tag|*\n");
  Serial.print("*| 3: Game Link       |*\n");

  Serial.print("*| 4: Game Link 2     |*\n");
  if (secretFlag == 1)
  {
    Serial.print("*| 5: Secret Token    |*\n");
  }
  if (secretFlag == 1 && secretFlag2 == 1)
  {
    Serial.print("*| 6: Secret Token 2  |*\n");
  }
  if (secretFlag == 1 && secretFlag2 == 1 && secretFlag3 == 1)
  {
    Serial.print("*| 7: Secret Token 3  |*\n");
  }
  Serial.print("*| 8: Start Bluetooth |*\n");
  if (secretFlag == 1 && secretFlag2 == 1 && secretFlag3 == 1 && secretFlag4 == 1)
  {
    Serial.print("*| 9: LED CNTRL Menu  |*\n");
  }
  Serial.print("*| 0: Reset Badge     |*\n");
  Serial.print("*|                    |*\n");
  Serial.print("************************\n");

  Serial.print("Please enter input\n");

  while (Serial.available() == 0)
  {
    // THIS BLOCK STAYS EMPTY!
  }
  char inputData = (char)Serial.read();
  Serial.print("Input: ");
  Serial.print(inputData);
  Serial.print("\n\n");
  Serial.flush();

  for (;;)
  {
    switch (inputData)
    {
    case '1':
      sleepSeconds(1);
      Serial.print("You Chose to Set your Device Name!\n"); // DeviceID Input
      sleepSeconds(1);
      if (nameToggle == 0)
      {
        Serial.print("Jumping to setName...\n");
        sleepSeconds(1);
        setName();
      }
      else if (nameToggle == NAMESET)
      {
        Serial.print("YOU ALREADY SET YOUR NAME\n");
        Serial.print("Name: ");
        Serial.print(name);
        Serial.print("\n");
        Serial.print("Would you like to change your name?\n");
        sleepSeconds(1);
        Serial.print("PLEASE PRESS '1' FOR YES, '2' FOR NO\n");

        while (Serial.available() == 0)
        {
          // THIS BLOCK STAYS EMPTY!
        }
        char inputData = (char)Serial.read();
        Serial.print("Input: ");
        Serial.print(inputData);
        Serial.print("\n\n");
        if (inputData == '1')
        {
          Serial.print("Jumping to setName...\n");
          sleepSeconds(1);
          setName();
        }
        sleepSeconds(1);
      }
      sleepSeconds(1);
      goto statement;
    case '2':
      sleepSeconds(1);
      Serial.print("You Chose to Display your Device Name!\n"); // DeviceID Input
      sleepSeconds(1);
      Serial.print("Displaying Device Name on Badge\n");
      sleepSeconds(1);
      Serial.print(name);
      Serial.print("\n");
      displayName();
      goto statement;
    case '3':
      sleepSeconds(1);
      Serial.print("You Chose to Play Game 1!\n"); // Game Link
      sleepSeconds(1);
      Serial.print("URL:\n");
      Serial.print("shorturl.at/advFT\n");
      sleepSeconds(1);
      goto statement;
    case '5':
      sleepSeconds(1);
      if (secretFlag == 0)
      {
        Serial.print("Access Denied\n");
        goto statement;
      }
      else
      {
        if (secretFlag2 == 1)
        {
          Serial.print("Secret already unlocked\n");
          goto statement;
        }
        secretCode();
        goto statement;
      }
    case '4':
      sleepSeconds(1);
      Serial.print("You Chose to Play the Game 2!\n"); // Game Link
      sleepSeconds(1);
      Serial.print("URL:\n");
      Serial.print("shorturl.at/lxIL6\n");
      sleepSeconds(1);
      goto statement;
    case '6':
      sleepSeconds(1);
      if (secretFlag == 0 || secretFlag2 == 0)
      {
        Serial.print("Access Denied\n");
        goto statement;
      }
      else
      {
        if (secretFlag3 == 1)
        {
          Serial.print("Secret already unlocked\n");
          goto statement;
        }
        secretCode2();
        goto statement;
      }

    case '7':
      sleepSeconds(1);
      if (secretFlag == 0 || secretFlag2 == 0 || secretFlag3 == 0)
      {
        Serial.print("Access Denied\n");
        goto statement;
      }
      else
      {
        if (secretFlag4 == 1)
        {
          Serial.print("Secret already unlocked\n");
          goto statement;
        }
        secretCode3();
        goto statement;
      }

    case '8':
      sleepSeconds(1);
      Serial.print("Bluetooth Entered\n");
      Serial.print("Exit Bluetooth Menu to Return\n\n\n");
      bluetooth();
      goto statement;
    case '9':
      sleepSeconds(1);
      if (secretFlag == 1 && secretFlag2 == 1 && secretFlag3 == 1 && secretFlag4 == 1)
      {
        Serial.print("Entering the LED Control Menu!\n\n");
        ledMenu();
        sleepSeconds(1);
      }
      else if (secretFlag == 1)
      {
        Serial.print("Secret 1 Already Unlocked\n\n");
        sleepSeconds(1);
      }
      else
      {
        secret();
        sleepSeconds(1);
      }
      goto statement;

    case '0':
      // Set Up Push Buttons

      sleepSeconds(1);
      resetBadge();
      if (startFlag == 1)
      {
        goto statement;
      }
      else
      {
        return;
      }

    default:
      Serial.print("Invalid Statement\n");
      goto statement;
    }
  }
}

// Wireless/BT COMM function

void bluetooth()
{

statement:
  Serial.print("Welcome to Bluetooth\n");
  Serial.print("Type 1 to Start Communication: \n");
  Serial.print("Type 2 to Change to Parent/Child\n");
  Serial.print("Type 0 to Exit: \n");
  while (Serial.available() == 0)
  {
    // THIS BLOCK STAYS EMPTY!
  }
  char inputData = (char)Serial.read();
  Serial.print("You entered ");
  Serial.print(inputData);
  Serial.flush();
  Serial.print("\n\n");
  // char badgePassowrd[] = "AT+PSWD=";
  // strcat(badgePassowrd,inputData.c_str());

  for (;;)
  {
    switch (inputData)
    {
    case '1':
    {
      sleep(100);
      Serial.print("Type to send to other badge\n");
      Serial.print("Type 'exitnowpls' to quit!\n");
      while (Serial.available() == 0)
      {
        // THIS BLOCK STAYS EMPTY!
      }
      String toSend = Serial.readString();
      if (toSend == "exitnowpls")
      {
        Serial.print("Exiting now!\n");
        sleepSeconds(1);
        return;
      }

      // Serial.print("got inside case 1\n");
      Serial.print("Sending Data via Bluetooth...\n");
      writeString(toSend);
      Serial.flush();

      if (Serial1.available())
      {
        // Serial.print("got inside Serial1\n");
        // String incomingData = Serial1.readString();
        String dataIn = Serial1.readString();

        // Serial.print(incomingData);
        Serial.print("Data Received: ");
        Serial.print(dataIn);
        Serial.print("\n");
      }
      break;
    }
    case '2':
    {
      
      delay(100);
      Serial.print("COMMANDS:\n");
      Serial.print("Type: AT+ROLE=0 for child\n");
      Serial.print("Type: AT+ROLE=1 for parent\n\n");
      Serial.print("Type 'exitnowpls' to quit!\n");
      while (Serial.available() == 0)
      {
        // THIS BLOCK STAYS EMPTY!
      }
      String toSend = Serial.readString();
      if (toSend == "exitnowpls")
      {
        Serial.print("Exiting now!\n");
        return;
      }

      Serial.print("Sending Command...\n");
      writeString(toSend);

      if (Serial1.available())
      {
        Serial.print("got inside Serial1\n");
        // String incomingData = Serial1.readString();
        String dataIn = Serial1.readString();

        // Serial.print(incomingData);
        Serial.print("Data Received: ");
        Serial.print(dataIn);
        Serial.print("\n");
      }
      break;
    }
    case '0':
      sleepSeconds(1);
      return;
    default:
      Serial.print("Invalid Menu Item\n");
      goto statement;
    }
  }
}

// Badge Reset, CLEAR FRAM and LCD

void resetBadge()
{
  Serial.print("Reset Badge:\n");
  sleepSeconds(1);
  Serial.print("ARE YOU SURE YOU WANT TO RESET?\n");
  Serial.print("ALL SECRET PROGRESS WILL BE LOST\n\n");
  Serial.print("Please Press & Hold Button 1 for reset\n");
  Serial.print("Otherwise, wait 5 seconds! (after this message)\n");

  sleep(200);
  while (true)
  {
    sleepSeconds(5);
    if (push2.pressed())
    {
      Serial.print("RESETTING.....\n");
      sleepSeconds(3);
      wipeBoard();
      Serial.print("BADGE RESET\n");
      break;
    }
    else
    {
      Serial.print("Badge Reset Aborted...\n");
      break;
    }
  }
}

// Badge Secret Functions

void secret()
{
  Serial.print("Secret Unlocked\n");
  SYSCFG0 = FRWPPW | DFWP;
  secretFlag = 1;
  SYSCFG0 = FRWPPW | PFWP | DFWP;
  return;
}

void secretCode()
{

  char answer[] = "1016";
  Serial.print("Please Enter The Secret Code:\n");
  while (Serial.available() == 0)
  {
    // THIS BLOCK STAYS EMPTY!
  }
  String inputData = Serial.readStringUntil('\n');
  if (inputData == answer)
  {
    Serial.print("CONGRATS! SECRET 1 SOLVED\n");

    SYSCFG0 = FRWPPW | DFWP;
    secretFlag2 = 1;
    SYSCFG0 = FRWPPW | PFWP | DFWP;
    digitalWrite(P3_1, secretFlag2);
  }
  else
  {
    Serial.print("INCORRECT CODE\n");
  }
  return;
}

void secretCode2()
{
  char answer[] = "semperdisco";
  char wrong[] = "3411323115333443242344234424521532244442453454141544431152543131111542453454";
  Serial.print("Please Enter The Secret Code:\n");
  while (Serial.available() == 0)
  {
    // THIS BLOCK STAYS EMPTY!
  }
  String inputData = Serial.readStringUntil('\n');
  if (inputData == answer)
  {
    Serial.print("CONGRATS! SECRET 2 SOLVED\n");

    SYSCFG0 = FRWPPW | DFWP;
    secretFlag3 = 1;
    SYSCFG0 = FRWPPW | PFWP | DFWP;
    digitalWrite(P2_1, secretFlag3);
  }
  else if (inputData == wrong)
  {
    for (int i = 0; i < 50; i++)
    {
      Serial.print("THIS IS NOT A GAME\n");
    }
    SYSCFG0 = FRWPPW | DFWP;
    clearStr(secret_word);
    // setStr(x, secret_word);
    wrongFlag = 1;
    SYSCFG0 = FRWPPW | PFWP | DFWP;
    wipeBoard();
  }
  else
  {
    Serial.print("INCORRECT CODE\n");
  }
  return;
}

void secretCode3()
{
  char answer[] = "ilovevetcon";
  Serial.print("Please Enter the Secret Code:\n");

  while (Serial.available() == 0)
  {
    // THIS BLOCK STAYS EMPTY!
  }
  String inputData = Serial.readStringUntil('\n');
  if (inputData == answer)
  {
    Serial.print("CONGRATS! SECRET 3 SOLVED\n");

    SYSCFG0 = FRWPPW | DFWP;
    secretFlag4 = 1;
    SYSCFG0 = FRWPPW | PFWP | DFWP;
    digitalWrite(P2_0, secretFlag4);
  }
  else
  {
    Serial.print("INCORRECT CODE\n");
  }
  return;
}

// LED Functions

void ledWave()
{
  for (;;)
  {
    lcd.scrollDisplayLeft();
    digitalWrite(P3_1, HIGH); // Turn LED 1 on
    sleep(600);               // wait half a second
    lcd.scrollDisplayLeft();
    digitalWrite(P3_1, LOW);  // Turn LED 1 off
    digitalWrite(P2_1, HIGH); // and repeat for LED 2 to 5
    sleep(600);
    lcd.scrollDisplayLeft();
    digitalWrite(P2_1, LOW);
    digitalWrite(P2_0, HIGH); // and repeat for LED 2 to 5
    sleep(600);
    lcd.scrollDisplayLeft();
    digitalWrite(P2_0, LOW);
    sleep(200);
    if (push2.pressed())
    {
      break;
    }
  }
  return;
}

void ledBlink()
{
  for (;;)
  {
    lcd.scrollDisplayLeft();
    digitalWrite(P3_1, HIGH);
    lcd.scrollDisplayLeft();
    digitalWrite(P2_1, HIGH);
    lcd.scrollDisplayLeft();
    digitalWrite(P2_0, HIGH);
    lcd.scrollDisplayLeft();
    sleep(600);
    lcd.scrollDisplayLeft();
    digitalWrite(P3_1, LOW);
    lcd.scrollDisplayLeft();
    digitalWrite(P2_1, LOW);
    lcd.scrollDisplayLeft();
    digitalWrite(P2_0, LOW);
    lcd.scrollDisplayLeft();
    sleep(400);
    if (push2.pressed())
    {
      break;
    }
  }
  return;
}

void ledAlt()
{
  for (;;)
  {
    lcd.scrollDisplayLeft();
    digitalWrite(P3_1, HIGH);
    lcd.scrollDisplayLeft();
    digitalWrite(P2_1, LOW);
    lcd.scrollDisplayLeft();
    digitalWrite(P2_0, HIGH);
    lcd.scrollDisplayLeft();
    sleep(1500);
    lcd.scrollDisplayLeft();
    digitalWrite(P3_1, LOW);
    lcd.scrollDisplayLeft();
    digitalWrite(P2_1, HIGH);
    lcd.scrollDisplayLeft();
    digitalWrite(P2_0, LOW);
    lcd.scrollDisplayLeft();
    sleep(500);
    if (push2.pressed())
    {
      break;
    }
  }
  return;
}

// LED Menu

// TODO: MAKE SURE WE CAN INTERRUPT AND MAINTAIN LED FUNCTIONALITY AT SAME TIME
//  LOOK INTO INTERRUPT + GO TO COMBINATION FOR INTERRUPT STARTUP ROUTINE

void ledMenu()
{
  for (int i; i < 10; i++)
  {
    Serial.print("\r");
  }

  Serial.print("Welcome to the LED Control Menu! \n\n");
ledprompt:

  lcdCheck();
  ledCheck();

  Serial.print("Option 5 will return you to the Main Menu \n\n");
  Serial.print("Otherwise, press & hold Button 1 \n\n");

  Serial.print("************************\n");
  Serial.print("*|        MENU        |*\n");
  Serial.print("*|                    |*\n");
  Serial.print("*| 1: Turn LEDs OFF   |*\n");
  Serial.print("*| 2: LED 'WAVE'      |*\n");
  Serial.print("*| 3: LED 'BLINK'     |*\n");
  Serial.print("*| 4: LED 'ALTERNATE' |*\n");
  Serial.print("*| 5: Back 2 Main Menu|*\n");
  Serial.print("*|                    |*\n");
  Serial.print("************************\n");

  Serial.print("Please enter input\n");

  while (Serial.available() == 0)
  {
    // THIS BLOCK STAYS EMPTY!
  }
  char inputData = (char)Serial.read();
  Serial.print("Input: ");
  Serial.print(inputData);
  Serial.print("\n\n");
  Serial.flush();

  switch (inputData)
  {
  case '1':
    Serial.print("Entering deep sleep, press the Reset button to wake!\n\n");
    digitalWrite(P3_1, 0);
    digitalWrite(P2_1, 0);
    digitalWrite(P2_0, 0);
    suspend();
    goto ledprompt;
  case '2':
    lcd.setCursor(2, 0);
    ledWave();
    goto ledprompt;
  case '3':
    lcd.setCursor(2, 0);
    ledBlink();
    goto ledprompt;
  case '4':
    lcd.setCursor(2, 0);
    ledAlt();
    goto ledprompt;
  case '5':
    return;
  default:
    goto ledprompt;
  }
  return;
}

// LCD Name Display

void displayName()
{
  lcd.clear();

  lcd.setCursor(2, 0);
  lcd.write(byte(0));
  lcd.print("VETCON  30");
  lcd.write(byte(0));

  lcd.setCursor(0, 1);
  if (nameToggle == NAMESET)
  {

    lcd.print(name);
  }
  else
  {
    Serial.print("ERROR: NAME NOT SET\n");
  }

  return;
}

// Name Set
void setName()
{
  Serial.print("Please Enter A Name:\n");
  while (Serial.available() == 0)
  {
    // THIS BLOCK STAYS EMPTY!
  }

  String inputData = Serial.readStringUntil('\n');

  char secretString2[] = "Senior Design";
  char secretAnswer2[] = "\n   _____            _               ____            _           \n  / ___/___  ____  (_)___  _____   / __ \\___  _____(_)___ _____ \n  \\__ \\/ _ \\/ __ \\/ / __ \\/ ___/  / / / / _ \\/ ___/ / __ `/ __ \\ \n ___/ /  __/ / / / / /_/ / /     / /_/ /  __(__  ) / /_/ / / / /\n/____/\\___/_/ /_/_/\\____/_/     /_____/\\___/____/_/\\__, /_/ /_/ \n                                                  /____/        \n";

  if (inputData == secretString2)
  {
    Serial.print(secretAnswer2);
  }

  Serial.print("You entered ");
  Serial.print(inputData);
  SYSCFG0 = FRWPPW | DFWP;
  setStr(inputData, name);
  nameToggle = NAMESET;
  SYSCFG0 = FRWPPW | PFWP | DFWP;
  Serial.print("\n");
  Serial.flush();
  sleepSeconds(1);
  return;
}

// Board Wipe function specifically for 'red herring' key

void wipeBoard()
{
  SYSCFG0 = FRWPPW | DFWP;
  startFlag = 0;
  secretFlag = 0;
  nameToggle = 0;
  secretFlag2 = 0;
  secretFlag3 = 0;
  secretFlag4 = 0;
  wrongFlag = 0;
  lcd.clear();
  clearStr(name);
  SYSCFG0 = FRWPPW | PFWP | DFWP;

  return;
}

// Main function "loop"
void loop()
{
  // put your main code here, to run repeatedly:
  lcdCheck();
  ledCheck();
  sleepSeconds(2);
  const char *welcome[] = {
      "*****************BEWARE*******************",
      "*****************THERE********************",
      "******************IS**********************",
      "***************NO*ESCAPE******************",
      "╭╮╭╮╭┳━━━┳╮╱╱╭━━━┳━━━┳━╮╭━┳━━━╮╭━━━━┳━━━╮",
      "┃┃┃┃┃┃╭━━┫┃╱╱┃╭━╮┃╭━╮┃┃╰╯┃┃╭━━╯┃╭╮╭╮┃╭━╮┃",
      "┃┃┃┃┃┃╰━━┫┃╱╱┃┃╱╰┫┃╱┃┃╭╮╭╮┃╰━━╮╰╯┃┃╰┫┃╱┃┃",
      "┃╰╯╰╯┃╭━━┫┃╱╭┫┃╱╭┫┃╱┃┃┃┃┃┃┃╭━━╯╱╱┃┃╱┃┃╱┃┃",
      "╰╮╭╮╭┫╰━━┫╰━╯┃╰━╯┃╰━╯┃┃┃┃┃┃╰━━╮╱╱┃┃╱┃╰━╯┃",
      "╱╰╯╰╯╰━━━┻━━━┻━━━┻━━━┻╯╰╯╰┻━━━╯╱╱╰╯╱╰━━━╯",
      "╭╮╱╱╭┳━━━┳━━━━┳━━━┳━━━┳━╮╱╭╮",
      "┃╰╮╭╯┃╭━━┫╭╮╭╮┃╭━╮┃╭━╮┃┃╰╮┃┃",
      "╰╮┃┃╭┫╰━━╋╯┃┃╰┫┃╱╰┫┃╱┃┃╭╮╰╯┃",
      "╱┃╰╯┃┃╭━━╯╱┃┃╱┃┃╱╭┫┃╱┃┃┃╰╮┃┃",
      "╱╰╮╭╯┃╰━━╮╱┃┃╱┃╰━╯┃╰━╯┃┃╱┃┃┃",
      "╱╱╰╯╱╰━━━╯╱╰╯╱╰━━━┻━━━┻╯╱╰━╯",
      "******************************************",
      "******************************************",
      "******************************************",
      "******************************************",
  };

  if (startFlag == 0)
  { // On display welcome on startup, never again.
    for (int idx = 0; idx < sizeof(welcome) / sizeof(char); idx++)
    {
      Serial.print(welcome[idx]);
      Serial.print("\n");
    }
    SYSCFG0 = FRWPPW | DFWP;
    startFlag = 1;
    SYSCFG0 = FRWPPW | PFWP | DFWP;
  }

  mainMenu();
}

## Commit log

2021-10-26 Created, debugged, built and flashed a MSP430FR2433 hello world program that blinks an LED
2021-11-02 cleaned up stuff. Deleted old objects and cloned samples of bootloader into repo
2021-11-11 initialize menu control structure
    [GUI_JSON.obj, HAL_GUIComm_UART_FR243x.obj, HAL_IO_FR243x.obj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]
2021-11-13 prototype progress
2021-11-14 Update main.cpp
    Added Reset Option, included a secret, utilized buttons for secret menu. Added option 4 and 9 to menu.
    [main.cpp]
2021-11-15 got button pushes working
2021-11-16 added button functionality
2021-11-16 Prototype Code, Ready For Testing
2022-02-22 Updated flags for games 1 & 2, added led functionality
2022-02-24 forgot to push the .tsv file
    [game_scenes.tsv]
2022-03-01 led checks updated
2022-03-01 edited .tsv
    [game_scenes.tsv]
2022-03-01 prototype is ready 2 go
2022-03-03 forgot to push new .tsv
    [game_scenes.tsv]
2022-03-03 removing CCStudio SRC library
    [GUI_JSON.obj, HAL_GUIComm_UART_FR243x.obj, HAL_IO_FR243x.obj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]
2022-03-31 forgot to push changes last night, interrupt progress + logbook update
2022-03-31 having trouble with LED Menu controls and interrupt with push buttons
2022-03-31 Bluetooth Switches Working
2022-04-01 logbok + attempt to fix push2
    [main.cpp]
2022-04-04 refactors, LED menu complete, sleep mode in operation succesfully
2022-04-14 cmake cross compilation
    [game_scenes.tsv]
2022-04-15 restructuring folders, moving text_based game to root dir
    [game_scenes.tsv]
2022-04-15 adding pcb files to github
    [msp_stuff-B_Cu.gbl, msp_stuff-B_Mask.gbs, msp_stuff-B_Paste.gbp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]
2022-04-20 github mgmt and readme changes
    [Game 3 choices_consequences.xlsx, SeniorDesignGanttChart.xlsx]
2022-04-20 continued restructuring of repo, commencing the 'pruning' of old branches
    [game_scenes.tsv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]
2022-04-21 update bluetooth buttons
    [msp_stuff.kicad_pcb]
2022-04-21 adding a pcb enclosure folder to track .stl files
    [protoboard_case.stl]
2022-04-21 fix screen and bluetooth
    [msp_stuff.kicad_pcb]
2022-04-21 updated fab files for jlcpcb
    [msp_stuff-B_Cu.gbr, msp_stuff-B_Mask.gbr, msp_stuff-B_Paste.gbr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]
2022-04-28 added power supply constraints :)
2022-04-29 adding PCB purchase instructions
2022-04-29 adding final STL enclosure, finishing touches on HW report
    [pcb_case.stl]
2022-05-01 including one more item in BOM
2022-05-06 final STL case
    [pcb_case.stl, pcb_enclosure_final.stl]
